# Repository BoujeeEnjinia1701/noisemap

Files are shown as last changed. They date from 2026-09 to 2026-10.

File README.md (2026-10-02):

# NoiseMap

     

**Area:** Smart Cities · **TRL:** 3 of 9 (proof of concept on paper) · **Value-engineering target:** $100 USD for the NoiseMap parts, estimated $72 (FieldNode core costed separately) · **Difficulty:** 2 of 5

A sound level meter node that records decibel levels only, never audio, to map traffic and nightlife noise.

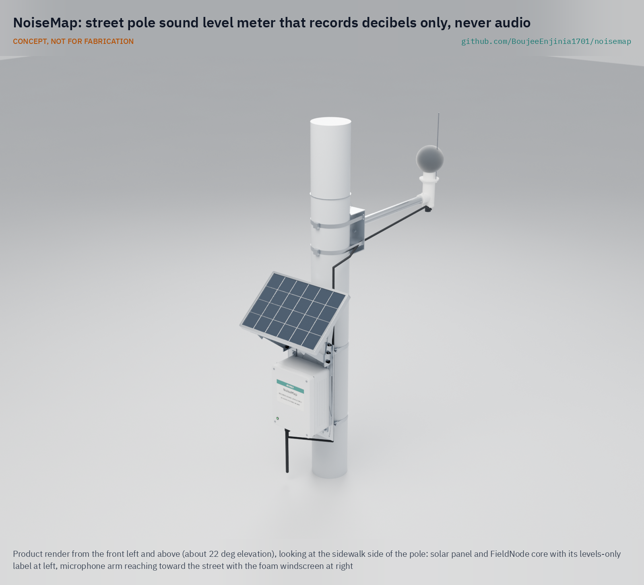
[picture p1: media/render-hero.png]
NoiseMap: street pole sound level meter that records decibels only, never audio, product render


[Exploded render](media/render-exploded.png) · [Detail render](media/render-detail.png) · [Interactive 3D model](media/viewer.html) · [Concept blueprint (PDF)](media/concept-blueprint.pdf) · [General arrangement NSM-DWG-001 (PDF)](cad/drawings/NSM-DWG-001.pdf) · [Calculations NSM-CAL-001](docs/04-calcs/01-sizing.md) · [Prototype build plan](docs/05-build-plan.md) · [Design decisions](docs/06-design-decisions.md) · [Review note](docs/REVIEW.md)

## Concept rationale

Most noise disputes turn on one question: how loud was it, and when? A sound level meter answers that with a few numbers per second; it does not need to keep any sound. NoiseMap puts a digital MEMS microphone and a small processor in a head about 4 m above the street, turns the sound into A- and C-weighted levels on the spot, and passes only those levels to the lab's standard FieldNode solar and LoRaWAN core. The head firmware sends levels only, and it is open and published with a build hash, so residents, venues and the city can check for themselves that the street is not being listened to.

It is open and garage-buildable because the people who most need the evidence, residents' groups and small city noise teams, cannot buy certified monitoring terminals by the dozen. A MEMS microphone, a microcontroller board, a printed housing, a foam windscreen, an arm and a street pole adapter cost about $72 on top of the FieldNode core, and the open firmware lets anyone check that the node measures levels and nothing else.

## Burning platform

Noise is one of the largest environmental health burdens in cities. In the EU about 92 million people are exposed to harmful road traffic noise, and long-term transport noise is linked to about 66,000 premature deaths and about 50,000 new cases of cardiovascular disease a year ([EEA](https://www.eea.europa.eu/en/topics/in-depth/noise)). The WHO recommends keeping road traffic noise below 53 dB Lden and 45 dB Lnight ([EEA, citing WHO 2018](https://www.eea.europa.eu/publications/health-risks-caused-by-environmental)), stricter than the 55 dB Lden threshold used for EU reporting.

Yet official noise maps are mostly modeled and, in the EU, reviewed only every five years ([Directive 2002/49/EC](https://eur-lex.europa.eu/legal-content/EN/TXT/HTML/?uri=CELEX:32002L0049)), while complaints pile up without measurements behind them. By 2018 New York City's 311 line had logged more than 2.3 million noise complaints since 2010, more than for any other issue ([Bello et al., *Communications of the ACM*, 2018](https://arxiv.org/pdf/1805.00889)).

## Where it could be used

### By industry

| Industry | Use |
| --- | --- |
| Municipal environmental health | Continuous levels to check complaints and target enforcement in nightlife districts |
| Transport and road authorities | Before and after evidence for speed limits, low-noise surfaces and truck routes |
| Hospitality licensing and night-time economy | Shared, trusted data for late-licence conditions between venues and residents |
| Construction | Monitoring agreed noise limits at site boundaries near homes |
| Public health research | Open level data linked to sleep and cardiovascular studies |
| Community groups and citizen science | Independent, inspectable evidence for council meetings and planning hearings |

### By country or region

| Country or region | Why it matters there |
| --- | --- |
| European Union | About 92 million people are exposed to harmful road traffic noise ([EEA](https://www.eea.europa.eu/en/topics/in-depth/noise)); strategic maps are modeled and updated every five years, so street-level measurements add what the maps miss. |
| United States | The EPA set 55 dB outdoors as the level that prevents interference and annoyance in 1974 ([US EPA](https://www.epa.gov/archive/epa/aboutepa/epa-identifies-noise-levels-affecting-health-and-welfare.html)); noise was New York City's most common 311 complaint when SONYC was described in 2018 ([Bello et al.](https://arxiv.org/abs/1805.00889)). |
| France (Paris region) | Bruitparif already deploys sensors in lively Paris neighborhoods and on construction sites ([Bruitparif](https://www.bruitparif.fr/la-meduse/)); an open, low-cost node could extend coverage to smaller towns. |
| India | The national real-time noise network launched in 2011 with 35 stations in seven metros, five terminals per city, with expansion to 25 cities planned ([Press Information Bureau, Government of India](https://www.pib.gov.in/newsite/erelcontent.aspx?relid=71212&reg=3&lang=2)); a few fixed terminals per city leave most streets unmeasured. |
| Sub-Saharan Africa (Nigeria) | The UN Environment Programme lists Ibadan among the cities worldwide where acceptable noise levels are surpassed ([UNEP, Frontiers 2022](https://www.unep.org/news-and-stories/press-release/deadly-wildfires-noise-pollution-and-disruptive-timing-life-cycles)); a low-cost open node can give such cities measured data. |
| Southeast Asia (Thailand, Vietnam) | Bangkok and Ho Chi Minh City are also on UNEP's list of cities where acceptable noise levels are surpassed ([UNEP, Frontiers 2022](https://www.unep.org/news-and-stories/press-release/deadly-wildfires-noise-pollution-and-disruptive-timing-life-cycles)). |

## What sparked the idea

The idea traces back to Stratumseind, a nightlife street in Eindhoven, the Netherlands, which the municipality and the Dutch Institute for Technology, Safety & Security (DITSS), with the police and local businesses, turned into a living lab. The lab tested acoustic sensors that locate breaking glass and fireworks and recognize voices under high stress, to spot rising aggression ([The Hague Security Delta](https://securitydelta.nl/services/innovation/living-labs/stratumseind)). Leon Verver, director of DITSS, said, "We are not listening in on people or record what they're saying" ([The Next Web, 2018](https://thenextweb.com/the-next-police/2018/06/08/1128392/)). People on the street had to take that on trust, and legal research on the lab argued that such collective monitoring can still limit what individuals do, even without identifying anyone ([Galič, *Ars Aequi*, 2019](https://www.researchgate.net/publication/333673572_Surveillance_privacy_and_public_space_in_the_Stratumseind_Living_Lab_the_smart_city_debate_beyond_data)). NoiseMap starts from the opposite end: measure loudness only, and publish the firmware so that residents can check the claim instead of trusting it.

## Problem

Noise harms sleep and health, but cities measure it rarely and residents' complaints lack data. Official maps are modeled averages, certified monitors are few and costly, and any microphone on a pole raises the fear of eavesdropping.

## Concept

A sound level meter node that records decibel levels only, never audio, to map traffic and nightlife noise.

Full design precis: [docs/02-concept.md](docs/02-concept.md)

TRL 3 calculations ([NSM-CAL-001](docs/04-calcs/01-sizing.md), paper estimates): 12.2 mW average draw, 53 days without sun on the standard FieldNode cell, a measuring range of 34.9 to 113 dBA (27.9 dBA at the low end with the IM72D128 microphone), a 22-byte record every 15 minutes, an estimated $72 of NoiseMap parts against a $100 value-engineering target and about $211 for a full node with the FieldNode core. Made constructable (sawn V-blocks, a bent sheet arm saddle with two bands, fixings throughout), the node weighs 3.45 kg, within the 3.5 kg of R10 (relaxed from 3 kg), and an automatic interval rule keeps airtime within fair use at slow data rates; accuracy, measuring range and frequency response remain at risk. See the [requirements](docs/03-requirements.md) and the decision records [NSM-DDR-001](docs/decisions/0001-trl2-review-decisions.md), [NSM-DDR-002](docs/decisions/0002-recommendations-accepted.md) and [NSM-DDR-003](docs/decisions/0003-design-for-construction.md).

## Key components

- Digital MEMS microphone on an adapter board that takes an ICS-43434 or an IM72D128, in a printed head, pointing up
- Level processor in the head computing A- and C-weighted levels once a second; audio stays in its RAM
- Standard FieldNode core: IP65 enclosure, 6 W panel, one LiFePO4 cell, MPPT charger and LoRaWAN radio
- 90 mm foam windscreen with bird spike
- Aluminum arm on a bent sheet saddle with its own two band clamps, and street pole V-blocks for 60 to 140 mm poles that fit the FieldNode back plate; no drilling of the pole

The priced bill of materials is in [bom/bom.csv](bom/bom.csv); the parametric model is [cad/src/model.py](cad/src/model.py), with STEP files in `cad/step/`.

## Building the prototype

The [prototype build plan](docs/05-build-plan.md) (NSM-BLD-001) shows how to make each component and fit it to the next, with a making sketch for every made part and a picture for every assembly step. The FieldNode core is built to its own plan and gets two larger V-blocks sawn from aluminium bar in place of its own; the arm saddle is bent from sheet by a local shop; the head and its cap are printed in ASA; the rest is bought. The work needs basic metalwork, 3D printing and fine soldering, and no certified trade. Every decision is indexed in the [design decisions register](docs/06-design-decisions.md).

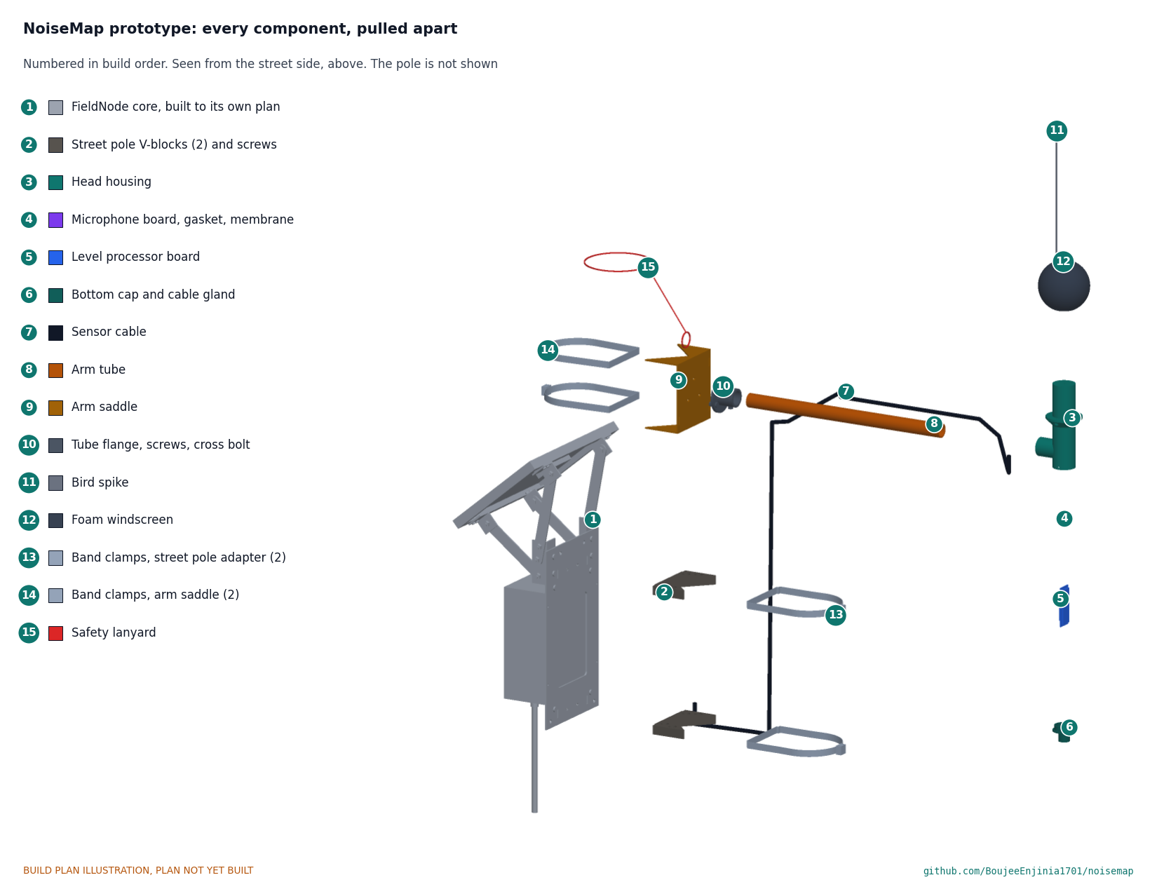
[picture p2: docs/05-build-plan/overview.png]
NoiseMap prototype: every component pulled apart and numbered in build order


## Safety

> Installing on a street pole is work at height beside traffic. The node contains a LiFePO4 cell of about 19 Wh: fuse it and charge only within the maker's temperature limits. Fit a safety lanyard to the microphone arm. Readings are indicative, not certified measurements.
>
> Privacy by design: no images, audio recordings or personal identifiers leave the device; only sound levels are stored or sent. The guarantee rests on the open head firmware and its published build hash. Check local data protection law before any deployment. Street furniture and pole mounts must be installed only with the asset owner's permission, by trained crews, with fall protection and traffic management as local rules require.

## Repository layout

| Folder | Contents |
| --- | --- |
| `docs/` | Problem, concept, requirements, calculations and design decisions |
| `cad/src/` | build123d Python source, the source of truth for all geometry |
| `cad/step/`, `cad/stl/` | Exported models for FreeCAD, other CAD tools and printing |
| `cad/drawings/` | 2D sketches and dimensioned drawings |
| `bom/` | Bill of materials |
| `electronics/` | KiCad schematics and PCB layouts |
| `firmware/` | Microcontroller code |
| `media/` | Renders, perspectives and photos |
| `build-log/` | Dated prototyping notes |

## Documentation

Controlled documents follow the portfolio [documentation standard](.kit/STANDARDS.md). Each carries a document ID (NSM-PRC-001 for the precis), a version and a revision history. Branded PDFs are built with `python .kit/render.py` and attached to GitHub Releases when a document is tagged, for example `NSM-PRC-001/v1.0`.

## Credits

Designed by Amish Chadha. See [CONTRIBUTORS.md](CONTRIBUTORS.md) for roles. To cite this design, use [CITATION.cff](CITATION.cff) (GitHub shows it as "Cite this repository").

AI assistance (Claude) was used to accelerate concept renders, prototype documentation and first-pass sizing calculations. Design direction and all decisions are Amish Chadha's, recorded in this repository's decision records (`docs/decisions/`).

## Licenses

- **Hardware** (CAD, drawings, BOM, electronics): [CERN-OHL-S v2](LICENSE)
- **Software** (firmware, scripts, notebooks): [MIT](LICENSE-SOFTWARE)

A project of the [Design Molecule](https://designmolecule.com) lab.

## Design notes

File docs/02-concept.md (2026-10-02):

---
doc_id: NSM-PRC-001
title: NoiseMap design precis
project: NoiseMap
doc_type: Design precis
version: "0.6"
status: Draft
date: '2026-10-02'
author: Amish Chadha
license: CERN-OHL-S-2.0
revisions:
- version: "0.1"
  date: '2026-09-25'
  author: Amish Chadha
  change: Initial scaffold
- version: "0.2"
  date: '2026-09-25'
  author: Amish Chadha
  change: Populate to TRL 2 (architecture, first-order numbers, safety, media)
- version: "0.3"
  date: '2026-09-25'
  author: Amish Chadha
  change: TRL 3; design choices adopted per NSM-DDR-001; numbers replaced by NSM-CAL-001 results; street pole adapter (BOM line 14) and parametric model added; FieldNode core at its TRL 3 figures
- version: "0.4"
  date: '2026-09-25'
  author: Amish Chadha
  change: Recommendations accepted by Amish (DDR-002)
- version: "0.5"
  date: '2026-10-01'
  author: Amish Chadha
  change: Design made constructable (NSM-DDR-003); mass, cost and arm figures from NSM-CAL-001 v0.3; budget as a value-engineering target
- version: "0.6"
  date: '2026-10-02'
  author: Amish Chadha
  change: M12 pinout and first co-design partner to approach, decided on 2026-10-02 (NSM-DEC-001)
---

# NoiseMap design precis

NoiseMap is a clamp-on street pole noise node. A digital MEMS microphone 4.0 m above the sidewalk feeds a small processor in the microphone head, which turns the sound into A- and C-weighted levels once a second and overwrites the audio within milliseconds. Only levels cross the cable to a standard FieldNode core, which sends a 22-byte record every 15 minutes over LoRaWAN. The TRL 3 calculations (NSM-CAL-001) give a design load of 12.2 mW, 53 days without sun and a range of 34.9 to 113 dBA (27.9 dBA with the IM72D128 microphone). The NoiseMap parts are estimated at $72.00 against a $100 value-engineering target, which covers them alone; a full node with the $139.00 FieldNode core is $211.00. Made constructable under NSM-DDR-003, the node weighs 3.45 kg, within R10's 3.5 kg (relaxed from 3 kg under NSM-DDR-002). How to build it is in the prototype build plan, NSM-BLD-001.

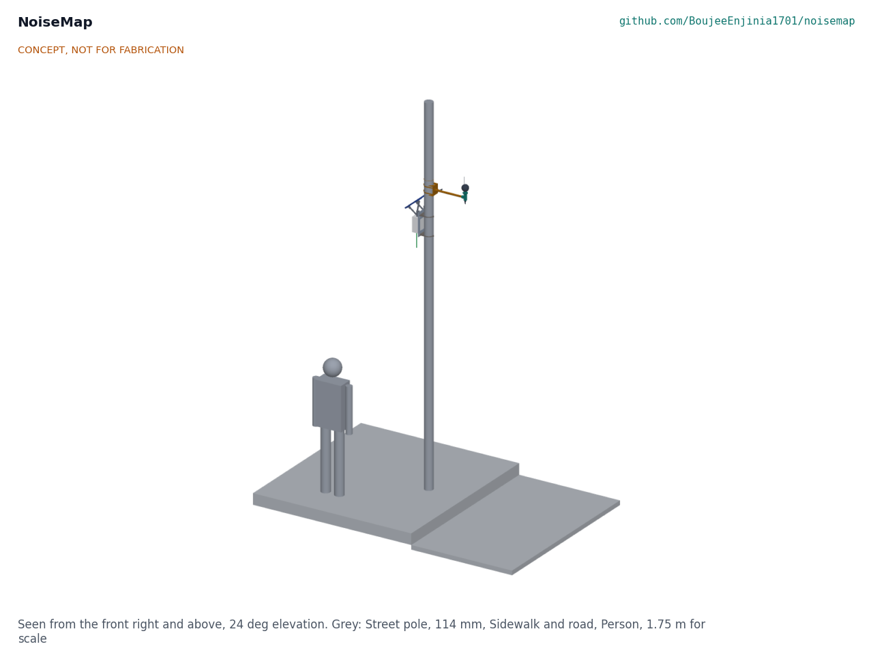
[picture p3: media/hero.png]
Figure 1. NoiseMap on a street pole with a 1.75 m person for scale


## How it works

1. **Sense.** The MEMS microphone, port facing up under the head's acoustic port and inside a foam windscreen, streams 24-bit samples at 48 kHz to the level processor, over I²S from an ICS-43434 or PDM from an IM72D128.
2. **Weight and integrate.** The processor applies A and C weighting, a low-frequency equalizer for the microphone roll-off and a Z-weighted wind band below 40 Hz as digital filters, then computes each second LAeq,1s, the Fast time-weighted maximum and minimum (LAFmax, LAFmin), LCeq,1s and the wind band level. Samples live in a small RAM buffer that is overwritten about every 20 ms. The load is about 13 % of a 48 MHz core.
3. **Hand over levels only.** Once a second the head sends a 12-byte frame to the FieldNode core over a 9,600 baud UART in the M12 cable. The head has no data storage and no radio.
4. **Summarize.** The FieldNode core builds a 15-minute record: fifteen 1-minute LAeq values, the 15-minute LAeq, LAFmax and LAFmin, L10 and L90 (from the 900 one-second values), LCeq and a status byte with the wind flag, 22 bytes in all.
5. **Send.** The core sends each record over LoRaWAN to the lab's TwinKit gateway, a city server or The Things Network, and stores it in flash with a time stamp if the link is down. At SF10 and slower the core lengthens the interval automatically to stay within The Things Network's 30 s a day: 24 min at SF10, 48 min at SF11, 87 min at SF12; the record stays 22 bytes, and its fifteen sub-interval LAeq values each span a fifteenth of the interval (NSM-DDR-002). Night indicators (Lnight, Lden) and the rain flag are computed on the server.

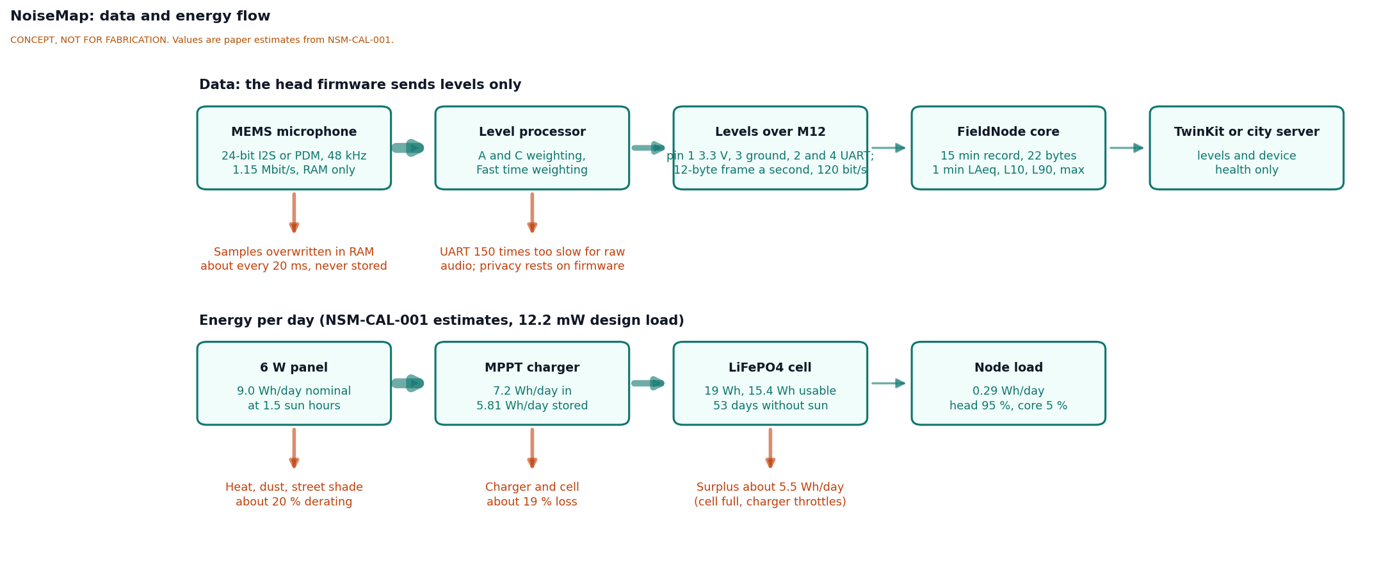
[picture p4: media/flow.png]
Figure 2. Data and energy flow (estimates from NSM-CAL-001)


## Main components

Table 1. Main components. Numbers match the exploded view (Figure 3), `cad/src/model.py` and `bom/bom.csv`. Lines 1 to 6 are the FieldNode core, costed in the FieldNode repo.

| # | Component | Choice | Notes |
| --- | --- | --- | --- |
| 1 | FieldNode enclosure | IP65 polycarbonate box 150 x 90 x 200 mm with vent and glands | From FieldNode, unchanged |
| 2 | FieldNode power and radio board | MPPT charger with cold-charge lockout, STM32WL-class LoRaWAN module, SPI flash, whip antenna, two M12 ports | From FieldNode, unchanged |
| 3 | LiFePO4 cell | One 3.2 V, 6 Ah cell | FieldNode standard; 53 days at the NoiseMap load |
| 4 | Solar panel | 6 W, 290 x 200 mm, 40° tilt, doubling as a hood | FieldNode standard |
| 5 | Panel tilt bracket | Flat-bar posts and struts | From FieldNode |
| 6 | FieldNode pole mounting kit | Back plate 180 x 320 x 3 mm | Only the plate is used on street poles |
| 7 | Microphone arm | 25 x 2 mm aluminum tube, 383 mm, in a bought tube flange on a saddle bent from 2.5 mm aluminum sheet, held by its own two band clamps | Puts the microphone 0.45 m from the pole face; turns independently of the core |
| 8 | Microphone head housing | Printed ASA tube 40 mm OD x 150 mm, 3 mm acoustic port, drip skirt, hydrophobic membrane | NSM-DDR-001 D13 |
| 9 | MEMS microphone | Adapter board for an ICS-43434 (I²S, 65 dB SNR, [TDK InvenSense](https://invensense.tdk.com/products/ics-43434/)) or an IM72D128 (PDM, 72 dB(A) SNR, [DNMS](https://github.com/hbitter/DNMS)) | D3; the ICS-43434 is listed end of life |
| 10 | Level processor | Cortex-M4F class low-power board (STM32L4 class) with I²S and PDM inputs and read-out protection | D4 |
| 11 | Windscreen and bird spike | 90 mm open-cell foam ball bored 41 mm, stainless spike | Replace about yearly (estimate) |
| 12 | Sensor cable | M12 5-pin, about 1.5 m, 3.3 V, ground and UART | FieldNode port: pin 1 at 3.3 V, pin 3 ground, pins 2 and 4 the UART pair, on FieldNode's candidate pinout, which NoiseMap asks FieldNode to adopt (decided 2026-10-02) |
| 14 | Street pole adapter | Two 90° aluminum V-blocks 112 x 63 x 16 mm sawn from bar, on the FieldNode back plate's own screw holes, and two long stainless bands through its slots | Seats 60 to 140 mm poles; replaces FieldNode's 40 to 60 mm V-blocks |

Line 13 of the BOM (fasteners, safety lanyard, ties, tape) has no callout.

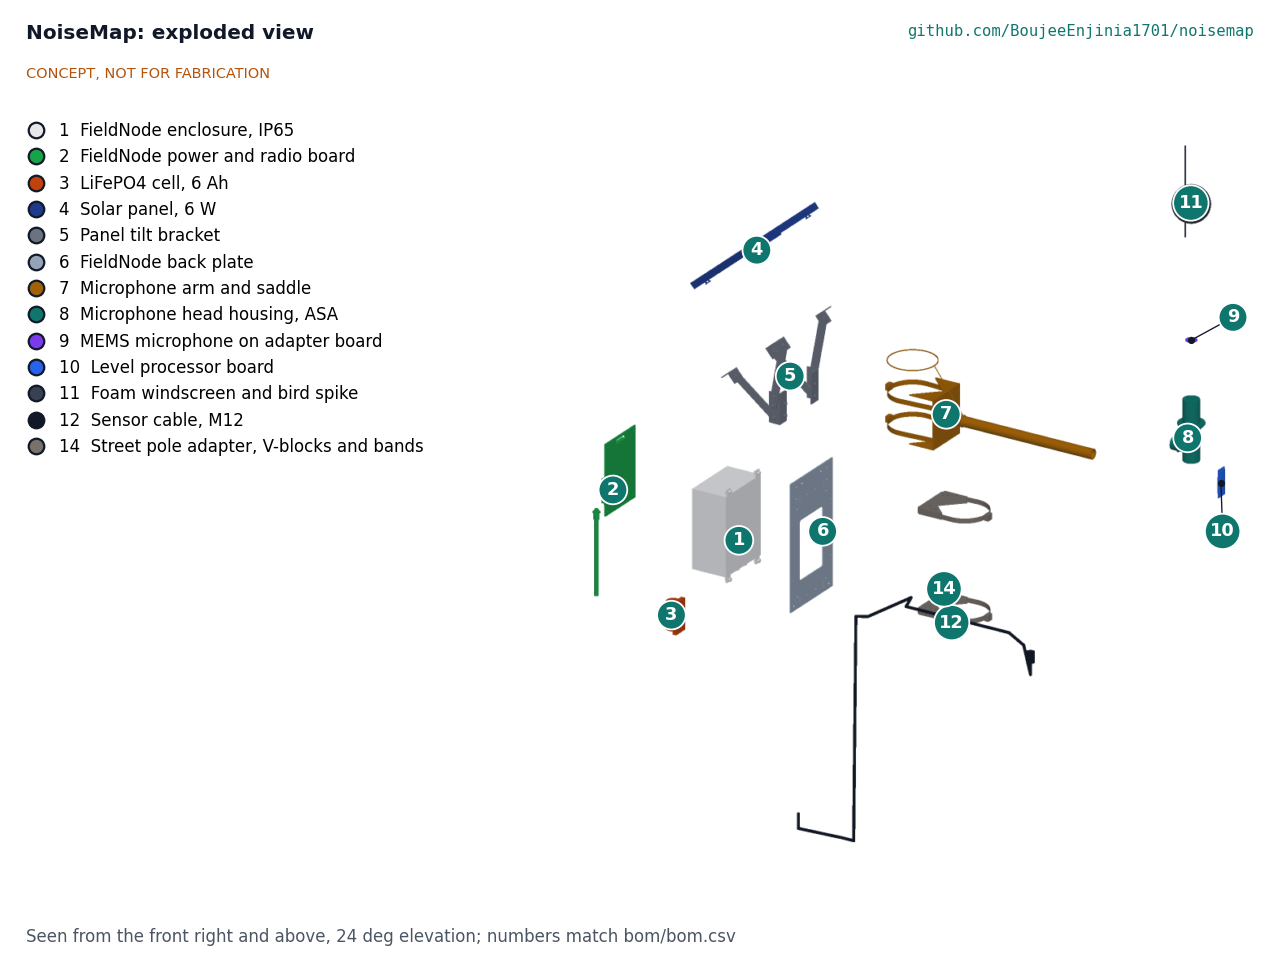
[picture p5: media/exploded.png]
Figure 3. Exploded view with BOM numbers


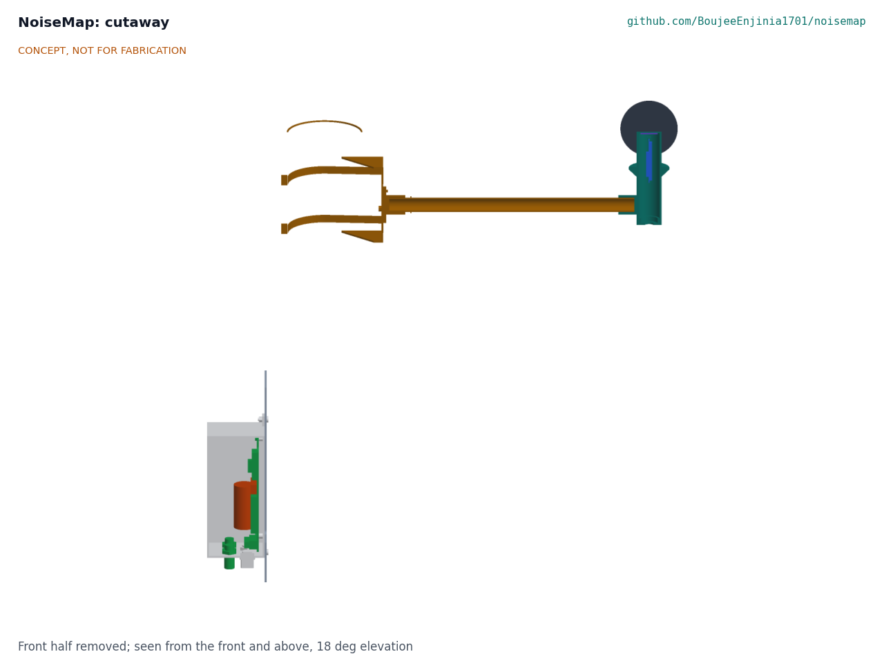
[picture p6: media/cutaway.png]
Figure 4. Cutaway: FieldNode enclosure with cell and board (lower left), microphone head with processor inside the windscreen (upper right)


The general arrangement is drawing NSM-DWG-001 Rev P3 (`cad/drawings/NSM-DWG-001.pdf`), generated from `cad/src/model.py`, which also exports STEP and STL files in `cad/step/` and `cad/stl/`.

## Key numbers

All values come from NSM-CAL-001 and are paper estimates.

Table 2. Key numbers.

| Quantity | Value | Requirement |
| --- | --- | --- |
| Microphone self-noise | 29.0 dBA (ICS-43434); 22.0 dBA (IM72D128) | |
| Measuring range | 34.9 to 113 dBA (ICS-43434); 27.9 to 113 dBA (IM72D128) | R4 at risk |
| Response at 63 Hz | -2.8 dB before equalizing; ±0.8 dB after, with ±20 % corner spread | R5 at risk |
| Acoustic port resonance | 36.2 kHz; +0.44 dB at 8 kHz | R5 |
| Expanded uncertainty | 2.9 dB on assumed terms; facade bias up to 2.4 dB | R3 at risk |
| Processor | 132 cycles per sample, 13.2 % of 48 MHz, 2.15 mA | |
| Node load from the cell | 12.2 mW, 0.29 Wh/day (22.6 mW upper bound) | 12 % of FieldNode's 100 mW allowance |
| Harvest at 1.5 peak sun hours | 5.81 Wh/day stored | R7 met on paper |
| Autonomy | 53 days; 37 days at -20 °C | R7 met on paper |
| Record and airtime | 22 bytes; 23.7 s/day at SF9 at 15 min; at most 30.0 s/day at SF10 to SF12 with the interval rule | R2 met; R12 met on paper |
| Link capacity | UART 7,680 bit/s (150 times too slow for raw audio, enough for a speech codec) | R1 rests on firmware |
| Mass on the pole | 3.45 kg for the constructable design | R10 met on paper at 3.5 kg; margin 0.05 kg |
| Wind at 35 m/s | Arm, head and windscreen 16 N; arm stress factor 24; clamp twist factor 4.2 | R10 met on paper |
| Parts cost | NoiseMap $72.00 against a $100 value-engineering target; FieldNode core $139.00; full node $211.00 | R13 met on paper |

The accuracy of the measurement depends on the membrane, the windscreen, diffraction round the head and reflections from nearby facades, none of which can be settled on paper.

## Key design choices

All of these are decided by Amish, 2026-09-25: go with recommendation (NSM-DDR-001, NSM-DDR-002).

- **Levels, never audio (D9).** The only data that leave the microphone head are levels once a second. The head has no data storage and no radio, and the firmware has no code path that writes or sends samples.
- **Where privacy comes from (D2).** The 9,600 baud cable is 150 times too slow for raw audio, but fast enough for a speech codec such as Codec 2 (700 to 3,200 bit/s), and the radio could carry about 31 s of such speech a day under fair use. The guarantee therefore rests on open, auditable head firmware with read-out protection and a published build hash. Public copy never claims privacy "by physics".
- **Processing in the head (D4).** Keeping the audio next to the microphone means the M12 cable only ever carries levels.
- **Standard FieldNode core (D10).** At 12.2 mW the node uses 12 % of FieldNode's allowance with its standard 6 W panel and one cell, and stays in credit on the hot clear days that stop FieldNode charging.
- **Microphone 4.0 m above the sidewalk, 0.45 m from the pole, pointing up (D11).** This matches noise-mapping practice; the pole adds only 0.25 dB by reflection. The arm has its own clamp, so the core can face the equator while the arm faces the street.
- **A and C weighting (D12)** with 15-minute records and 1-minute LAeq (D5).
- **Microphone part (D3).** A small adapter board takes either the ICS-43434 or the IM72D128; the IM72D128 gives 7 dB more margin at the quiet end.
- **Field calibration (D7).** Each node is checked with a shared 94 dB, 1 kHz calibrator at install and at each windscreen change, and compared with a class 1 reference meter at one site per deployment, which also sets the site's reflection correction.
- **Public notice (D8)** on each pole saying what is measured, with a link to this repository.
- **R10 at 3.5 kg (O2).** Under NSM-DDR-003 the V-blocks are sawn from 16 mm bar with drilled holes and the arm saddle is bent from sheet; the node is 3.45 kg, so the 0.05 kg margin is thin and any added part (an anemometer, a heavier windscreen) needs a mass check.
- **Level-based wind flag (O3).** Wind is flagged from the Z-weighted band below 40 Hz and its one-second spread, with no added sensor; rain is flagged on the server from weather data. The threshold needs a field comparison with an anemometer, which is TRL 4 work and on hold.
- **Interval rule at slow data rates (O4).** The core lengthens the reporting interval automatically at SF10 to SF12, following FieldNode's interval item, so R12 is met at every spreading factor.

## Safety

> **Safety:** Installing on a street pole is work at height next to traffic. Install only with the pole owner's permission, by trained crews, with fall protection and traffic management as local rules require. Keep clear of overhead power lines and street-light wiring, and never open a pole's electrical hatch. The node adds about 97 N of wind load at 3.5 to 4 m in a 35 m/s gust; the pole owner should confirm the pole can take it.

> **Safety:** The node contains a LiFePO4 cell of about 19 Wh. Fuse the cell, charge only within the cell maker's temperature limits (FieldNode's cold-charge lockout applies), and do not install a node with a swollen or damaged cell.

> **Safety:** A falling part from 4 m can injure people below. Fit a secondary safety lanyard to the microphone arm, tighten the bands to a stated torque (the clamp margins in NSM-CAL-001 assume 1,000 N preload), and check the clamps after the first storm.

> **Safety:** Do not test the node near its upper range with loudspeakers or calibrators at close range without hearing protection.

**Privacy.** No images, audio recordings or personal identifiers leave the device; only sound levels are stored or sent. The guarantee rests on the published head firmware and its build hash. Check local data protection law before any deployment, and put a notice on the pole saying what is measured and where the design is documented.

**Use of the data.** NoiseMap readings are indicative. They are not certified measurements and must not be presented as legal evidence without a co-located certified instrument.

## Open questions

- First co-design partner and street (NSM-DDR-001 O1): decided 2026-10-02; the first candidate to approach is a city environmental noise team or a university acoustics group that can put a Class 1 reference sound level meter beside the node on the test street; a Sensor.Community group is a useful second contact for volunteer hosts. Not yet agreed.
- Beyond TRL 3, on hold: measure the response of the chosen microphone in the printed head with membrane and windscreen, the windscreen insertion loss, the wind-band threshold against an anemometer, and the site reflection correction.

Concept media: [blueprint sheet](../media/concept-blueprint.pdf), [interactive 3D model](../media/viewer.html).

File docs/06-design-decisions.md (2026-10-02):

---
doc_id: NSM-DEC-001
title: NoiseMap design decisions register
project: NoiseMap
doc_type: Design decisions register
version: "0.2"
status: Draft
date: '2026-10-02'
author: Amish Chadha
license: CERN-OHL-S-2.0
revisions:
  - version: "0.1"
    date: '2026-10-01'
    author: Amish Chadha
    change: Register opened with the build plan; budget treated as a value-engineering target
  - version: "0.2"
    date: '2026-10-02'
    author: Amish Chadha
    change: Amish approved the recommendations for open decisions 1 to 5 (NSM-DDR-003 accepted); moved to decisions made
---

# NoiseMap design decisions register

Every design decision still to be made, and every decision made, in one place. Each decision is argued in full in its decision record under `docs/decisions/`; this register is the index Amish works from. The build plan (`docs/05-build-plan.md`) describes the design as it stands and does not list open decisions.

## Open decisions

None. All open decisions were decided on 2026-10-02.

## To confirm when parts are bought

| # | What to confirm | Why it matters | Source |
| --- | --- | --- | --- |
| 1 | The tube flange's three holes fall on a 45 mm circle, its base is 60 mm across or less, and its socket takes a 25 mm tube 25 mm deep | The saddle web holes and the band clearance (4 mm) assume it | NSM-DDR-003, P4 |
| 2 | The processor board is no wider than 26 mm and no longer than 70 mm | It must fit the card guides printed in the head | NSM-DDR-003, P6 |
| 3 | The windscreen is a 90 mm ball and takes a 40 mm bore, or comes bored to 40 mm | The push fit on the head and the head's position in the ball | NSM-DDR-003, P8 |
| 4 | The band clamps close on poles from 60 to 140 mm, and the torque that gives 1,000 N of preload | The calculation note assumes that preload for every clamp margin | NSM-CAL-001, H6 |
| 5 | The membrane's acoustic transparency and size from its maker's datasheet | It sits in the sound path; its effect is part of R5 | NSM-DDR-001, D13 |
| 6 | 70 x 16 mm aluminium bar is stocked; if only 20 mm is, the blocks gain about 0.11 kg | The R10 margin is 0.05 kg | NSM-CAL-001, H2b |
| 7 | The FieldNode back plate as built matches FND-DWG-101 (V-block screw holes 18 mm each side, band slots 51 mm each side, at 20 and 270 mm up) | The street pole V-blocks use those holes and slots | NSM-DDR-003, P2 |

## Value engineering

Value-engineering target: USD 100 for the NoiseMap parts (a hypothetical control target, not a limit). Estimated cost of the constructable design: USD 72.00 (USD 28.00 under the target). The full node with the FieldNode core, which is costed in the FieldNode repository, is USD 211.00. Main cost drivers and savings worth trying:

- The largest NoiseMap lines are the arm and saddle with its flange and two bands (USD 16), the street pole adapter (USD 10), the sensor cable and gland (USD 9), the windscreen and spike, the level processor and the fixings (USD 8 each).
- Making the design constructable added USD 10 (two-band saddle and tube flange USD 6, fixings and lanyard USD 2, cable gland USD 1, head cap USD 1). The FieldNode core rose from USD 126 to USD 139 under its own design for construction.
- Savings worth trying: a printed or folded tube socket in place of the bought flange (about USD 3); one band size bought in a box for all four bands; an M12 cable with a moulded strain relief in place of the separate gland; the processor and microphone on one board once the head design settles (TRL 4 work).

## Decisions made

| Date | Decision | Decided by | Record |
| --- | --- | --- | --- |
| 2026-09-25 | TRL 2 review items D1 to D13: budget scope (NoiseMap parts only), privacy resting on open firmware, dual-footprint microphone, processing in the head, 15-minute records, shared calibrator, public notice, standard FieldNode core, microphone 4.0 m up and 0.45 m off the pole, A and C weighting, printed ASA head | Amish: "i accept all your recommendations, go with them across all repos." | NSM-DDR-001, NSM-DDR-002 |
| 2026-09-25 | R10 relaxed to 3.5 kg with lighter V-blocks and saddle (O2); level-based wind flag (O3); interval rule at slow data rates (O4) | Amish, same instruction | NSM-DDR-002 |
| 2026-09-30 | FieldNode core made constructable (the core NoiseMap now uses) | Amish: "i accept your recommended changes on design that are currently being sent across for my approval" | FieldNode FND-DDR-003 |
| 2026-09-30 | Make every design physically buildable while drawing the build plan; keep open decisions out of the build plan | Amish: "If you are realising that the design cannot be built as per concept - fix the design assumptions to match and be physically feasible as you draw the illustrations." | NSM-DDR-003 (changes accepted on 2026-10-02, below) |
| 2026-10-01 | `budget_usd` is a value-engineering target, not a limit | Amish: "the budgets are a hypothethical control target to ensure we are thinking along a value engineering lens" | This register, NSM-CAL-001 v0.3 |
| 2026-10-02 | Design for construction accepted: the changes P1 to P11, as made | Amish: "i approve your recommendations for all 555 open decisions." | NSM-DDR-003 |
| 2026-10-02 | Bird spike: the side spike in the skirt boss, 26 mm off the microphone axis, as modelled; the response is measured with and without it at TRL 4 | Amish: "i approve your recommendations for all 555 open decisions." | NSM-DDR-003, A1 |
| 2026-10-02 | R10 mass margin of 0.05 kg accepted; the prototype is weighed at TRL 4 | Amish: "i approve your recommendations for all 555 open decisions." | NSM-DDR-003, A2 |
| 2026-10-02 | First co-design partner to approach: a city environmental noise team or a university acoustics group that can put a Class 1 reference sound level meter beside the node on the test street; a Sensor.Community group is a useful second contact for volunteer hosts | Amish: "i approve your recommendations for all 555 open decisions." | NSM-DDR-001, O1 |
| 2026-10-02 | M12 sensor port pinout: ask FieldNode to adopt its own candidate pinout for both ports (pin 1 switched rail, pin 2 data A, pin 3 ground, pin 4 data B, pin 5 analog); NoiseMap uses pin 1 at 3.3 V, pin 3 ground and pins 2 and 4 for the UART pair | Amish: "i approve your recommendations for all 555 open decisions." | FieldNode FND-DDR-001, O2 |

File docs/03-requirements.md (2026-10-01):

---
doc_id: NSM-REQ-001
title: NoiseMap requirements
project: NoiseMap
doc_type: Requirements
version: "0.5"
status: Draft
date: '2026-10-01'
author: Amish Chadha
license: CERN-OHL-S-2.0
revisions:
- version: "0.1"
  date: '2026-09-25'
  author: Amish Chadha
  change: Initial scaffold
- version: "0.2"
  date: '2026-09-25'
  author: Amish Chadha
  change: Populate to TRL 2 (numbered, measurable requirements with targets and concept status)
- version: "0.3"
  date: '2026-09-25'
  author: Amish Chadha
  change: TRL 3; R13 redefined to the NoiseMap parts under NSM-DDR-001 D1; R2 metric set adopted (D5); status column from NSM-CAL-001
- version: "0.4"
  date: '2026-09-25'
  author: Amish Chadha
  change: Recommendations accepted by Amish (DDR-002)
- version: "0.5"
  date: '2026-10-01'
  author: Amish Chadha
  change: Status figures from NSM-CAL-001 v0.3 (constructable design, NSM-DDR-003); R13 stated against the value-engineering target
---

# NoiseMap requirements

These requirements are targets for concept review and must be revised with a co-design partner before the design is frozen. The metric set (R2) and the budget scope (R13) follow NSM-DDR-001 D5 and D1; the relaxed mass limit (R10), the wind flag method (R11) and the interval rule (R12) follow NSM-DDR-002. All were decided by Amish, 2026-09-25: go with recommendation. Status is taken from the TRL 3 calculation note NSM-CAL-001 v0.2; "met on paper" means met by calculation only. None is not met; three are at risk (R3, R4, R5), four can be settled only by test (R8, R9, R11, R14), and eight are met on paper or by design.

Design case: one node on a 114.3 mm street pole 0.45 m behind the curb, microphone 4.0 m above the sidewalk and 0.45 m from the pole face, in a mixed street with traffic by day and bars at night.

Table 1. Requirements.

| ID | Requirement | Target | Verification | Status (NSM-CAL-001) |
| --- | --- | --- | --- | --- |
| R1 | Privacy: no audio samples are stored or leave the microphone head; only levels cross the cable or the radio | No data storage in the head; cable carries levels only; head firmware published with a build hash and read-out protection | Design review, firmware audit, cable capture | Met by design; the guarantee rests on the firmware, since the cable could carry a speech codec (NSM-DDR-001 D2) |
| R2 | Reported metrics | Per 15 min: fifteen 1-minute LAeq, LAeq, LAFmax, LAFmin, L10, L90, LCeq, device status | Design review | Met by design (22 bytes per record) |
| R3 | Accuracy of LAeq,15min against a co-located class 1 meter | Within ±2 dB from 40 to 100 dBA, after field calibration | Side-by-side field test | **At risk**: expanded uncertainty 2.9 dB on assumed terms; facade bias up to 2.4 dB before a site correction |
| R4 | Measuring range | 35 to 110 dBA | Bench test with calibrator and reference source | **At risk**: ICS-43434 34.9 to 113 dBA (no margin); IM72D128 27.9 to 113 dBA |
| R5 | Frequency weighting | A and C weighting as defined in IEC 61672-1, within class 2 tolerances from 63 Hz to 8 kHz (goal) | Bench test against a reference meter | **At risk**: roll-off equalized to ±0.8 dB at 63 Hz; membrane, windscreen and head diffraction unknown |
| R6 | Time stamps | Each record time-stamped within 2 s of UTC | Design review (LoRaWAN network time) | Met by design |
| R7 | Energy | Energy neutral at 1.5 peak sun hours; 14 days without sun | Energy budget, bench test | Met on paper (5.81 Wh/day for 0.29 Wh/day; 53 days) |
| R8 | Ingress and weather | IP65 enclosure; microphone head survives driving rain; -20 °C to +50 °C | Spray test, thermal chamber | Not verifiable at TRL 3 |
| R9 | Calibration check | Field check with a 94 dB, 1 kHz calibrator in 10 min or less; offset stored on the node | Timed trial | Not verifiable at TRL 3 |
| R10 | Installation and mass | Two trained people, 45 min, no drilling or pole wiring; 60 to 140 mm poles; 3.5 kg or less (relaxed from 3 kg, NSM-DDR-002); withstands 35 m/s gusts | Timed trial, weighing, bracket calculation | Met on paper on mass (3.45 kg for the constructable design; margin 0.05 kg); wind met on paper; fit met by design; time not verifiable at TRL 3 |
| R11 | Contaminated data | Intervals with wind above about 5 m/s or heavy rain are flagged, wind by a level-based flag (no added sensor) and rain on the server from weather data (NSM-DDR-002) | Field comparison with a weather station | Not verifiable at TRL 3: method chosen; the threshold needs field data (TRL 4, on hold) |
| R12 | Radio use | Within EU868 1 % duty cycle and The Things Network fair use (30 s uplink per day); 15-minute interval at SF7 to SF9, lengthened automatically at SF10 to SF12 (NSM-DDR-002) | Airtime calculation | Met on paper: 23.7 s/day at SF9; 29.6, 29.6 and 30.0 s/day at 24, 48 and 87 min for SF10 to SF12 |
| R13 | Parts cost | NoiseMap parts (lines 7 to 14 of the BOM) at or under the $100 value-engineering target per node; the FieldNode core is costed in the FieldNode repo and the full node cost is stated | Priced BOM | Met on paper: NoiseMap parts $72.00, $28.00 under the target; full node $211.00 with the $139.00 FieldNode core |
| R14 | Service life | 5 years outdoors, with a yearly windscreen change and one battery change | Design review, UV-stable materials | Not verifiable at TRL 3 |
| R15 | Openness | Hardware, firmware, calibration method and data format published under the repo licenses | Design review | Met by design |

Table 2. Assumptions behind the targets.

| Assumption | Value | Source or basis |
| --- | --- | --- |
| Microphone height | about 4 m above the ground | 4.0 ± 0.2 m assessment height for EU strategic noise maps ([Directive 2002/49/EC, Annex I](https://eur-lex.europa.eu/legal-content/EN/TXT/HTML/?uri=CELEX:32002L0049)) |
| Quietest night level to resolve | about 35 dBA | Quiet residential street at night (estimate) |
| Loudest level to resolve | about 110 dBA | Close pass of a loud motorcycle or siren (estimate) |
| Peak sun hours, winter design case | 1.5 h | Mid-latitude winter (estimate) |
| Wind speed that spoils readings with a foam windscreen | about 5 m/s | Common practice (estimate, to be checked) |
| Microphone data | ICS-43434: 65 dB SNR, 120 dB SPL overload, 60 Hz to 20 kHz; IM72D128: 72 dB(A) SNR | ICS-43434 product page ([TDK InvenSense](https://invensense.tdk.com/products/ics-43434/)); IM72D128 from the DNMS README ([DNMS](https://github.com/hbitter/DNMS)) |
| Street pole diameter | 60 to 140 mm, design case 114.3 mm | Common lighting and signal poles (estimate) |

> **Safety:** Requirements R8 and R10 involve work at height beside traffic and a lithium cell. See the safety section of NSM-PRC-001.

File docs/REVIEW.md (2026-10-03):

# Review note: NoiseMap

## Session 2026-10-01: design for construction and build plan (kit 1.7.0)

Kit 1.7.0 installed (`.kit/`, `.claude/commands/`, root `CLAUDE.md`). Following Amish's approval of the build plan format on 2026-09-30 and his instruction "If you are realising that the design cannot be built as per concept - fix the design assumptions to match and be physically feasible as you draw the illustrations", the design was checked for constructability with build123d and made buildable. Every change is in `docs/decisions/0003-design-for-construction.md` (NSM-DDR-003, draft, made under Amish's 2026-09-30 instruction to make the design physically buildable; open for his review).

### Design changes made for construction

- FieldNode core: the old FieldNode massing model is replaced by the constructable FieldNode (FND-DWG-001 Rev P3, copied unchanged into `cad/src/fieldnode_core.py`), built to FND-BLD-001 without its small-pole V-blocks and bands.
- Street pole V-blocks: the milled, pocketed 110 x 60 x 40 mm blocks are replaced by 112 x 63 x 16 mm blocks sawn from bar with four drilled 14 mm holes, on the FieldNode plate's own V-block screw holes; the bands run under a rebate at each back corner and through the plate's own slots. No new holes in the FieldNode plate.
- Arm saddle: the milled 10 mm plate with one band (which had no path) is replaced by a channel bent from 2.5 mm sheet with a V in each flange and two bands through slots in its web.
- Arm fixings: a bought tube flange with an M5 cross bolt on the saddle; a socket printed on the head with an M4 cross bolt. The arm tube is now 383 mm; the microphone position is unchanged.
- Head: card guides for the processor; two bosses, two M2 screws and a 0.5 mm gasket for the microphone board (keeping the 3 mm, 0.5 mm front cavity); a printed bottom cap with an M16 cable gland; the drip skirt given a 45 degree cone so it prints without support.
- Windscreen bored 40 mm (was 41 mm, which nothing held); bird spike screwed into a boss on the skirt, 26 mm off the axis.
- Safety lanyard and the sensor cable route modelled.
- `cad/src/model.py` rewritten around components with 62 constructability checks (`python cad/src/model.py --check`), all passing. STEP and STL re-exported; NSM-DWG-001 Rev P2 to P3; concept media regenerated.

### Results

- Mass 3.45 kg against R10's 3.5 kg, margin 0.05 kg (unchanged). Arm stress factor 24 to 27; clamp twist factor 4.2 to 9.4; 96 N added to the pole.
- Cost: value-engineering target USD 100 for the NoiseMap parts; estimated cost of the constructable design USD 72.00 (USD 28.00 under the target); full node USD 211.00 with the USD 139.00 FieldNode core. `budget_usd` unchanged.
- Requirement status unchanged: 0 not met, 3 at risk (R3, R4, R5), 4 not verifiable at TRL 3, 4 met on paper, 4 met by design.

### Documents

- New: `docs/05-build-plan.md` (NSM-BLD-001 v0.1) with `docs/05-build-plan/` (overview, saddle blank, 8 joint close-ups, 12 step pictures, head wiring) and making sketches `cad/drawings/NSM-DWG-101` to `106` from `cad/src/build_plan_media.py`; `docs/06-design-decisions.md` (NSM-DEC-001 v0.1); NSM-DDR-003.
- Revised: NSM-CAL-001 v0.3 (mass, arm, clamp and cost re-run; FieldNode mass from FND-CAL-001 v0.3); NSM-PRC-001, NSM-REQ-001 and NSM-PRB-001 v0.5; `bom/bom.csv` and `bom/bom-notes.md`; `README.md` (links line, "Building the prototype", figures); `project.yaml` (`design_state: constructable`, evidence).

### Proposed, awaiting Amish

See the design decisions register: accept NSM-DDR-003; bird spike position (recommendation: the side spike as modelled, measured at TRL 4); the 0.05 kg mass margin (recommendation: accept, weigh at TRL 4); O1 co-design partner and street; the M12 pinout (FieldNode's open decision).

### Stale, to update on Amish's Mac

`media/render-hero.png`, `media/render-exploded.png`, `media/render-detail.png`, `media/card.png`, `media/social-preview.png` and `cad/src/product_model.py` still show the concept saddle, V-blocks, head and FieldNode bracket. The design changed visibly, so they need re-rendering with Blender.

### Recommended next step

Amish's review of NSM-DDR-003 and the open items in NSM-DEC-001. TRL 4 stays on hold; nothing here was built or bought.

## Session 2026-09-25: recommendations accepted

On 2026-09-25 Amish wrote: "i accept all your recommendations, go with them across all repos." Every NoiseMap item with a recommendation is now **decided by Amish, 2026-09-25: go with recommendation**. The decisions are recorded in `docs/decisions/0002-recommendations-accepted.md` (NSM-DDR-002 v0.1), and NSM-DDR-001 is revised to v0.2.

### Decisions applied and what changed

- **D1 to D13** (NSM-DDR-001): status changed from "adopted for TRL 3, open for review" to decided. No further repo change; D1 had already kept `budget_usd` at $100 and redefined R13 to the NoiseMap parts.
- **O2, R10 mass, option (c)**: V-blocks pocketed from top and bottom (4 mm walls, 8 mm web) and the arm saddle pocketed 6 mm deep in `cad/src/model.py`; R10 relaxed from 3 kg to 3.5 kg. While doing this, a modeling error was found and fixed: the P1 model centered the V notch on the apex, which cut each V-block down to a flat 10 mm plate. With true 90° V-blocks, the solid node would be 3.96 kg; pocketed it is **3.45 kg** (v0.1 figure 3.32 kg). R10 goes from **not met** to **met on paper**, with a margin of only 0.05 kg. STEP and STL re-exported; NSM-DWG-001 Rev P1 to **P2**; BOM lines 7 and 14 describe the pockets (prices unchanged).
- **O3, wind flag, option (a)**: level-based flag from the Z-weighted band below 40 Hz; rain flagged on the server. No anemometer. R11 stays not verifiable at TRL 3; the field comparison that sets the threshold is TRL 4 work, on hold.
- **O4, airtime at slow data rates**: the core lengthens the interval automatically, 24 min at SF10, 48 min at SF11, 87 min at SF12, keeping 15 min at SF7 to SF9. Airtime goes from 47.4 s/day at SF10 (over the 30 s limit) to at most 30.0 s/day at every spreading factor. R12 goes from **at risk** to **met on paper**.
- Budget: `budget_usd` unchanged at $100 (NoiseMap parts $62.00; full node $188.00 with the $126.00 FieldNode core).
- Pitch and problem: no rewording was recommended, so `project.yaml` pitch and problem are unchanged; `trl_evidence` now lists NSM-DDR-002.
- Documents: NSM-PRB-001, NSM-PRC-001 and NSM-REQ-001 v0.3 to v0.4; NSM-CAL-001 v0.1 to v0.2 (script and `results.csv` re-run); NSM-DDR-001 v0.1 to v0.2; NSM-DDR-002 v0.1 new. PDFs, drawing and concept media regenerated (footers now designmolecule.com).
- README: "What sparked the idea" rewritten around the Stratumseind living lab in Eindhoven, whose sound sensors also analyzed voices for aggression ([The Next Web, 2018](https://thenextweb.com/the-next-police/2018/06/08/1128392/); [Galič, 2019](https://www.researchgate.net/publication/333673572_Surveillance_privacy_and_public_space_in_the_Stratumseind_Living_Lab_the_smart_city_debate_beyond_data)); the earlier text about how the idea was chosen is removed. TRL 3 summary and key components updated.

### Requirement status (NSM-CAL-001 v0.2, not met first)

0 not met, 3 at risk, 4 not verifiable at TRL 3, 4 met on paper, 4 met by design (before: 1 not met, 4 at risk, 4 not verifiable, 2 met on paper, 4 met by design).

| ID | Status | Key number |
| --- | --- | --- |
| R3 Accuracy | At risk | Expanded uncertainty 2.9 dB on assumed terms; facade bias up to 2.4 dB |
| R4 Measuring range | At risk | ICS-43434 34.9 to 113 dBA; IM72D128 27.9 to 113 dBA |
| R5 Frequency weighting | At risk | Membrane, windscreen and head diffraction unknown |
| R8, R9, R11, R14 | Not verifiable at TRL 3 | Ingress, calibration time, wind threshold, service life |
| R7, R10, R12, R13 | Met on paper | 53 days without sun; 3.45 kg against 3.5 kg; at most 30.0 s/day airtime; NoiseMap parts $62.00 |
| R1, R2, R6, R15 | Met by design | R1 rests on firmware (D2) |

### Still awaiting Amish

1. **O1, first co-design partner and street.** No recommendation; stays "Proposed, awaiting Amish".

### Cross-repo actions (not made here)

- FieldNode: a street pole mounting variant for 60 to 140 mm poles (NoiseMap carries its own adapter, BOM line 14); would also serve other pole-mounted siblings.
- FieldNode: align the automatic interval rule (24, 48, 87 min at SF10 to SF12) with FieldNode's interval item 8, which lives in the FieldNode core firmware.
- FieldNode: agree the M12 port pinout (FieldNode O2); NoiseMap needs 3.3 V, ground and one UART pair.

### Notes

- The R10 margin is 0.05 kg. Shorter (30 mm) V-blocks, or leaving FieldNode's unused small-pole V-blocks off street-pole nodes, would add margin; suggestions only.
- In the exploded view the BOM legend runs close to the callouts on the left, as before.

### TRL 4

TRL 4 remains on hold by Amish's instruction. `trl: 3` and `trl_target: 3` are unchanged. No build, test, purchasing, PCB or firmware work was done; the wind threshold field comparison and the class 1 side-by-side are on hold.

## Session 2026-09-25: TRL 3

On 2026-09-25 Amish asked for this batch of repos to go through the usual process with the instruction "you know the drill, nothing gets past TRL 3". He has not reviewed this repo's TRL 2 items one by one, so every item that carried a recommendation is adopted as recommended for TRL 3 under Amish's 2026-09-25 instruction, open for his review. This session ran `/advance-trl3` on that basis and stopped at TRL 3.

### What was done

- `docs/decisions/0001-trl2-review-decisions.md` (NSM-DDR-001 v0.1, status proposed): D1 to D13 adopted as recommended for TRL 3, open for Amish's review; O1 to O4 left open.
- `docs/04-calcs/01-sizing.md` (NSM-CAL-001 v0.1), `docs/04-calcs/sizing.py` and `docs/04-calcs/results.csv`: measuring range, frequency response and port resonance, reflections and an uncertainty budget, processor load and power, energy, record format, airtime, link capacity for privacy, wind and rain flagging, arm stress, vibration and clamp margins, mass and cost, with a status for all 15 requirements. The script imports the model, reads the BOM and `project.yaml`, and prints every number the note quotes.
- `cad/src/model.py`: parametric build123d model (FieldNode core envelope per FND-DWG-001, street pole adapter for 60 to 140 mm poles, arm with saddle and band, head with acoustic port and front cavity, microphone board, processor, windscreen, cable). Exports `cad/step/` and `cad/stl/` for `noisemap-assembly`, `noisemap-head` and `noisemap-mount`, and runs a clash check (none beyond attachment contacts).
- `cad/src/sheets.py` and `cad/drawings/NSM-DWG-001.svg`, `.pdf`, `.png`: general arrangement at Rev P1, 1:10, marked "CONCEPT, NOT FOR FABRICATION" and "PRELIMINARY, NOT FOR FABRICATION". NSM-DWG-001 was free because the concept blueprint is NSM-DWG-010.
- `bom/bom.csv` (14 lines, all priced with a supplier or supplier type) and `bom/bom-notes.md`: the FieldNode core now uses the FieldNode BOM figures ($126.00); new line 14, street pole adapter. NoiseMap parts $62.00 against the $100 budget; full node $188.00.
- `cad/src/concept_media.py` now builds from `model.py`; all media re-rendered (hero, blueprint, cutaway, exploded, flow, `model.glb`, `viewer.html`) and checked by eye; temporary `media/_views*` folders deleted.
- NSM-PRB-001, NSM-PRC-001 and NSM-REQ-001 revised to v0.3; `README.md` (TRL badge, budget scope, TRL 3 numbers, privacy wording, links) and `project.yaml` (`trl: 3`, `trl_target: 3`, evidence list) updated. PDFs rebuilt in `docs/pdf/`.

### Requirement status (NSM-CAL-001, Table 4)

1 not met, 4 at risk, 4 not verifiable at TRL 3, 2 met on paper, 4 met by design.

| ID | Status | Key number |
| --- | --- | --- |
| R10 Installation and mass | **Not met** | 3.32 kg against 3 kg (3.10 kg with pocketed V-blocks and saddle); wind margins met on paper |
| R3 Accuracy | At risk | Expanded uncertainty 2.9 dB on assumed terms; facade bias up to 2.4 dB before a site correction |
| R4 Measuring range | At risk | ICS-43434 34.9 to 113 dBA (no margin at 35); IM72D128 27.9 to 113 dBA |
| R5 Frequency weighting | At risk | -2.8 dB at 63 Hz equalized to ±0.8 dB; port resonance 36.2 kHz; membrane and windscreen unknown |
| R12 Radio use | At risk | 23.7 s/day at SF9; 47.4 s/day at SF10 (over 30 s) |
| R8, R9, R11, R14 | Not verifiable at TRL 3 | Ingress, calibration time, wind threshold, service life |
| R7, R13 | Met on paper | 5.81 Wh/day for 0.29 Wh/day, 53 days without sun; NoiseMap parts $62.00 |
| R1, R2, R6, R15 | Met by design | R1 rests on firmware (D2) |

Key numbers: design load 12.2 mW (12 % of FieldNode's 100 mW allowance; 22.6 mW upper bound); processor 2.15 mA at 13.2 % load; 22-byte record; arm stress factor 24; clamp twist factor 4.2; 97 N added to the pole at 35 m/s.

Corrections to TRL 2 numbers: load 21 to 12.2 mW; autonomy 30 to 53 days; upper range 115 to 113 dBA (crest factor); mass 2.3 to 3.32 kg (FieldNode is now 2.41 kg, and the adapter was missing); cost $171 to $188 for a full node (FieldNode core $119 to $126, adapter added); the cable is too slow for raw audio but not for a speech codec.

### Decisions recorded (NSM-DDR-001)

Adopted as recommended for TRL 3 under Amish's 2026-09-25 instruction; now decided by Amish, 2026-09-25: go with recommendation (NSM-DDR-002): D1 budget covers the NoiseMap parts only, FieldNode core costed in FieldNode (`budget_usd` unchanged at 100; R13 redefined); D2 privacy stated as resting on open firmware, never "by physics"; D3 dual-footprint microphone adapter; D4 processing in the head; D5 15-minute records with 1-minute LAeq and the listed statistics; D6 wind flagging studied (NSM-CAL-001 section G); D7 shared calibrator and one side-by-side per deployment; D8 public notice on each pole; D9 to D12 precis choices (levels only, standard FieldNode core, microphone position, A and C weighting); D13 printed ASA head. No pitch or problem rewording was recommended, so neither changed.

### Still awaiting Amish (as of this session; O2 to O4 since decided, see the session above)

1. **O1, first co-design partner and street.** No preference stated.
2. **O2, R10 mass (new).** Options: (a) pocket the V-blocks and saddle (3.10 kg, still over); (b) relax R10 to 3.5 kg; (c) both. Recommendation: (c). Decided by Amish, 2026-09-25: go with recommendation; applied under NSM-DDR-002.
3. **O3, wind flag method (new).** Options: (a) level-based flag, no cost; (b) cup anemometer on FieldNode's second port (about $25, 0.15 kg). Rain flagged on the server in both. Recommendation: (a), with a field comparison to set the threshold. Decided by Amish, 2026-09-25: go with recommendation; applied under NSM-DDR-002 (field comparison on hold with TRL 4).
4. **O4, airtime at SF10 and slower (new).** Lengthen the interval automatically on The Things Network (24 min at SF10, 87 min at SF12), following FieldNode's item 8. Decided by Amish, 2026-09-25: go with recommendation; applied under NSM-DDR-002.

### Cross-repo consistency

- FieldNode (FND-CAL-001, FND-DDR-001): NoiseMap now uses FieldNode's TRL 3 figures: core $126.00, mass 2.41 kg, 100 mW design allowance, 4.0 mWh/day core, 7.75 Wh/day worst-month harvest, two M12 5-pin ports with one switched rail each, 15 min default. No conflict on power or radio. FieldNode's review listed NoiseMap at $119; that figure is now $126.00 here, which removes the discrepancy it noted.
- Conflict to raise with FieldNode, not edited there: FieldNode's mount seats 40 to 71 mm poles, and street poles need 60 to 140 mm, so NoiseMap adds its own adapter (line 14). A street pole kit variant in FieldNode would serve AirStreet, CurbCount and other pole-mounted siblings too.
- FieldNode's sun shield (its review item 4) matters little to NoiseMap: at 0.29 Wh/day the node stays in credit on FieldNode's hot clear day (0.8 Wh clean, 0.3 Wh dusty) without it.
- The pinout of the M12 port is still FieldNode O2; NoiseMap needs 3.3 V, ground and one UART pair.
- CityTwin assumes 96 NoiseMap uplinks a day; unchanged at 15 min. TwinKit's airtime figures (sized for 20-byte payloads) agree with Table 3 of NSM-CAL-001 at SF9 (246.8 ms); the 35-byte NoiseMap frame is slightly longer at SF7 and SF10.
- LampNode proposes hosted 12 V power on lighting poles as an option for NoiseMap; NoiseMap stays on FieldNode solar, which LampNode's recommendation (a) allows.

### Safety concerns

- Work at height beside traffic when installing; pole owner's permission, trained crews, traffic management.
- Clamp preload (assumed 1,000 N) carries every wind and slip margin; installers need a torque figure. The node adds about 97 N of wind load at 3.5 to 4 m that the pole owner should check.
- Falling parts from 4 m: safety lanyard on the arm; the arm and head may vibrate near 70 Hz in 9 to 14 m/s winds.
- LiFePO4 cell (about 19 Wh): fusing and the FieldNode 0 to 45 °C charge lockout.
- Hearing: bench checks near the upper range need hearing protection.
- Privacy: the links could carry a speech codec, so the head firmware, its read-out protection and build hash are safety-critical for public trust; any firmware change needs a fresh privacy review.
- Misuse of data: readings are indicative and must not be presented as certified measurements.

### Gaps and notes

- Citations: the ICS-43434 figures were checked on the TDK page (SNR 65, sensitivity -26 dBFS, AOP 120 dB SPL, 60 Hz to 20 kHz, end of life); the IM72D128's 72 dB(A) SNR, PDM interface and IP57 rating were checked in the DNMS README and are now cited; Codec 2 bit rates were checked on rowetel.com. Still unchecked, flag kept: the Infineon IM72D128 product page (returned 404), the IEC 61672-1 class 2 tolerance table (values used are approximate), UNEP Frontiers 2022 city figures (the page carries no figures; the chapter PDF was not read), India's CPCB standards (fetch disallowed) and the WHO 2018 guideline text. WebSearch was not used. The README region rows for India, Sub-Saharan Africa and Latin America still carry no cited figure.
- Assumed values only tests can settle: microphone and processor currents, the IM72D128 overload point and roll-off, windscreen insertion loss, the uncertainty terms, band preload, the wind threshold.
- Media: in the exploded view the microphone (callout 9) is a few millimeters across and hidden under its callout; in the hero the node is small against the 5 m pole, which is true to scale. The model is shifted down by the mean of the enclosure and microphone heights so the kit's cutaway (a Y section at the parts' mean Y) passes through both the enclosure and the head; the adapter, panel, bracket and cable are left out of the cutaway.
- The drawing is at 1:10 on ANSI B and leaves space unused; the head detail is small at that scale.
- Existing material beyond TRL 3: `build-log/README.md` (scaffold only) is present, untouched and not extended. `electronics/` and `firmware/` are empty. No test, build or firmware material was created.

### Recommended next step

TRL 4 is on hold by Amish's instruction; this repo stops at TRL 3. The next step is Amish's review of NSM-DDR-001 (D1 to D13) and a choice on O1 to O4, plus a note to FieldNode about a street pole mounting variant. For the record only, TRL 4 would need: a bench build of the head with both microphones; a lab test report (TST, `environment: lab`) covering noise floor, frequency response with membrane and windscreen, linearity against a calibrator and reference meter, processor and microphone current, and cable capture showing levels only; weighing of the arm and adapter; and build log entries. None of this has been started.

## Session 2026-09-25: /populate to a strong TRL 2

### What was done

- `docs/01-problem.md` (NSM-PRB-001 v0.2): problem, users, operating context, constraints, prior work with cited sources (EEA, WHO via EEA, EU Directive 2002/49/EC, US EPA, SONYC, DNMS, Bruitparif, IEC 61672-1), out of scope, open questions; co-design checklist kept.
- `docs/02-concept.md` (NSM-PRC-001 v0.2): how it works, 12 numbered components, first-order numbers with assumptions, key design choices, safety, privacy and data-use notes, open questions.
- `docs/03-requirements.md` (NSM-REQ-001 v0.2): 15 measurable requirements (R1 to R15) with targets, verification and concept status, plus a design case and assumptions.
- `cad/src/concept_media.py`: massing model of the node (FieldNode enclosure, board, cell, 6 W panel and bracket, pole clamps, microphone arm, printed head, MEMS microphone, level processor, windscreen with bird spike, M12 cable), each part with a BOM number; street pole, sidewalk, road and a 1.75 m person as grey context. Also draws a two-row data and energy flow diagram in the kit's style, because the kit's flow function takes only numeric losses.
- `media/`: `hero.png`, `concept-blueprint.png`, `.pdf` and `.svg`, `model.glb` and `viewer.html`, `exploded.png` (callouts 1 to 12 match the BOM), `cutaway.png` (enclosure and microphone head sectioned), `flow.png` (estimates labeled). Temporary `media/_views*` folders removed.
- `bom/bom.csv`: 13 lines with indicative USD prices; `bom/bom-notes.md` updated.
- `README.md`: hero image and links line, then the required sections (Concept rationale, Burning platform, Where it could be used with industry and country tables, What sparked the idea) expanded with cited figures; Problem, Concept, Key components and Safety updated to match.
- `project.yaml`: unchanged (pitch and problem remain correct).
- `docs/pdf/`: branded PDFs of the three controlled documents.

### Key results (estimates, to be checked at TRL 3)

| Quantity | Estimate | Requirement |
| --- | --- | --- |
| Measuring range | about 35 to 115 dBA (self-noise about 29 dBA) | R4 at risk at the low end |
| Average load | about 21 mW, 0.51 Wh/day | Within FieldNode's about 115 mW sensor allowance |
| Autonomy without sun | about 30 days | R7 met |
| Winter harvest, standard 6 W panel | about 5.8 Wh/day | R7 met |
| Uplink | 22 bytes per 15 min, about 24 s/day airtime at SF9 | R12 met at SF9; not met at SF10 |
| Mass on pole | about 2.3 kg | R10 met |
| Parts cost | about $171 (FieldNode core about $119, NoiseMap parts about $52) | R13 not met ($100 budget) |

Requirements not met or at risk:

- **R13 (cost) not met:** about $171 against $100.
- **R11 (flag wind and rain) not met:** the concept has no wind or rain sensing.
- **R12 (radio) not met at SF10:** 96 records a day would take about 47 s of airtime against the 30 s fair-use limit; 30-minute records would be needed on distant links.
- **R3 (accuracy) at risk:** housing, membrane, windscreen and pole reflections are unverified.
- **R4 at risk below about 35 dBA** and **R5 at risk below about 60 Hz** (microphone limits).

### Proposed, awaiting Amish (items 1 to 8 since decided by Amish, 2026-09-25: go with recommendation; item 9 still open)

1. **Budget.** Options: (a) raise `budget_usd` to $175; (b) keep $100 and cost the FieldNode core under FieldNode, leaving about $52 of NoiseMap parts, within budget; (c) a cheaper mains or USB powered Wi-Fi variant like DNMS where power exists, which drops the solar and LoRaWAN core. Recommendation: (b), with the full per-node cost of about $171 stated wherever deployment is discussed. `project.yaml` is unchanged.
2. **Privacy claim.** The cable and radio links are far too slow for raw audio but could in principle carry a heavily compressed speech codec, so the guarantee rests on open head firmware with read-out protection and a published build hash. Recommendation: state it this way in all public copy, and do not claim privacy "by physics".
3. **Microphone.** ICS-43434 (widely used, but listed by TDK as end of life) or Infineon IM72D128 (supported by DNMS; specification not checked in this session). Recommendation: a small adapter board that takes either.
4. **Processing in the head** (Cortex-M4F class board) rather than on FieldNode's STM32WL. Recommendation: head, so the cable carries levels only.
5. **Metrics and interval:** 15-minute records with 1-minute LAeq, L10, L90, LAFmax, LAFmin and LCeq. Recommendation: adopt.
6. **Wind flagging** (R11): infer from the level data, or add a small wind sensor at extra cost. Recommendation: study both at TRL 3.
7. **Calibration:** a shared 94 dB, 1 kHz sound calibrator (not in the per-node cost) and one side-by-side comparison with a class 1 meter per deployment. Recommendation: adopt.
8. **Public notice** on each pole linking to this repository. Recommendation: yes.
9. **First partner and street** for co-design.

### Safety concerns

- Work at height beside traffic when installing; pole owner's permission, trained crews, traffic management.
- Falling parts from 4 m: safety lanyard on the arm; about 50 N wind load on the panel to check.
- LiFePO4 cell (about 19 Wh): fusing and cold-charge lockout.
- Hearing: bench tests near the upper range need hearing protection.
- Misuse of data: readings are indicative and must not be presented as certified measurements.
- Privacy: any change to the head firmware or to a higher data-rate link needs a fresh privacy review.

### Notes and gaps

- The FieldNode pole kit fits 40 to 60 mm poles; street poles need larger clamps (BOM line 6). This should be raised with FieldNode, not changed there.
- In the exploded view the microphone (callout 9) and processor (callout 10) are small at this scale and partly hidden by their callout circles. In the hero image the node is small against the 5 m pole, which is true to scale.
- Sources that could not be fetched were left out: the UNEP Frontiers 2022 city noise figures, the WHO 2018 guideline text itself (its road traffic values are cited through the EEA), India's CPCB noise standards and monitoring network, and the Infineon IM72D128 product page. The India, Sub-Saharan Africa and Latin America rows in the README therefore carry no cited figure.
- Microphone and processor currents are typical class values, not datasheet figures.
- The legacy `cad/src/model.py` placeholder is untouched (TRL 3 work).

### Recommended next step

Review this note and the media, then decide items 1 to 3. If approved, run `/advance-trl3` to check the noise floor, frequency response, power and wind load by calculation, define the wind-flagging method, and produce the parametric model and drawing sheet.

## Session 2026-09-26: sources strengthened

| README item | Old source | New source |
| --- | --- | --- |
| "What sparked the idea" (Stratumseind living lab) | The Next Web, 2018, standing alone for the lab's description | [The Hague Security Delta living lab page](https://securitydelta.nl/services/innovation/living-labs/stratumseind) for the lab's partners and acoustic aggression detection; The Next Web kept alongside only for the DITSS director's quote; Galič now identified as *Ars Aequi*, 2019 |
| India row | None | [Press Information Bureau, Government of India, 2011](https://www.pib.gov.in/newsite/erelcontent.aspx?relid=71212&reg=3&lang=2): national real-time noise network launched with 35 stations in seven metros |
| Sub-Saharan Africa row | None (Lagos and Nairobi, uncited) | Rewritten as Sub-Saharan Africa (Nigeria), citing the [UNEP Frontiers 2022 press release](https://www.unep.org/news-and-stories/press-release/deadly-wildfires-noise-pollution-and-disruptive-timing-life-cycles), which lists Ibadan among cities where acceptable noise levels are surpassed |
| Latin America row | None | Replaced with Southeast Asia (Thailand, Vietnam): Bangkok and Ho Chi Minh City, same UNEP source; no verifiable Latin American source was found this session |
| New York 311 figure (Burning platform) | arXiv abstract page (figure not on it) | [Full paper PDF](https://arxiv.org/pdf/1805.00889), *Communications of the ACM*, 2018, which contains the figure |

All other links in the four sourced README sections (EEA noise page, EEA briefing citing WHO 2018, Directive 2002/49/EC, US EPA 1974, Bruitparif) were fetched and confirmed on 2026-09-26. `docs/01-problem.md` did not cite The Next Web, so no controlled document changed. The INSPIRATIONS.md line for NoiseMap was updated to list the stronger source; the event is unchanged.

## Session 2026-09-26: product appearance model and photoreal renders

Amish chose this repo for the first batch of product renders on 2026-09-26.

### What was done

`cad/src/product_model.py` adds a product appearance model for photoreal renders. It exposes `product_parts()` (45 parts: 36 shell, 8 internal, 1 context), `TITLE` and `RENDER_VIEWS` (hero with a short pole section, exploded, and a detail view without the pole). It imports `PARAMS`, `derived()` and `build_parts()` from `cad/src/model.py`; the pole adapter, tilt bracket, arm and head reuse the model.py solids, and every main dimension, height and interface is unchanged. It adds:

- The FieldNode enclosure split into body and lid at a parting line, with filleted edges, a gasket line, four lid screws, side ribs, an ePTFE vent, M12 port nuts, the knurled sensor cable plug and a dust cap on the spare port.
- A lid label that reads "NoiseMap, records sound levels only, no audio is stored or sent", with a teal "dB ONLY" band (kit accent #0F766E).
- A 6 W panel with an aluminium frame, dark cells, a cell grid and a junction box.
- Rounded back plate corners, V-block bolts, band clamp bolts, the arm band clamp housing and the collar screw.
- On the microphone head: grip grooves, a teal accent ring, a cable gland, the foam windscreen (fabric material) and a separate bird spike.
- Internals: the power and radio board with the LoRaWAN module and shield can, the cell with terminals and its cradle, the microphone adapter board and the level processor.
- The sensor cable along the model.py route with rounded bends, and a 1.13 m section of 114.3 mm street pole as context.

The README hero line now points to `media/render-hero.png`, with an "Exploded render" link; the orchestrator produces the render files.

### Differences from model.py (Proposed, awaiting Amish)

- **Lit status light on the lid.** Neither model.py nor the BOM shows a status light on the FieldNode enclosure. The render shows a small green light on the lid. Recommendation: keep it as an appearance cue and raise it with FieldNode as an optional light pipe from the board, costed there. Alternatively, remove it from the appearance model.
- **Lid label text.** The public notice (D8) is specified for the pole, not the enclosure. The render puts a "records sound levels only" label on the lid. Recommendation: keep the lid label and the pole notice both, with the wording checked by Amish before any public use.
- **Head grip grooves and accent ring.** Model.py shows a plain ASA tube. The grooves (0.6 mm deep) and the ring are cosmetic and leave the 3 mm wall, acoustic port and skirt unchanged. Recommendation: keep them for the render; revisit at TRL 4 if the print process makes them costly.
- **Cable plug and dust cap.** Model.py shows the M12 ports as plain cylinders; the render adds a plug on the sensor port and a cap on the spare port, and the cable starts at the plug. Recommendation: accept; this is appearance only.

### Status

This is an appearance model only: no tolerances, no fabrication detail, no PCB layout. `trl` stays 3, and TRL 4 remains on hold.

## Session 2026-09-27: kit 1.5.0 and image quality

- Kit 1.5.0 synced: STANDARDS v1.5 (sections 12 to 15: product renders, storefront images and image quality, public release, authorship and signing), `.kit/cards.py`, `.kit/image_qc.py`, `.kit/release_gate.py`, issue templates, and the `/render-product` and `/release` commands. `CLAUDE.md` now matches `.kit/CLAUDE.md`.
- Every `media/render-*.png` recaptioned from its original render with the new layout: the title, concept label and repository sit in a band above the render and the view note in a band below it, each line wrapped to the image width, so no text overlaps other text or the render or runs off the image. `media/card.png` and `media/social-preview.png` regenerated with the same rules.
- `python .kit/image_qc.py` and `python .kit/release_gate.py` pass. trl stays 3.

## Session 2026-10-02: open decisions decided

On 2026-10-02 Amish approved every recommendation written for the open decisions: "i approve your recommendations for all 555 open decisions." Nothing was built or tested; TRL 4 remains on hold.

### Decisions recorded

5 decisions moved from "Open decisions" to "Decisions made" in the design decisions register, dated 2026-10-02. Design for construction (NSM-DDR-003) accepted with its items A1 and A2; a city noise team or university acoustics group with a Class 1 reference meter named as the first partner to approach; FieldNode's candidate M12 pinout adopted for NoiseMap's port.

### Documents changed

- `docs/01-problem.md` (NSM-PRB-001 v0.6)
- `docs/02-concept.md` (NSM-PRC-001 v0.6)
- `docs/05-build-plan.md` (NSM-BLD-001 v0.2)
- `docs/06-design-decisions.md` (NSM-DEC-001 v0.2)
- `docs/decisions/0001-trl2-review-decisions.md` (NSM-DDR-001 v0.3)
- `docs/decisions/0002-recommendations-accepted.md` (NSM-DDR-002 v0.2)
- `docs/decisions/0003-design-for-construction.md` (NSM-DDR-003 v0.2)
- `README.md` (not a controlled document)
- `docs/pdf/`: every controlled document re-rendered.

### Follow-up actions to carry approved decisions into the design

The model, drawings, build plan pictures, BOM quantities and prices, and calculations were not changed in this session. These actions carry the approved decisions into them:

1. Decision 5 (docs): Cross-repo: ask FieldNode to adopt its candidate M12 pinout for both ports (pin 1 switched rail, pin 2 data A, pin 3 ground, pin 4 data B, pin 5 analog) and to label each port with its rail voltage; NoiseMap's port is set to 3.3 V.
2. Decision 5 (drawings): Show the M12 pin assignment (pin 1 at 3.3 V, pin 3 ground, pins 2 and 4 UART) on the wiring diagram and in the build plan's cable step, and add a 3.3 V port label.
3. Decision 5 (bom): BOM line 12: name the pin assignment in the sensor cable description at the next revision.
4. Decision 2 (docs): TRL 4 test plan (when TRL 4 starts): measure the response with and without the side spike.
5. Decision 3 (docs): TRL 4 test plan: weigh the prototype against R10 (3.5 kg).
6. Decision 1 (pictures): At the next render session on Amish's Mac, redraw the photoreal renders, card and social preview to the constructable design (arm saddle, V-blocks, head and FieldNode bracket).

### Points found in the review

Raised when the recommendations were written (2026-10-01) and not yet acted on:

- Cross-repo: each FieldNode port's rail voltage is chosen at build, and NoiseMap needs 3.3 V where SlopeWatch needs 12 V on the same pin; ports should be labelled with their rail voltage so a 3.3 V sensor is never plugged into a 12 V port.
- Renders still show the concept arm saddle, V-blocks, head and FieldNode bracket.

## Session 2026-10-02: approved follow-ups carried out

Amish, 2026-10-02, approved that every follow-up action from the open-decision sign-off be carried out. trl stays 3; no build or test work was done. Documents changed, with new versions: NSM-BLD-001 v0.3. Also changed: `bom/bom.csv` (lines 12 and 13) and `bom/bom-notes.md`; `cad/src/build_plan_media.py` (wiring picture), `cad/src/sheets.py` (NSM-DWG-001 Rev P4), `cad/src/concept_media.py`, `cad/src/product_model.py`.

### Approved follow-ups carried out

1. **Decision 5, ask FieldNode to adopt its pinout and label each port with its rail voltage: not done here, listed under Cross-repo actions.** NoiseMap's side is done: it uses pin 1 at 3.3 V, pin 3 ground and pins 2 and 4 for the UART pair, and its port is labelled 3.3 V.
2. **Decision 5, pin assignment on the wiring diagram and in the cable step, and a 3.3 V port label: done.** Figure 13 (`docs/05-build-plan/wiring.png`) shows the pin numbers and a "PORT A: 3.3 V" label; build plan 3.8 step 3, step 12 and safety stop S1 name the pins and the label; the GA sheet notes the pins; the appearance model carries the label beside port A.
3. **Decision 5, BOM line 12 names the pin assignment: done.** The label is in line 13 (about USD 0.50, inside the line's price). No price changed.
4. **Decision 2, TRL 4 test plan: measure the response with and without the side spike: not done, TRL 4 work (no test plans at the TRL 3 cap).**
5. **Decision 3, TRL 4 test plan: weigh the prototype against R10: not done, TRL 4 work.**
6. **Decision 1, appearance model for the constructable design: done.** `cad/src/product_model.py` now uses the built back plate (window, band slots), the side bird spike in its skirt boss with the matching windscreen, the built head gland, and adds the enclosure lugs and screws, cable glands, bracket and panel bolts; the concept hex bolts and the concept saddle fixings are gone. Render scenes exported (hero, exploded, detail views as listed in the file) to `/home/claude/renders/noisemap`. The photoreal renders, card and social preview are made on Amish's Mac next.

### Key results

- Requirement status changes: none (3 at risk, 4 not verifiable, 4 met on paper, 4 met by design, as before). Calculations re-run: output unchanged.
- Value-engineering target: USD 100. Estimated cost of the constructable design: USD 72 (USD 28 under the target). Mass unchanged at about 3.45 kg (R10 3.5 kg).
- Model: 62 constructability checks pass; the model did not change.
- Pictures regenerated: wiring diagram (Figure 13), NSM-DWG-001 (Rev P4), the concept media (blueprint, hero, cutaway, exploded, flow, viewer).

### Cross-repo actions

- **FieldNode (`fieldnode`):** adopt its candidate M12 pinout for both sensor ports (pin 1 switched rail, pin 2 data A, pin 3 ground, pin 4 data B, pin 5 analog), and label each port with its rail voltage, so that a 3.3 V sensor such as NoiseMap is never plugged into a 12 V port such as SlopeWatch's. Publish the pinout in the FieldNode documents.

### Proposed, awaiting Amish

- The approved decision fixes the pins (1, 3, and 2 and 4 as the UART pair) but not which of pins 2 and 4 carries the head's transmit. The wiring diagram and build plan put the head's transmit (levels out) on pin 2 (data A) and its receive on pin 4 (data B). Recommendation: accept, and confirm with FieldNode's firmware at TRL 4.

## 2026-10-02: photoreal renders redone on the constructable design

Rendered with Blender Cycles on Amish's Mac from the updated appearance model; captioned with `.kit/photo_caption.py`; `media/card.png` and `media/social-preview.png` regenerated with `.kit/cards.py`. Views: hero, exploded, detail. image_qc passes. Appearance deviations are those logged above as proposed, awaiting Amish.

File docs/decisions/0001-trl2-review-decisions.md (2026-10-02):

---
doc_id: NSM-DDR-001
title: NoiseMap TRL 2 review decisions
project: NoiseMap
doc_type: Design decision record
version: "0.3"
status: Draft
date: '2026-10-02'
author: Amish Chadha
license: CERN-OHL-S-2.0
revisions:
- version: "0.1"
  date: '2026-09-25'
  author: Amish Chadha
  change: Record the TRL 2 review items adopted as recommended for TRL 3 under Amish's 2026-09-25 instruction, and the items that remain open
- version: "0.2"
  date: '2026-09-25'
  author: Amish Chadha
  change: Recommendations accepted by Amish (DDR-002)
- version: "0.3"
  date: '2026-10-02'
  author: Amish Chadha
  change: O1 decided by Amish on 2026-10-02 (recommendation approved, NSM-DEC-001)
---

# 0001: TRL 2 review decisions

- **Date:** 2026-09-25
- **Status:** accepted. On 2026-09-25 Amish accepted all recommendations ("i accept all your recommendations, go with them across all repos"). D1 to D13 and O2 to O4 are decided by Amish, 2026-09-25: go with recommendation (see NSM-DDR-002). O1 had no recommendation then; it was decided on 2026-10-02, when Amish approved the recommendation later written for it ("i approve your recommendations for all 555 open decisions."; NSM-DEC-001).

## Context

The TRL 2 review note (`docs/REVIEW.md`, session 2026-09-25, /populate) listed nine items as "Proposed, awaiting Amish", eight of them with a recommendation, and the design precis NSM-PRC-001 v0.2 listed its key design choices as proposed. On 2026-09-25 Amish asked for this batch of repos to be taken through the usual process with the instruction "you know the drill, nothing gets past TRL 3". He has not reviewed the NoiseMap items one by one. Every item that carries a recommendation is therefore adopted as recommended for TRL 3 under Amish's 2026-09-25 instruction, open for his review. Items without a recommendation stay open. Later on 2026-09-25 Amish accepted all recommendations across the portfolio; the status column below records that, and NSM-DDR-002 lists what changed.

## Options considered

The options for each item are those in `docs/REVIEW.md` (session 2026-09-25, /populate, items 1 to 9) and in NSM-PRC-001 v0.2, Key design choices.

## Decision

*Table 1. Items decided.*

| # | Item | Recommendation adopted | Status |
| --- | --- | --- | --- |
| D1 | Budget (review item 1) | Option (b): keep `budget_usd` at $100 and redefine it to cover the NoiseMap parts only; the FieldNode core is costed in the FieldNode repo ($126.00, FND-CAL-001). The full per-node cost is stated wherever deployment is discussed. R13 is restated accordingly. No new budget figure was recommended, so `budget_usd` is unchanged. | Decided by Amish, 2026-09-25: go with recommendation |
| D2 | Privacy claim (item 2) | State in all public copy that the guarantee rests on open head firmware with read-out protection and a published build hash; never claim privacy "by physics". NSM-CAL-001 confirms this: the cable could carry a speech codec, and the radio a few minutes of it a day. | Decided by Amish, 2026-09-25: go with recommendation |
| D3 | Microphone (item 3) | A small adapter board that takes either the ICS-43434 (I²S, end of life) or the IM72D128 (PDM); the level processor accepts both interfaces. | Decided by Amish, 2026-09-25: go with recommendation |
| D4 | Processing location (item 4) | Levels computed in the head on a Cortex-M4F class board, so the cable carries levels only. | Decided by Amish, 2026-09-25: go with recommendation |
| D5 | Metrics and interval (item 5) | 15-minute records with 1-minute LAeq, LAeq, LAFmax, LAFmin, L10, L90 and LCeq (22 bytes). This also settles the problem statement's questions on 1-minute detail and C weighting. | Decided by Amish, 2026-09-25: go with recommendation |
| D6 | Wind flagging (item 6) | Study both options at TRL 3: done in NSM-CAL-001 section G (level-based wind flag with no added cost; cup anemometer about $25 and 0.15 kg). The choice between them is new item O3. | Decided by Amish, 2026-09-25: go with recommendation |
| D7 | Calibration (item 7) | A shared 94 dB, 1 kHz calibrator outside the per-node cost, and one side-by-side comparison with a class 1 meter per deployment. | Decided by Amish, 2026-09-25: go with recommendation |
| D8 | Public notice (item 8) | A notice on each pole saying what is measured, linking to this repository. | Decided by Amish, 2026-09-25: go with recommendation |
| D9 | Levels, never audio (precis choice) | No data storage and no radio in the head; firmware has no path that writes or sends samples. | Decided by Amish, 2026-09-25: go with recommendation |
| D10 | Standard FieldNode core (precis choice) | Standard FieldNode enclosure, 6 W panel and one cell; NoiseMap draws 12.2 mW, 12 % of FieldNode's 100 mW design allowance. | Decided by Amish, 2026-09-25: go with recommendation |
| D11 | Microphone position (precis choice) | Port 4.0 m above the sidewalk, 0.45 m from the pole face, facing up, on an arm with its own band clamp. | Decided by Amish, 2026-09-25: go with recommendation |
| D12 | A and C weighting (precis choice) | LAeq and statistics, plus LCeq for amplified bass. | Decided by Amish, 2026-09-25: go with recommendation |
| D13 | Head housing (precis component 8) | 3D-printed ASA tube with drip skirt and hydrophobic acoustic membrane. | Decided by Amish, 2026-09-25: go with recommendation |

*Table 2. Items raised at TRL 3 (O2 to O4 decided under NSM-DDR-002; O1 open).*

| # | Item | Status |
| --- | --- | --- |
| O1 | First co-design partner and street (review item 9, problem statement). No recommendation was made. | Decided by Amish, 2026-10-02 (recommendation approved, NSM-DEC-001): first partner to approach is a city environmental noise team or a university acoustics group that can put a Class 1 reference sound level meter beside the node on the test street; a Sensor.Community group is a useful second contact for volunteer hosts |
| O2 | R10 mass: the node is 3.32 kg against 3 kg (NSM-CAL-001 section H). Options: (a) pocket the V-blocks and saddle (about 3.10 kg, still over); (b) relax R10 to 3.5 kg; (c) both. Recommendation: (c). New at TRL 3. | Decided by Amish, 2026-09-25: go with recommendation (c); applied under NSM-DDR-002 |
| O3 | R11 wind flag method: (a) level-based flag from a Z-weighted band below 40 Hz, no cost; (b) add a cup anemometer on FieldNode's second port (about $25, 0.15 kg, which worsens O2). Rain is flagged on the server from weather data in both. Recommendation: (a), with a field comparison to set the threshold. New at TRL 3. | Decided by Amish, 2026-09-25: go with recommendation (a); the field comparison is TRL 4 work, on hold |
| O4 | R12 at SF10 and slower: lengthen the interval automatically (24 min at SF10, 87 min at SF12) on The Things Network, as FieldNode proposes. New at TRL 3; follows the FieldNode decision. | Decided by Amish, 2026-09-25: go with recommendation; interval rule written into NSM-PRC-001 and NSM-REQ-001 |

## Consequences

- `project.yaml`: only the TRL fields change. `budget_usd` stays at $100 (D1 redefines what it covers; no new figure was recommended). No reworded pitch or problem was recommended, so they are unchanged.
- NSM-PRB-001, NSM-PRC-001 and NSM-REQ-001 are revised to v0.3. The key design choices are no longer "proposed". R13 is redefined to cost the NoiseMap parts only, with the full node cost stated. R12's target is unchanged.
- The BOM now prices the FieldNode core at the FieldNode figure of $126.00 (TRL 2 used $119) and adds a street pole adapter (line 14), so the NoiseMap parts are $62.00 and the full node $188.00.
- NSM-CAL-001 corrects several TRL 2 figures (load 21 to 12.2 mW, autonomy 30 to 53 days, upper range 115 to 113 dBA, mass 2.3 to 3.32 kg); see its section on checks.
- The changes made when O2 to O4 were decided are listed in NSM-DDR-002.
- TRL 4 is on hold by Amish's instruction. Nothing in this record authorizes building or testing.

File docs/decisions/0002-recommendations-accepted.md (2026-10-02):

---
doc_id: NSM-DDR-002
title: NoiseMap recommendations accepted
project: NoiseMap
doc_type: Design decision record
version: "0.2"
status: Draft
date: '2026-10-02'
author: Amish Chadha
license: CERN-OHL-S-2.0
revisions:
- version: "0.1"
  date: '2026-09-25'
  author: Amish Chadha
  change: Record Amish's acceptance of all recommendations and the changes made in this repo
- version: "0.2"
  date: '2026-10-02'
  author: Amish Chadha
  change: O1 decided by Amish on 2026-10-02 (recommendation approved, NSM-DEC-001)
---

# 0002: Recommendations accepted

- **Date:** 2026-09-25
- **Status:** accepted. Every item below with a recommendation is decided by Amish, 2026-09-25: go with recommendation. O1, which had no recommendation, was decided on 2026-10-02 (NSM-DEC-001).

## Context

On 2026-09-25 Amish wrote: "i accept all your recommendations, go with them across all repos." NSM-DDR-001 had adopted D1 to D13 for TRL 3 work, open for his review, and left O1 to O4 as "Proposed, awaiting Amish". O2, O3 and O4 each carried a recommendation; O1 did not. TRL 4 remains on hold by Amish's instruction, and the repo stays at TRL 3.

## Decision

*Table 1. Items newly decided and what changed in the repo.*

| # | Item | Decision (the recommended option) | What changed |
| --- | --- | --- | --- |
| D1 | Budget scope | `budget_usd` stays $100 and covers the NoiseMap parts only; FieldNode core costed in FieldNode | No change to `budget_usd` ($100); R13 already restated in NSM-REQ-001 v0.3; wording updated to "decided" |
| D2 | Privacy claim | Guarantee rests on open head firmware, read-out protection and a published build hash; never "by physics" | Status wording only |
| D3 | Microphone | Adapter board for ICS-43434 or IM72D128 | Status wording only |
| D4 | Processing location | Levels computed in the head | Status wording only |
| D5 | Metrics and interval | 15-minute, 22-byte records with 1-minute LAeq and statistics | Status wording only |
| D6 | Wind flagging study | Both options studied at TRL 3 | Superseded by O3 |
| D7 | Calibration | Shared 94 dB calibrator; one class 1 side-by-side per deployment | Status wording only; the side-by-side is TRL 4 work, on hold |
| D8 | Public notice | Notice on each pole linking to the repository | Status wording only |
| D9 to D13 | Precis choices | Levels only; standard FieldNode core; microphone at 4.0 m, 0.45 m off the pole; A and C weighting; printed ASA head | Status wording only |
| O2 | R10 mass | Option (c): pocket the V-blocks and saddle, and relax R10 from 3 kg to 3.5 kg | `cad/src/model.py`: V-blocks pocketed from top and bottom (4 mm walls, 8 mm web), saddle pocketed 6 mm deep; the V notch geometry was also corrected (v0.1 had cut each block to a flat 10 mm plate). STEP and STL re-exported. NSM-DWG-001 Rev P1 to P2. NSM-REQ-001 R10 target 3 kg to 3.5 kg. NSM-CAL-001 v0.1 to v0.2: mass 3.32 kg (flawed geometry) to 3.45 kg pocketed, 3.96 kg solid; R10 not met to met on paper, margin 0.05 kg. BOM lines 7 and 14 describe the pockets; prices unchanged |
| O3 | R11 wind flag method | Option (a): level-based flag from the Z-weighted band below 40 Hz; rain flagged on the server | No anemometer added. NSM-PRC-001 and NSM-REQ-001 state the method; NSM-CAL-001 records the anemometer as a rejected option. The field comparison that sets the threshold is TRL 4 work, on hold |
| O4 | R12 airtime at SF10 and slower | Lengthen the interval automatically: 24 min at SF10, 48 min at SF11, 87 min at SF12 | Firmware rule written into NSM-PRC-001 (how it works, step 5) and NSM-REQ-001 R12. NSM-CAL-001 [F2c]: at most 30.0 s/day at every spreading factor; R12 at risk to met on paper. Aligns with FieldNode's interval item (cross-repo action) |

*Table 2. Item left open here, decided on 2026-10-02.*

| # | Item | Status |
| --- | --- | --- |
| O1 | First co-design partner and street. No recommendation was made. | Decided by Amish, 2026-10-02 (recommendation approved, NSM-DEC-001): first partner to approach is a city environmental noise team or a university acoustics group that can put a Class 1 reference sound level meter beside the node on the test street; a Sensor.Community group is a useful second contact for volunteer hosts |

## Consequences

- Requirement status (NSM-CAL-001 v0.2): 0 not met, 3 at risk (R3, R4, R5), 4 not verifiable at TRL 3 (R8, R9, R11, R14), 4 met on paper (R7, R10, R12, R13), 4 met by design (R1, R2, R6, R15). Before: 1 not met (R10), 4 at risk (R3, R4, R5, R12).
- The R10 margin is only 0.05 kg; any added part needs a mass check. Shorter V-blocks or dropping FieldNode's unused small-pole V-blocks would add margin.
- NSM-PRB-001, NSM-PRC-001 and NSM-REQ-001 go from v0.3 to v0.4; NSM-DDR-001 from v0.1 to v0.2; NSM-CAL-001 from v0.1 to v0.2. Concept media are re-rendered from the updated model.
- Cross-repo actions, not made here: ask FieldNode for a street pole mounting variant for 60 to 140 mm poles; align the interval rule with FieldNode's interval item; agree the M12 pinout (FieldNode O2).
- TRL 4 is on hold by Amish's instruction. `trl` and `trl_target` stay at 3. Nothing here authorizes building, testing, purchasing, PCB work or firmware beyond a sketch.

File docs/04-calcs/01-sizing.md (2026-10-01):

---
doc_id: NSM-CAL-001
title: NoiseMap sizing calculations
project: NoiseMap
doc_type: Calculation note
version: "0.3"
status: Draft
date: '2026-10-01'
author: Amish Chadha
license: CERN-OHL-S-2.0
revisions:
- version: "0.1"
  date: '2026-09-25'
  author: Amish Chadha
  change: First issue for TRL 3 (measuring range, frequency response, reflections and accuracy, processing and power, energy, record format, airtime, privacy capacity, wind and rain flagging, mechanics, mass, cost)
- version: "0.2"
  date: '2026-09-25'
  author: Amish Chadha
  change: Recommendations accepted by Amish (DDR-002); pocketed V-blocks and saddle, corrected V-block geometry, R10 at 3.5 kg, interval rule for R12, level-based wind flag
- version: "0.3"
  date: '2026-10-01'
  author: Amish Chadha
  change: Mechanics, mass and cost re-run for the constructable design (NSM-DDR-003); FieldNode core at FND-CAL-001 v0.3; budget treated as a value-engineering target
---

# NoiseMap sizing calculations

On paper, NoiseMap meets eight of its fifteen requirements (four by calculation, four by design), has three at risk, misses none and leaves four that only tests can settle. Under NSM-DDR-002 R10 is relaxed to 3.5 kg. With the design made constructable (NSM-DDR-003: sawn and drilled V-blocks, a bent sheet arm saddle with two bands, fixings throughout, and the FieldNode core without its small-pole V-blocks and bands), the node weighs **3.45 kg against 3.5 kg (R10)**, a margin of only 0.05 kg. An automatic interval rule at slow data rates brings R12 within fair use at every spreading factor. Energy is not a concern: the design load is 12.2 mW, 12 % of FieldNode's 100 mW allowance, which gives 53 days without sun and keeps the node in credit even on the hot clear days that stop FieldNode charging. The measuring range reaches 35 dBA with no margin on the ICS-43434 (34.9 dBA) and with 7 dB of margin on the IM72D128 (27.9 dBA), and tops out at 113 dBA. Accuracy (R3) is at risk: an assumed uncertainty budget gives ±2.9 dB, and a facade behind the pole can add up to 2.4 dB before a site correction. Under NSM-DDR-001 D1 the $100 `budget_usd` applies to the NoiseMap parts; it is a value-engineering target, not a limit. The constructable NoiseMap parts are estimated at $72.00, $28.00 under the target; the full node with the FieldNode core is $211.00.

Every number in this note is printed by `docs/04-calcs/sizing.py` (run from the repo root: `python docs/04-calcs/sizing.py`), which also writes `docs/04-calcs/results.csv`. The tag in brackets, for example [A1], is the line of the script's output that carries the number. The script imports `PARAMS`, `derived()` and the part volumes from `cad/src/model.py`, reads `bom/bom.csv` and `budget_usd` in `project.yaml`, and takes FieldNode energy figures from FND-CAL-001 v0.1 and its mass from FND-CAL-001 v0.3.

> **Safety:** These are first-principles estimates for a paper proof of concept. They do not show that the pole mounting, the lithium iron phosphate cell or the installation is safe. Clamp preload, arm fixing and the cell's charge lockout must be checked on hardware before any node is installed. See NSM-PRC-001, Safety.

## Assumptions

*Table 1. Main assumptions.*

| Area | Assumption | Basis |
| --- | --- | --- |
| ICS-43434 | 65 dB SNR, sensitivity -26 dBFS at 94 dB SPL, 120 dB SPL overload, response 60 Hz to 20 kHz, listed end of life; supply 0.49 mA | TDK product page ([TDK InvenSense](https://invensense.tdk.com/products/ics-43434/)); current is a typical class value, not checked |
| IM72D128 | 72 dB(A) SNR, PDM output, IP57 at part level; overload and roll-off taken equal to the ICS-43434; supply 1.0 mA | DNMS README ([DNMS](https://github.com/hbitter/DNMS)); overload, roll-off and current not checked |
| Range criteria | Lower limit where self-noise adds 1 dB; 10 dB crest factor above the rms level for traffic, horns and sirens | Screening values |
| Response limits | ±2.5 dB at 63 Hz and ±5 dB at 8 kHz, taken as the class 2 limits; low-frequency corner spread ±20 % | Approximate; the IEC 61672-1 table was not re-checked in this session |
| Processing | 48 kHz; seven biquads (A 3, C 2, low-frequency equalizer 1, wind band 1) at 14 cycles each; four channels at 6 cycles; 10 cycles overhead; 48 MHz clock; 120 µA/MHz running, 1.6 mA asleep with DMA running | STM32L4 class typical figures; to confirm on the chosen board |
| FieldNode core | 4.0 mWh/day core; 15.36 Wh usable; 70 % at -20 °C, 80 % at end of life; rail 90 %; controller 8 mA awake, woken for each 12-byte frame at 9,600 baud plus 5 ms | FND-CAL-001 v0.1; the wake overhead is assumed |
| Energy chain | 6 W panel, 1.5 peak sun hours (NoiseMap design case), 0.80 derating, charger 0.85, cell 0.95 | NSM-REQ-001 Table 2; FND-CAL-001 |
| Radio | 22-byte record plus 13 bytes of LoRaWAN overhead; 125 kHz, CR 4/5, 8-symbol preamble, explicit header, CRC; 96 uplinks a day | LoRaWAN defaults |
| Speech codec | Codec 2 runs at 700 to 3,200 bit/s | [Rowetel, Codec 2](https://www.rowetel.com/?page_id=452) |
| Reflections | Incoherent addition; facade energy reflection 0.9; lanes 5 and 10 m from the microphone | Screening values |
| Wind | 35 m/s gust, 1.225 kg/m³; Cd 1.2 on tubes, 0.5 on the foam sphere; 6063-T5 class E = 69 GPa, yield 145 MPa; band preload 1,000 N and friction 0.2; turbulence intensity 0.2 at 4 m | Handbook ranges; preload as FND-CAL-001 |
| Mass | Aluminium 2.70, stainless steel 7.90, ASA 1.07, nylon 1.15, foam 0.030 g/cm³ from model volumes (printed parts counted solid); boards 15 g, cable 90 g, ties, tape and small parts 30 g; FieldNode base node 2.45 kg (FND-CAL-001 v0.3) less its small-pole V-blocks and 80 g of bands, which a street pole node leaves off (NSM-DDR-003) | Estimates |

## A. Measuring range (R4)

- **Self-noise and lower limit.** The ICS-43434 has 29.0 dBA of self-noise, so a 35 dBA street reads 0.97 dB high; the 1 dB lower limit is **34.9 dBA**, with no margin on the 35 dBA target. The IM72D128 has 22.0 dBA of self-noise and a lower limit of **27.9 dBA** [A1].
- **Noise-floor subtraction** helps only as far as the self-noise is known: with the ICS-43434 at 35 dBA, an error of ±1 dB in the stored self-noise leaves the result between 34.71 and 35.22 dBA [A2]. The adapter board of D3 lets a quiet-street node use the IM72D128.
- **Upper limit.** The ICS-43434 reaches full scale at 120 dB SPL rms for a sine, 123 dB peak [A3]. With a 10 dB crest factor the highest rms level measured cleanly is **113 dB**, against the 110 dBA target. The TRL 2 figure of 115 dBA ignored crest factor. The IM72D128 overload point was not checked and is taken as the same.
- **R4 is at risk** with the ICS-43434 and met on paper with the IM72D128.

## B. Frequency response (R5)

- **Low frequencies.** Treating the 60 Hz lower limit as a first-order corner, the microphone is down 0.9 dB at 125 Hz, 2.8 dB at 63 Hz and 6.7 dB at 31.5 Hz [B1]. A fixed digital equalizer in the head restores this; if the corner varies by ±20 % between parts, the residual is ±0.8 dB at 63 Hz and about ±1.4 dB at 31.5 Hz [B2], inside the ±2.5 dB taken as the class 2 limit at 63 Hz. The equalizer adds 6.7 dB of gain at 31.5 Hz, where A weighting is -39.4 dB, so LAeq self-noise barely changes; LCeq self-noise rises at low frequencies [B2b].
- **Acoustic port.** The 3 mm port through the 2 mm top plate and a 3 x 0.5 mm front cavity (the gasket gap between plate and microphone board) resonate at **36.2 kHz**, adding 0.44 dB at 8 kHz undamped [B3]. A tenfold larger cavity would resonate at 10.4 kHz and add 7.9 dB at 8 kHz [B3b], so the cavity must stay small. These dimensions are parameters in `cad/src/model.py`.
- **R5 is at risk.** The hydrophobic membrane, the windscreen and diffraction round the 40 mm head all shape the response above about 2 kHz, and none can be calculated with confidence on paper.

## C. Reflections and accuracy (R3)

- **Pole.** A 114.3 mm pole 0.45 m behind the microphone reflects 6.0 % of the direct energy back to it, adding 0.25 dB [C1]. The FieldNode core sits in the pole's shadow on the far side.
- **Facades.** A facade behind the pole adds more (Table 2) [C2]. At 1 to 2 m the bias is 1.1 to 2.4 dB, which approaches the whole ±2 dB of R3.

*Table 2. Level added by a facade behind the microphone (energy reflection 0.9).*

| Facade distance | Lane 5 m, point source | Lane 5 m, traffic line | Lane 10 m, point source | Lane 10 m, traffic line |
| --- | --- | --- | --- | --- |
| 1 m | +1.6 dB | +2.2 dB | +2.1 dB | +2.4 dB |
| 2 m | +1.1 dB | +1.8 dB | +1.6 dB | +2.2 dB |
| 5 m | +0.4 dB | +1.1 dB | +0.9 dB | +1.6 dB |
| 10 m | +0.2 dB | +0.7 dB | +0.4 dB | +1.1 dB |

- **Uncertainty budget.** With assumed standard uncertainties of 0.4 dB for the calibrator, 0.5 dB for drift between checks, 0.5 dB for the windscreen, 0.7 dB for the response residual and 1.0 dB for reflections after a site correction, the combined value is 1.47 dB and the expanded value (k = 2) **2.9 dB** against ±2 dB [C3], [C3b]. **R3 is at risk.** The side-by-side comparison of D7 is what sets the site correction; only it can show whether R3 is met.

## D. Processing and power (R7)

- **Processor load.** Seven biquads and four channels take 132 cycles per sample: 6.34 million cycles a second, 13.2 % of a 48 MHz core. At 32 kHz this falls to 4.22 million [D1]. The TRL 2 question on sample rate therefore does not affect power much; 48 kHz stays.
- **Current.** Running 13.2 % of the time at 5.76 mA and sleeping with DMA at 1.6 mA, the processor averages **2.15 mA** [D2]. The TRL 2 assumption was 5 mA.
- **Node load.** With the ICS-43434 the head takes 9.7 mW from the cell and the node 10.3 mW; with the IM72D128 the head takes 11.5 mW and the node **12.2 mW** (0.292 Wh a day), the design value. Waking the FieldNode controller for each one-second frame costs 0.46 mW, more than the 0.17 mW of the rest of the core [D3]. With the TRL 2 processor current and a 1 mA microphone the upper bound is 22.6 mW (0.543 Wh a day) [D4]. The design load is 12 % of FieldNode's 100 mW design allowance [D5].

## E. Energy (R7)

- **Harvest.** At 1.5 peak sun hours the cell stores 5.81 Wh a day, 20 times the design load and 11 times the upper bound; FieldNode's worst month (2 h) gives 7.75 Wh [E1].
- **Autonomy.** At the design load one cell lasts **53 days** without sun, 37 days at -20 °C and 42 days at end of life; the upper bound, cold and aged, still gives 16 days [E2], against 14.
- **Hot weather.** FieldNode's hot clear day without a shield stores 0.8 Wh (clean) or 0.3 Wh (dusty) because the cell is above its 45 °C charge limit most of the day. NoiseMap draws 0.29 Wh at the design load, so it stays in credit, marginally when dusty; at the upper bound (0.54 Wh) a dusty node would lose charge [E3]. The FieldNode sun shield decision (FieldNode review item 4) matters little to NoiseMap.
- **R7 is met on paper.**

## F. Record, radio and privacy (R1, R2, R6, R12)

- **Record.** Fifteen 1-minute LAeq bytes, LAeq,15min, LAFmax, LAFmin, L10, L90, LCeq and a status byte make **22 bytes**; one byte at 0.5 dB steps spans 20.0 to 147.5 dB [F1]. The status byte carries the wind flag and the count of flagged minutes. R2 is met by design.
- **Airtime (Table 3).** At SF9 each uplink takes 246.8 ms, 23.7 s a day. At SF10 the 35-byte frame takes 493.6 ms and 47.4 s a day, over The Things Network's 30 s [F2]. A stored record sent later carries a 4-byte time stamp (267.3 ms at SF9) [F2b]. The EU868 1 % duty cycle is met at every spreading factor.
- **Interval rule (NSM-DDR-002, item O4).** The core keeps 15 minutes at SF7 to SF9 and lengthens the interval automatically at slower data rates to the shortest that fits 30 s a day: 24 min at SF10 (29.6 s a day, 60 records), 48 min at SF11 (29.6 s, 30 records) and 87 min at SF12 (30.0 s, 16 records). The record stays 22 bytes; its fifteen sub-interval LAeq values then each span 1.6, 3.2 or 5.8 minutes [F2c]. **R12 is met on paper** with this rule, which follows FieldNode's own interval item.

*Table 3. Time on air for a 22-byte record (35 bytes on air) at 125 kHz [F2].*

| Spreading factor | Per uplink | Per day at 15 min | Shortest interval within 30 s/day | EU868 1 % off-time |
| --- | --- | --- | --- | --- |
| SF7 | 77.1 ms | 7.4 s | 4 min | 8 s |
| SF8 | 143.9 ms | 13.8 s | 7 min | 14 s |
| SF9 | 246.8 ms | 23.7 s | 12 min | 24 s |
| SF10 | 493.6 ms | 47.4 s | 24 min | 49 s |
| SF11 | 987.1 ms | 94.8 s | 48 min | 98 s |
| SF12 | 1,810.4 ms | 173.8 s | 87 min | 179 s |

- **Time stamps.** The core stamps each record from LoRaWAN network time (DeviceTimeReq), which is well within 2 s; R6 is met by design.
- **What the links could carry (R1).** Raw audio is 1.152 Mbit/s. The UART carries 7,680 bit/s of payload, 150 times too slow for raw audio, and the level frames use 1.25 % of it. A speech codec such as Codec 2 needs 700 to 3,200 bit/s, which the cable could carry [F3]. The radio could carry 21.4 kbit a day at SF9 under fair use, about 31 s of 700 bit/s speech, or 1.97 Mbit a day at SF7 under the 1 % duty cycle alone, about 47 min [F4]. The physical links do not rule out leaking speech, so, as D2 states, privacy rests on the open head firmware, read-out protection and a published build hash. R1 is met by design on that basis.

## G. Wind and rain flagging (R11)

- **Wind.** Turbulence at 4 m makes pressure fluctuations of about 1 Pa rms at 2 m/s, 6 Pa at 5 m/s and 25 Pa at 10 m/s at an unscreened microphone (94, 110 and 122 dB), mostly below 20 Hz [G1]. The foam windscreen removes much of this, but what reaches the microphone scales roughly with the fourth power of wind speed: from 2 to 5 m/s it rises by 15.9 dB, and 1 m/s near 5 m/s is 3.2 dB [G2]. A Z-weighted band below 40 Hz, computed in the head, and its one-second spread therefore separate windy minutes sharply from traffic once a threshold is set. The threshold cannot be computed; it needs a field comparison with an anemometer.
- **Rain.** Rain on the foam gives broadband impulses that level statistics do not reliably separate from street noise. The method is a server-side flag from the nearest public weather station or radar rainfall, which needs no hardware.
- **Wind sensor option, not adopted.** A cup anemometer with a pulse output on FieldNode's second port would cost about $25 and weigh about 0.15 kg (indicative, unchecked), bringing the NoiseMap parts to $97.00 and the node to 3.60 kg, over R10 [I3]. Under NSM-DDR-002 (item O3) the level-based flag is the method, so no anemometer is fitted.
- **R11 is not verifiable at TRL 3.** The method is chosen; the threshold needs a field comparison with an anemometer, which is TRL 4 work and on hold.

## H. Mechanics (R10)

- **Mass.** The FieldNode base node is 2.45 kg; a street pole node leaves off its V-blocks (0.144 kg) and bands (0.08 kg), which gives 2.23 kg. To that the arm saddle, tube, flange and fixings add 0.391 kg, the arm bands and lanyard 0.129 kg, the head housing, cap and bolts 0.108 kg, the boards 0.015 kg, the windscreen and spike 0.023 kg, the cable and gland 0.099 kg, the street pole V-blocks and screws 0.314 kg, their bands 0.114 kg, and ties and small parts 0.030 kg [H1]: **3.45 kg against the relaxed 3.5 kg, so R10 is met on paper**, with 0.05 kg of margin [H2]. Sawing the V-blocks from 16 mm bar rather than 20 mm and drilling four 14 mm holes in each saves 0.144 kg [H2b].
- **History.** Version 0.2 also gave 3.45 kg, with machined, pocketed 110 x 60 x 40 mm V-blocks, a pocketed saddle, one arm band and the 2.41 kg FieldNode core with its small-pole parts left in. The constructable design (NSM-DDR-003) adds a second arm band, a tube flange, a head cap, a gland and fixings, and leaves the FieldNode small-pole parts off; the two roughly balance.
- **Wind on the arm.** At 35 m/s (750 Pa) the 383 mm arm takes 8.6 N, the head tube 3.8 N and the windscreen 2.4 N [H3]. The arm root sees 4.01 N·m from wind and 0.83 N·m from weight, 4.10 N·m combined; the 25 x 2 mm tube (770 mm³ section modulus) is stressed to 5.3 MPa, a factor of 27 on yield [H4]. The tip moves 0.26 mm in the gust.
- **Vibration.** The arm and head have a first mode near 70 Hz. Vortex shedding matches it at about 8.8 m/s across the arm and 14.1 m/s across the head [H5]. Stresses are low, but vibration at those speeds would add structure-borne noise at the microphone, and those intervals are windy enough to be flagged anyway.
- **Clamp.** The arm saddle now has two bands. Wind twists it about the pole with 4.86 N·m against 45.7 N·m of friction (factor 9.4), and the arm and head pull it down with 6.5 N against 800 N [H6]. Both depend on the assumed 1,000 N preload per band.
- **Pole load.** The node adds about 96 N at 3.5 to 4 m in a 35 m/s gust (81 N from FieldNode) [H7], which the pole owner should check.
- **Fit.** On a 60 mm pole the V contacts sit 21.2 mm either side of the centre line and on a 140 mm pole 49.5 mm, inside both the V-blocks' 106 mm mouth and the saddle's 109 mm mouth; poles up to 141 mm keep their contacts 3 mm inside both [H8], [H8b]. The street pole bands need about 369 to 558 mm. The fit to 60 to 140 mm poles is met by design; the 45 min installation time can only be timed.

## I. Cost (R13)

The BOM has 14 lines, all priced. Lines 1 to 6, the FieldNode core, total $139.00, the base node figure in the FieldNode BOM after its own design for construction (FND-DDR-003); lines 7 to 14, the NoiseMap parts, total **$72.00** [I1]. Value-engineering target: USD 100 (`budget_usd`, a hypothetical control target, not a limit). Estimated cost of the constructable design: USD 72.00 for the NoiseMap parts (USD 28.00 under the target); the full node is USD 211.00 [I2]. **R13 is met on paper.** The constructable design added $10.00 to the NoiseMap parts (two-band saddle and tube flange $6.00, cable gland $1.00, fixings and lanyard $2.00, head cap $1.00) and the FieldNode core rose from $126.00 to $139.00 under FND-DDR-003.

## L. Results against every requirement

*Table 4. Requirement status (weakest first) [L].*

| ID | Requirement | Value | Target | Status |
| --- | --- | --- | --- | --- |
| R3 | Accuracy | Expanded uncertainty 2.9 dB (assumed terms); facade bias up to +2.4 dB before site correction | ±2 dB, 40 to 100 dBA | **At risk** |
| R4 | Measuring range | ICS-43434 34.9 to 113 dBA; IM72D128 27.9 to 113 dBA | 35 to 110 dBA | **At risk** (no margin with ICS-43434) |
| R5 | Frequency weighting | -2.8 dB at 63 Hz before equalizing, ±0.8 dB after; port resonance 36 kHz | Class 2 limits, 63 Hz to 8 kHz | **At risk** (membrane, windscreen, head) |
| R8 | Ingress and weather | FieldNode IP65; head skirt, membrane, bored windscreen | IP65; driving rain; -20 to +50 °C | Not verifiable at TRL 3 |
| R9 | Calibration check | Calibrator fits the head with the windscreen off; offset stored in the head | 10 min or less | Not verifiable at TRL 3 |
| R11 | Contaminated data | Level-based wind flag; server rain flag | Flag wind above 5 m/s and heavy rain | Not verifiable at TRL 3 (method chosen; threshold on hold with TRL 4) |
| R14 | Service life | ASA, yearly windscreen, FieldNode cell swap | 5 years | Not verifiable at TRL 3 |
| R10 | Installation and mass | 3.45 kg constructable design; arm factor 27 on yield; clamp twist factor 9.4; fits 60 to 140 mm poles | 3.5 kg or less; 35 m/s gusts; two people, 45 min | Met on paper on mass (margin 0.05 kg); wind met on paper; time not verifiable at TRL 3 |
| R12 | Radio use | 15 min at SF7 to SF9 (23.7 s/day at SF9); 24, 48 and 87 min at SF10 to SF12 (at most 30.0 s/day) | 1 % duty cycle; 30 s/day | Met on paper (interval rule) |
| R7 | Energy | 5.81 Wh/day stored against 0.29 Wh/day; 53 days without sun (16 cold, aged, upper bound) | Neutral at 1.5 h; 14 days | Met on paper |
| R13 | Parts cost | NoiseMap parts $72.00; full node $211.00 | NoiseMap parts at or under the $100 value-engineering target | Met on paper (USD 28.00 under the target) |
| R1 | Privacy | No storage or radio in the head; firmware sends levels only | Levels only; published build hash | Met by design (rests on firmware) |
| R2 | Reported metrics | 22 bytes per 15 min | Metric set per D5 | Met by design |
| R6 | Time stamps | LoRaWAN network time | Within 2 s of UTC | Met by design |
| R15 | Openness | Repo licenses; method and format here | All published | Met by design |

Counts [L2]: 0 not met, 3 at risk, 4 not verifiable at TRL 3, 4 met on paper, 4 met by design.

## Checks against the TRL 2 figures

| TRL 2 claim (NSM-PRC-001 v0.2) | This note | Action |
| --- | --- | --- |
| Range about 35 to 115 dBA | 34.9 (27.9 with IM72D128) to 113 dBA | Precis and README updated |
| Processor about 5 mA; head 18 mW; node 21 mW, 0.51 Wh/day | 2.15 mA; head 9.7 to 11.5 mW; node 12.2 mW, 0.29 Wh/day (22.6 mW upper bound) | Precis, README and flow updated |
| Autonomy about 30 days | 53 days (37 at -20 °C) | Updated |
| Winter harvest about 5.8 Wh/day | 5.81 Wh/day | Stands |
| Airtime about 24 s/day at SF9; 47 s at SF10 | 23.7 s and 47.4 s | Stands |
| Mass about 2.3 kg; R10 met | 3.45 kg for the constructable design against the relaxed 3.5 kg (v0.2: 3.45 kg pocketed; v0.1: 3.32 kg, with the V-blocks wrongly modeled as flat plates) | Updated per NSM-DDR-002 and NSM-DDR-003 |
| Wind load on the panel about 50 N | 52.2 N (FND-CAL-001); 16 N more on the arm and head | Updated |
| Cost about $171 (core $119, NoiseMap $52) | $211.00 (core $139.00, NoiseMap $72.00 with the adapter and construction parts) | BOM, precis and README updated |
| Microphone 0.45 m from the pole; arm about 400 mm | 0.45 m; arm tube 383 mm between the flange socket and the head socket | Stands |
| Cable "far too slow" for audio | Too slow for raw audio, fast enough for a speech codec | Precis wording follows D2 |

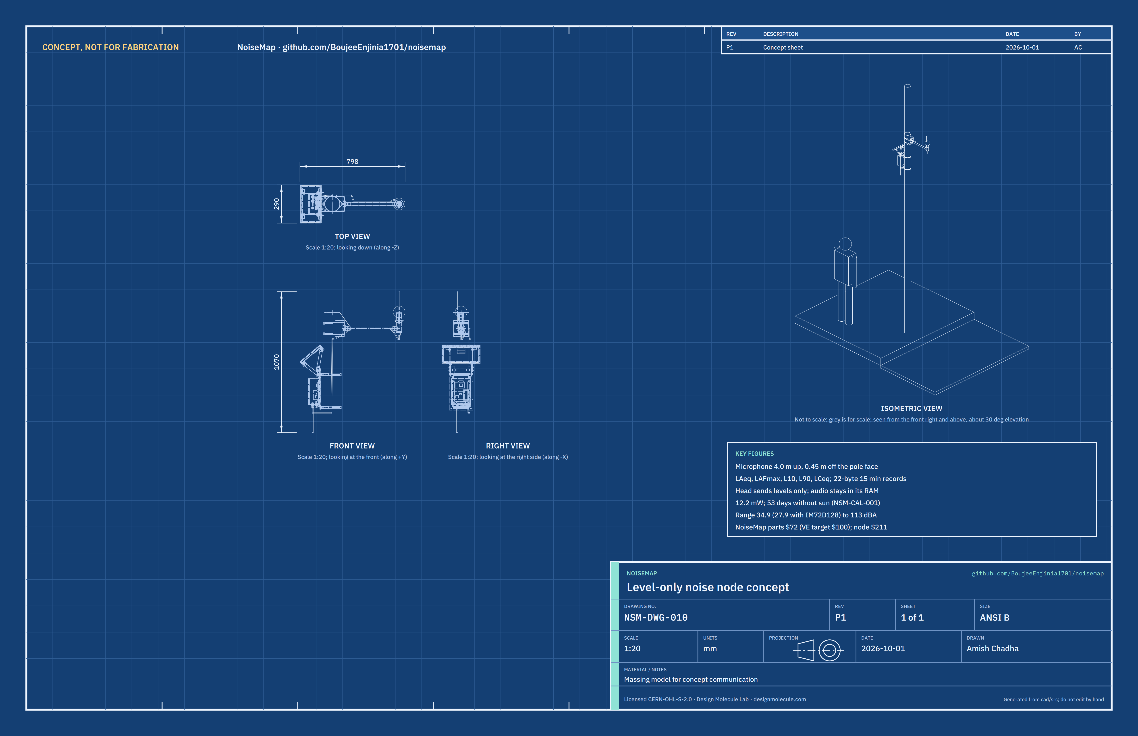
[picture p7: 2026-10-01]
media/concept-blueprint.png

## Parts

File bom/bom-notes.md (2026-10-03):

# BOM notes

Costs are indicative (September 2026 estimates) until suppliers are selected. Line numbers match the callouts in `media/exploded.png` and the part keys in `cad/src/model.py`. Every line is priced; `docs/04-calcs/sizing.py` reads this file and checks the totals (NSM-CAL-001, section I).

- Lines 1 to 6 are the standard FieldNode core, $139.00, priced as in the FieldNode BOM after its design for construction (FND-DDR-003). Under NSM-DDR-001 D1 (decided by Amish, 2026-09-25: go with recommendation) the core is costed in the FieldNode repo; its small-pole V-blocks and bands stay in its price but are not fitted on a street pole.
- Lines 7 to 14 are NoiseMap parts, estimated at $72.00. Value-engineering target: USD 100 (`budget_usd`, a hypothetical control target, not a limit); the estimate is USD 28.00 under it. The full node is $211.00.
- Line 14, the street pole adapter, is new at TRL 3: FieldNode's V-blocks seat poles up to 71 mm, and street poles are 60 to 140 mm. The NoiseMap V-blocks use the FieldNode back plate's own V-block screw holes and band slots, so the plate needs no new holes.
- A cup anemometer for wind flagging (about $25) is not included: the level-based wind flag was decided instead (NSM-DDR-002, O3).
- The V-blocks (line 14) are sawn from 16 mm bar with four drilled lightening holes, and the arm saddle (line 7) is bent from 2.5 mm sheet with two bands and a bought tube flange (NSM-DDR-003).
- A sound calibrator (94 dB at 1 kHz) is a shared lab tool and is not in the per-node cost (D7).
- The street pole is not part of the BOM.
- Line 12 names the M12 pin assignment (pin 1 3.3 V, pin 3 ground, pins 2 and 4 UART) and line 13 adds the 3.3 V port label, both from the decision of 2026-10-02 (NSM-DEC-001); neither changes a price.

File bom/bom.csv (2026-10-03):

item | qty | spec | supplier | unit_cost_usd | make_buy | notes
1 FieldNode enclosure | 1 | IP65 light grey polycarbonate box 150 x 90 x 200 mm (W x D x H) with gasketed lid, membrane vent, the maker's four external lugs and two M16 glands (FieldNode BOM lines 1 to 3) | FieldNode project; enclosure maker (Fibox, Hammond or Bud class) via an electrical distributor | 23.00 | buy | FieldNode core line; $20.00 box, vent and lugs plus 2 x $1.50 glands from the FieldNode BOM (FND-DDR-003); built to FND-BLD-001
2 FieldNode power and radio board | 1 | Charger and protection modules, STM32WL-class LoRaWAN module with 16 MB flash, sub-GHz whip antenna, two M12 5-pin sensor ports, printed internal plate, plug-in connector strip and rail fuses, FieldNode fixings (FieldNode BOM lines 7 to 11, 13 and 15) | FieldNode project; modules from an electronics distributor (DigiKey or Mouser class), RAKwireless or Seeed Studio | 76.00 | make | FieldNode core line; $22 + $14 + $10 + 2 x $6 + $4 + $9 + $5 from the FieldNode BOM; power board design is TRL 4 work, bought modules stand in for the prototype
3 LiFePO4 cell with fused holder | 1 | 32700 LiFePO4, 3.2 V, 6 Ah (about 19 Wh), charge 0 to 45 C; holder with inline 5 A fuse, 10 k NTC and plug-in lead (FieldNode BOM line 6) | Battery distributor (cell from a maker that publishes a datasheet) | 9.00 | buy | FieldNode core line; one cell gives about 53 days without sun at the NoiseMap design load (NSM-CAL-001)
4 Solar panel | 1 | 6 W monocrystalline, 9 V class, about 290 x 200 x 17 mm, aluminium frame with a flat back lip at least 12 mm wide, 1 m lead (FieldNode BOM line 4) | Solar or electronics distributor | 14.00 | buy | FieldNode core line
5 Panel tilt bracket | 1 | Two plate clips and four panel clips in 30 x 30 x 3 mm aluminium angle, two posts and two struts in 20 x 3 mm flat bar, 40 degree tilt (FieldNode BOM line 5) | Local make from metal stockist bar | 9.00 | make | FieldNode core line; made to FND-BLD-001
6 FieldNode pole mounting kit | 1 | Aluminium back plate 180 x 320 x 3 mm with window, band slots and fixing holes, with the FieldNode V-blocks and bands for 40 to 60 mm poles (FieldNode BOM line 12); on a street pole only the back plate is used | FieldNode project; local make plus hardware shop | 8.00 | make | FieldNode core line; the small V-blocks and bands stay in the FieldNode core price but are not fitted (NSM-DDR-003)
7 Microphone arm and saddle | 1 | Arm saddle: 5052-H32 aluminium sheet 2.5 mm, 114 mm wide, bent to a channel 124 x 65 mm with a 90 degree V in each flange, four band slots and three 5.5 mm holes; aluminium tube flange (railing floor flange) for 25 mm tube with set screw; 25 x 2 mm 6063 aluminium tube 382 mm; two 12 mm stainless worm-drive band clamps for 60 to 140 mm poles | Local metal supplier and bending shop; flange and bands from a hardware or railing fittings supplier | 16.00 | make | Indicative price; puts the microphone 0.45 m from the pole face; channel and two bands replace the milled saddle and its single band (NSM-DDR-003)
8 Microphone head housing | 1 | 3D-printed ASA head: tube 40 mm OD x 3 mm wall x 150 mm, 2 mm top plate with a 3 mm acoustic port, 45 degree drip skirt 64 mm OD with a spike boss, arm socket, card guides and microphone board bosses; printed ASA bottom cap; hydrophobic acoustic membrane over the port; two M3 heat-set inserts | Local print; membrane from an acoustic vent maker | 6.00 | make | Indicative material cost; ASA housing adopted for TRL 3 (NSM-DDR-001 D13); details added for construction (NSM-DDR-003)
9 MEMS microphone on adapter board | 1 | 28 mm round adapter board taking either an ICS-43434 (I2S, 65 dB SNR, 120 dB SPL AOP) or an IM72D128 (PDM, 72 dB(A) SNR) bottom-port MEMS microphone; two 2.2 mm mounting holes 20 mm apart; 0.5 mm closed-cell acoustic gasket | Electronics distributor (microphones); adapter board from a PCB prototyping service | 7.00 | buy | Indicative price; ICS-43434 is listed end of life by TDK; dual footprint adopted for TRL 3 (NSM-DDR-001 D3)
10 Level processor | 1 | Cortex-M4F class low-power board (STM32L4 class), at most 26 mm wide and 70 mm long, with SAI for I2S and DFSDM for PDM input, UART output, read-out protection; no external storage and no radio | Electronics distributor | 8.00 | buy | Indicative price; computes A and C weighted levels; audio stays in RAM; slides into the head's card guides
11 Foam windscreen and bird spike | 1 | Open-cell polyurethane foam ball 90 mm, UV-stabilized, bored 40 mm to push over the head; stainless rod 3 mm x 218 mm with an M3 thread on one end as a bird spike | Acoustic accessory supplier; rod from a hardware shop | 8.00 | buy | Indicative price; replace the foam about yearly (estimate)
12 Sensor cable | 1 | M12 5-pin A-coded sealed cable about 1.5 m, plug to the FieldNode sensor port, open end into the head through an M16 nylon cable gland (4 to 8 mm cable) in the bottom cap; carries 3.3 V on pin 1, ground on pin 3 and the UART pair on pins 2 and 4 (pin 5 not used in the head) | Industrial connector distributor | 9.00 | buy | Indicative price; pin assignment is FieldNode's candidate pinout, decided 2026-10-02 (NSM-DEC-001); gland added for construction (NSM-DDR-003)
13 Hardware and consumables | 1 | Stainless fixings: 4 x M4 x 12 countersunk screws (V-blocks), 3 x M5 x 16 button-head screws with nyloc nuts (flange), M5 x 45 and M4 x 40 cross bolts with nyloc nuts, 2 x M3 x 6 (cap), 2 x M2 x 3 (microphone board); stainless wire rope lanyard 2 mm with thimbles and ferrules; UV-stable cable ties at least 400 mm long; self-amalgamating tape; neutral-cure silicone; one printed UV-stable label 'PORT A 3.3 V' for the FieldNode port | Local hardware shop | 8.00 | buy | Indicative price; no exploded-view callout; port label included in the price (about $0.50)
14 Street pole adapter | 1 | Two aluminium V-blocks 112 x 63 x 16 mm with a 90 degree V (106 mm mouth), two 4.5 mm band rebates and four 14 mm lightening holes each, cut from 70 x 16 mm 6082 or 6061 flat bar and tapped M4 for the FieldNode back plate's V-block screws; two 12 mm stainless worm-drive band clamps for 60 to 140 mm poles (about 370 to 560 mm band) | Local make from aluminium bar; bands from a hardware shop | 10.00 | make | Indicative price; replaces the FieldNode small-pole V-blocks and bands on street poles (NSM-DDR-003)

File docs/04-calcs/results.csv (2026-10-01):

id | value | target | status
R3 | Expanded uncertainty 2.9 dB (assumed terms); facade bias up to +2.4 dB before a site correction | +/-2 dB from 40 to 100 dBA after field calibration | At risk
R4 | ICS-43434 34.9 to 113 dBA; IM72D128 27.9 to 113 dBA (AOP assumed) | 35 to 110 dBA | At risk (no margin at 35 dBA with ICS-43434; met with IM72D128)
R5 | Roll-off -2.8 dB at 63 Hz before equalizing; residual 0.8 dB after; port resonance 36 kHz (+0.4 dB at 8 kHz); membrane and head diffraction unknown | A and C weighting within class 2 limits, 63 Hz to 8 kHz | At risk (membrane, windscreen and head diffraction not verifiable at TRL 3)
R8 | FieldNode IP65 core; head with drip skirt, hydrophobic membrane and bored windscreen; IM72D128 is IP57 at part level | IP65; head survives driving rain; -20 to +50 C | Not verifiable at TRL 3 (by design)
R9 | Calibrator slides over the head after the windscreen is removed; offset stored in the head | Field check in 10 min or less; offset stored | Not verifiable at TRL 3 (timed trial)
R11 | Wind: level-based flag (Z weighted band below 40 Hz and its 1 s spread) against a threshold set in the field; rain: server flag from weather data | Flag intervals with wind above 5 m/s or heavy rain | Not verifiable at TRL 3 (method chosen; threshold needs field data, on hold with TRL 4)
R14 | ASA housing, UV-stabilized foam changed yearly, FieldNode cell swap | 5 years with yearly windscreen and one battery change | Not verifiable at TRL 3
R7 | 5.81 Wh/day stored at 1.5 h against 0.29 Wh/day (0.54 upper bound); 53 days without sun (16 cold, aged, upper bound) | Energy neutral at 1.5 peak sun hours; 14 days without sun | Met on paper
R10 | 3.45 kg with the constructable adapter and saddle; arm factor 27 on yield; clamp twist factor 9.4; fits 60 to 140 mm poles | 3.5 kg or less; 35 m/s gusts; two people in 45 min | Met on paper on mass (3.45 kg, margin 0.05 kg); wind met on paper; install time not verifiable at TRL 3
R12 | 15 min at SF7 to SF9 (23.7 s/day at SF9); interval rule 24, 48 and 87 min at SF10 to SF12 (at most 30.0 s/day); 1 % duty cycle met at all SF | EU868 1 % duty cycle and 30 s/day fair use | Met on paper (with the interval rule of NSM-DDR-002)
R13 | NoiseMap parts $72.00; full node $211.00 with the FieldNode core ($139.00) | NoiseMap parts at or under the $100 value-engineering target; FieldNode core costed in FieldNode | Met on paper (USD 28.00 under the value-engineering target)
R1 | Head has no data storage or radio; firmware sends levels only; cable could carry a speech codec, radio a few minutes a day | No audio stored or sent; head firmware published with a build hash | Met by design (rests on firmware, not physics)
R2 | 22 bytes per 15 min; wind flag and flagged-minute count in the status byte | 1-minute LAeq, LAeq, LAFmax, LAFmin, L10, L90, LCeq, status per 15 min | Met by design
R6 | Network time via LoRaWAN DeviceTimeReq; records stamped at the core; stored records carry a 4-byte time | Within 2 s of UTC | Met by design
R15 | CERN-OHL-S-2.0 and MIT; calibration method and record format in NSM-CAL-001 | All published | Met by design

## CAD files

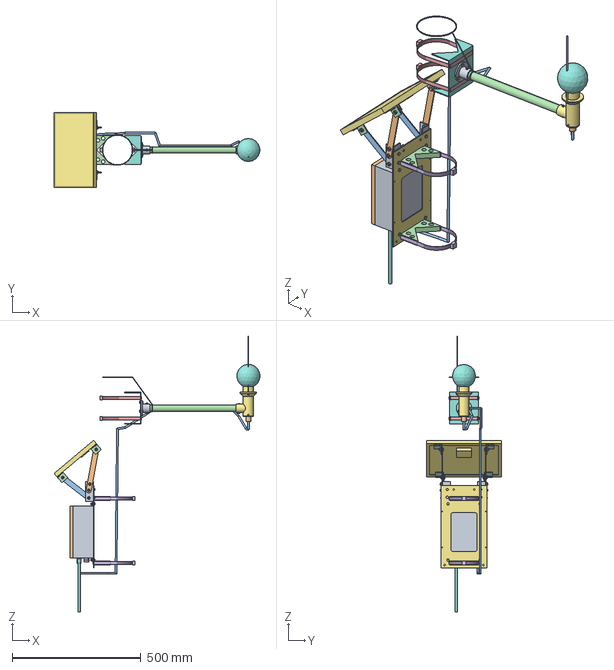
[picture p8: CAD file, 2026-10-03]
cad/step/noisemap-assembly.step
797.8 x 290.0 x 1070.0 mm

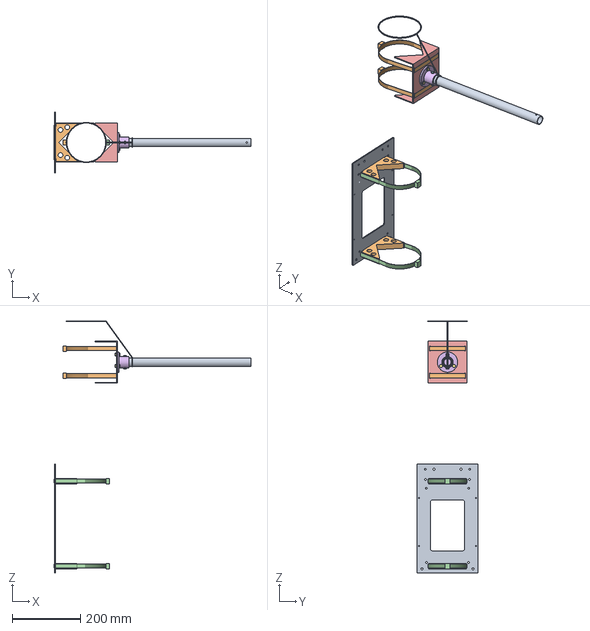
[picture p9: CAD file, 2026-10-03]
cad/step/noisemap-mount.step
578.8 x 180.0 x 741.0 mm

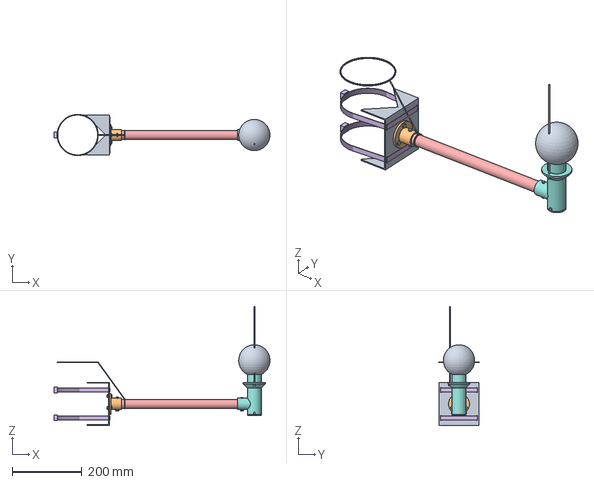
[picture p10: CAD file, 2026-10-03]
cad/step/noisemap-head.step
620.1 x 118.2 x 342.0 mm

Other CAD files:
cad/stl/noisemap-assembly.stl
cad/stl/noisemap-head.stl
cad/stl/noisemap-mount.stl

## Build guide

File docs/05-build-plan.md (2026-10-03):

---
doc_id: NSM-BLD-001
title: NoiseMap prototype build plan
project: NoiseMap
doc_type: Build plan
version: "0.3"
status: Draft
date: '2026-10-02'
author: Amish Chadha
license: CERN-OHL-S-2.0
revisions:
  - version: "0.1"
    date: '2026-10-01'
    author: Amish Chadha
    change: First build plan at TRL 3, with pictures by component and step; design made constructable (NSM-DDR-003)
  - version: "0.2"
    date: '2026-10-02'
    author: Amish Chadha
    change: NSM-DDR-003 accepted by Amish on 2026-10-02
  - version: "0.3"
    date: '2026-10-02'
    author: Amish Chadha
    change: M12 pin assignment (pin 1 3.3 V, pin 3 ground, pins 2 and 4 UART) shown on the wiring diagram and in the cable step; 3.3 V port label added to step 12 and the hardware line; Figure 13 redrawn
---

# NoiseMap prototype build plan

**Plan, not yet built.** How to build the first proof-of-concept prototype, component by component. Building and testing to it is TRL 4 work. Decisions still to be made are kept in the design decisions register ([docs/06-design-decisions.md](06-design-decisions.md)), not here.

## 1. What you are building

Figure 1. Every component, pulled apart and numbered in build order

*Figure 1. Every component pulled apart and numbered in build order. The pole is not shown.*

The prototype is one NoiseMap node on a 1.2 m length of 114 mm tube standing in for a street pole: a FieldNode core (a grey box with a battery cell, a radio and a solar panel) clamped to one side of the pole, and a microphone head on a short aluminium arm clamped higher up and pointing the other way, toward the street. The head is a printed tube with a microphone under a small port in its top, a level processor board inside, and a foam ball over the top. A cable carries sound levels, never audio, from the head to the core. Figure 1 shows the 15 components in the order you make or fit them. The FieldNode core is built to its own plan (FND-BLD-001) and fitted here with two larger V-blocks in place of its own. Six components are made in a small workshop: the two V-blocks, the arm saddle (a bent aluminium sheet that a local shop can bend), the arm tube, the printed head, its printed bottom cap and the bird spike. Everything else is bought and fitted. The work is sawing, filing, drilling and tapping aluminium, cutting a thread on a stainless rod, two 3D prints in ASA, and soldering and screwing bought boards into the head. The NoiseMap parts cost about $72 from the bill of materials; the FieldNode core is costed in its own repository.

> **Safety:** On a street the node is installed at 3.3 to 4.2 m beside traffic; that work needs the pole owner's written permission, a lift or a stable ladder with a second person, fall protection and traffic management, and must stay clear of overhead lines and of the electrical parts of a lighting pole. The FieldNode core holds a lithium iron phosphate cell of about 19 Wh: follow the cell stops in its own build plan. Cut aluminium and stainless edges are sharp: deburr everything. Printing ASA gives off fumes; print in a ventilated space. Keep loudspeakers and calibrators off your ears when you test the microphone.

## 2. What changed to make it buildable

The concept showed what the node does; some of its parts could not be made or fixed as drawn. Each change below keeps what the node does, and all of them are recorded in decision record NSM-DDR-003, accepted by Amish on 2026-10-02.

*Table 1. Changes from the concept.*

| Component | The concept had | The buildable design has | Why |
| --- | --- | --- | --- |
| FieldNode core | The old FieldNode massing model | The constructable FieldNode, built to its own plan, without its small-pole V-blocks and bands | One core design for the portfolio |
| Street pole V-blocks | Blocks 110 x 60 x 40 mm with milled pockets, no fixing, bands with nowhere to go | Blocks 112 x 63 x 16 mm sawn from bar, four drilled holes, on FieldNode's own screw holes; bands under a rebate and through FieldNode's own slots (Figures 2 to 4) | Workshop tools only; no new holes in the FieldNode plate; same mass |
| Arm saddle | A milled 10 mm plate with one band and no path for it | A bent 2.5 mm sheet channel with a V in each flange and two bands through its web (Figures 5 to 7) | A bending shop can make it; it seats 60 to 140 mm poles and resists twist twice as well |
| Arm to saddle and head | A tube with no fixing at either end | A bought tube flange on the saddle and a socket printed on the head, each with a cross bolt (Figures 8, 11) | No welding |
| Inside the head | Boards floating, open bottom, no gland | Card guides, two screws and a gasket for the microphone board, a printed bottom cap with a cable gland (Figures 12 to 14) | Every part held; the front cavity the calculations use is kept |
| Drip skirt | A flat overhang | The same skirt with a 45 degree cone under it | Prints without support |
| Windscreen and bird spike | A loose foam ball; a spike with nothing holding it | The foam a push fit on the head; the spike screwed into a boss on the skirt (Figure 19) | Both stay put in wind |
| Lanyard and cable | Listed but not placed | A lanyard round the pole and the arm; the cable routed and tied (Steps 11 and 12) | Real paths and fixings |

## 3. Making the components

Make and check each component before the assembly step that needs it. Sizes are in millimetres. "Back" on a V-block is the face that goes on the FieldNode back plate; "pole end" of the arm is the end at the saddle. Workshop tolerance is 0.5 mm unless a step says otherwise; drawings do not carry tolerances before TRL 4.

### 3.1 FieldNode core (built to its own plan)

**What it is.** The standard FieldNode: enclosure, cell, electronics, radio, two sensor ports, 6 W panel and bracket on a 180 x 320 x 3 mm aluminium back plate. Build it to the FieldNode build plan, FND-BLD-001, sections 3.1 to 3.8 and steps 2 to 10, with two differences: do not make or fit its small V-blocks (FND-BLD-001 section 3.2 and step 1) or its band clamps (step 12), and leave its sun shield off.

**How it fits the parts next to it.** The street pole V-blocks screw into the four countersunk holes the FieldNode back plate already has for its own V-blocks, and the street pole bands use the plate's four band slots (Figure 3). Nothing new is drilled in the plate.

**Check before moving on.** The FieldNode build plan's own checks and safety stops pass; the cell fuse stays out until its plan says otherwise.

### 3.2 Street pole V-blocks (make 2)

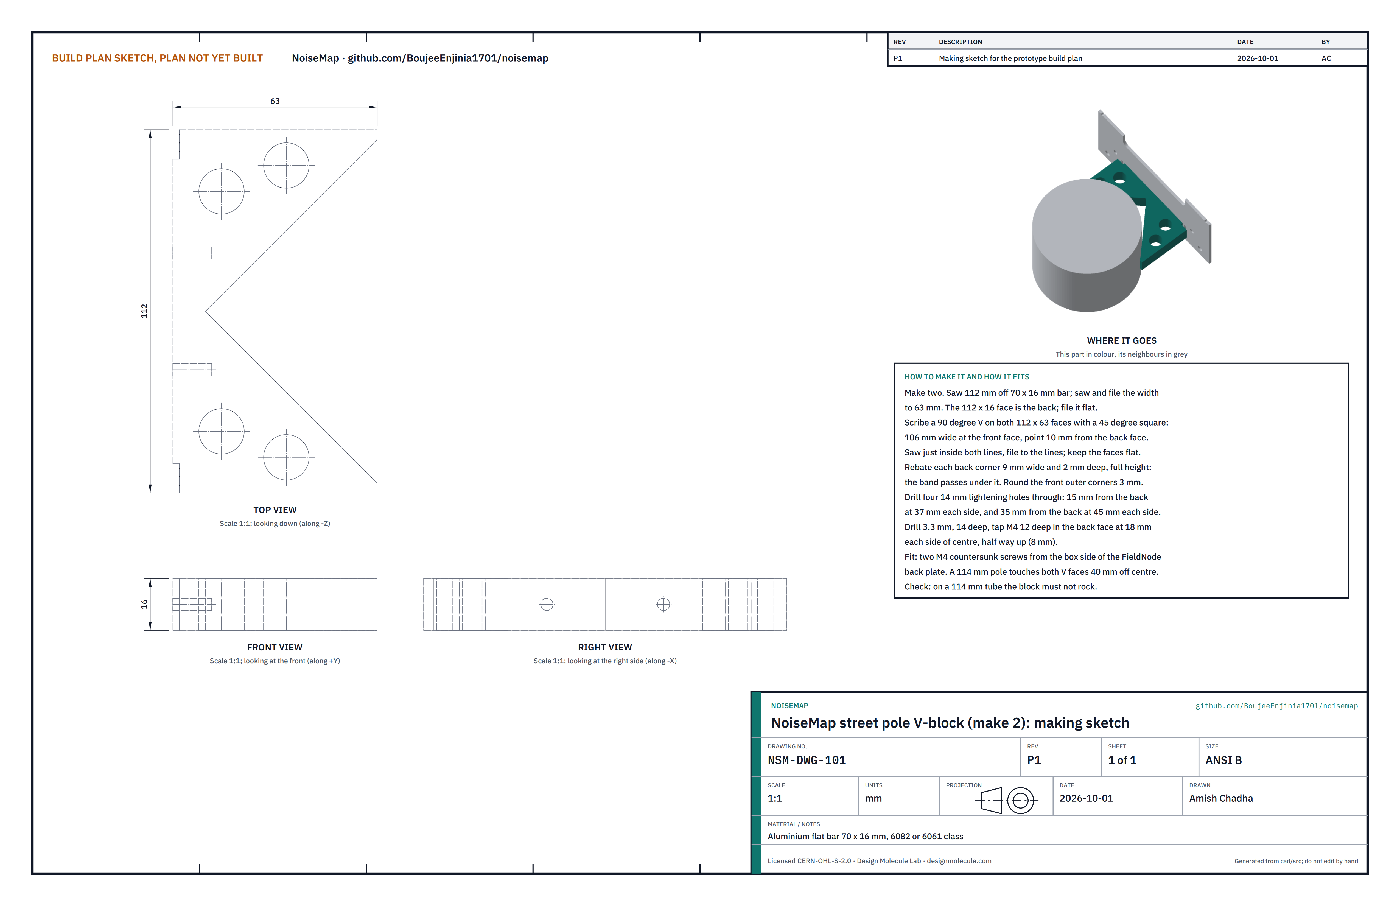
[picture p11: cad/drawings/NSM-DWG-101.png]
Figure 2. Making sketch of the street pole V-block


*Figure 2. Street pole V-block making sketch (NSM-DWG-101).*

**What it is and what it is made from.** A block with a V cut in it that the street pole sits in, one at each band. Aluminium flat bar 70 x 16 mm, 6082 or 6061 class.

**How to make it.**

1. Saw a 112 mm length off the bar for each block. Saw and file the width from 70 to 63. The 112 x 16 face on one long edge is the back; file it flat.
2. On both 112 x 63 faces, scribe the V with a 45° square: 106 wide at the front face, meeting at a point 10 from the back face, centred on the length.
3. Saw just inside both lines and file to them. Keep the two V faces flat and square to the block's faces.
4. At each back corner, file a rebate 9 wide and 2 deep, the full 16 height. The band runs under it.
5. Round the two front outer corners to about 3 mm and break the V's front edges by 0.5 mm so they cannot scratch the pole.
6. Drill four 14 mm lightening holes straight through: two 15 from the back face at 37 each side of centre, and two 35 from the back face at 45 each side of centre.
7. In the back face, half way up (8 from an edge), 18 each side of centre: drill 3.3 mm 14 deep and tap M4 12 deep.

**How it fits the parts next to it.**

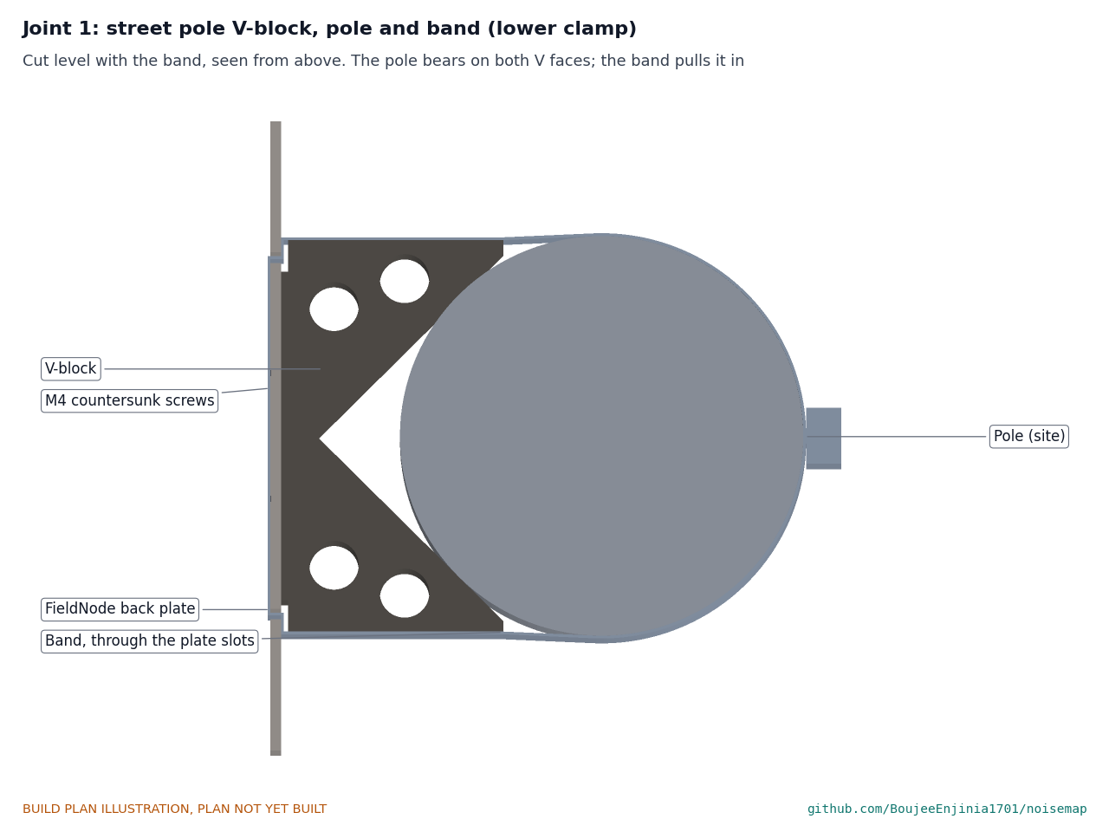
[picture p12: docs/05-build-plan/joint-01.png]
Figure 3. Joint 1: V-block, pole and band, seen from above


*Figure 3. The pole sits in the V and touches both faces; the band goes round the pole and pulls it into the V.*

The back face sits flat on the pole side of the FieldNode back plate, centred on the plate, one block on each band height (20 and 270 up from the plate's bottom edge). Two M4 x 12 countersunk screws go in from the box side of the plate into the tapped holes, with a drop of medium threadlocker. A 114 mm pole touches both V faces 40 mm each side of centre, about 13 mm in from the front face; poles from 60 to 140 mm also seat on both faces.

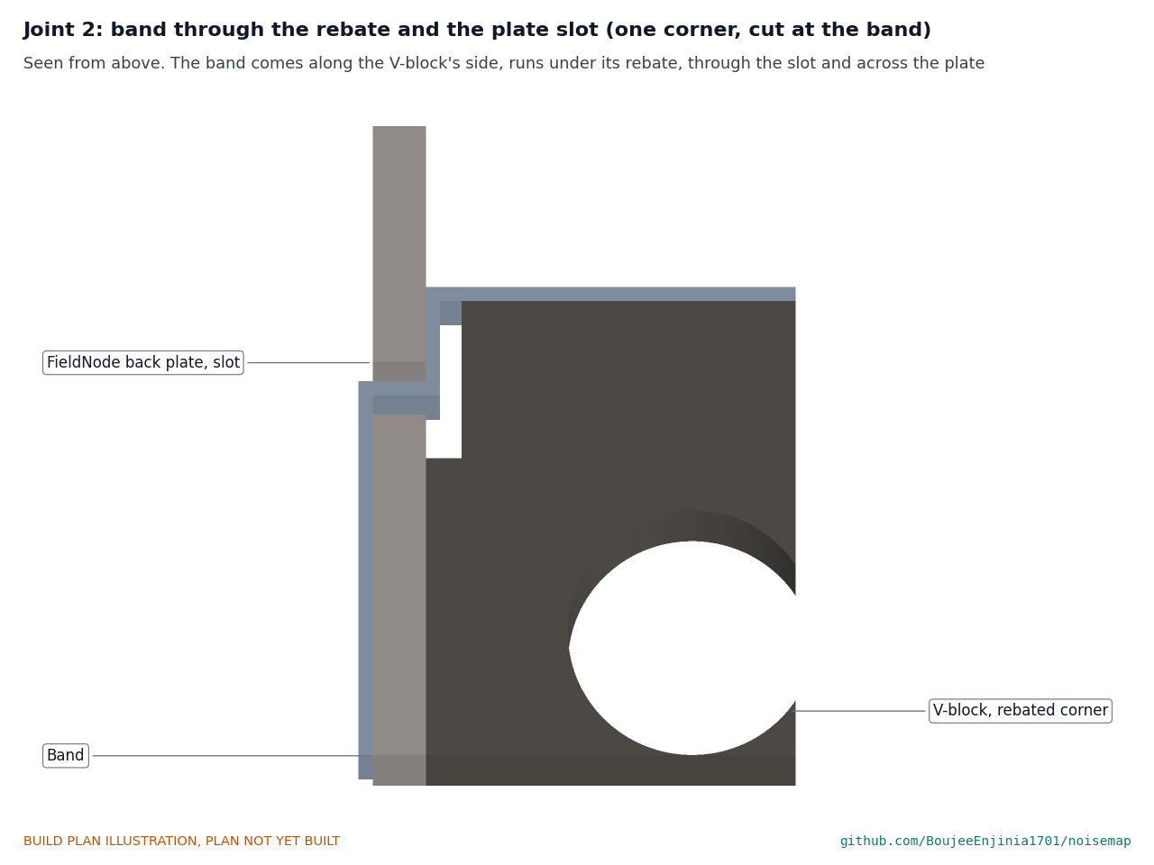
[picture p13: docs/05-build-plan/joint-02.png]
Figure 4. Joint 2: the band through the rebate and the plate slot


*Figure 4. Each band comes along the side of the block, runs under the rebate, passes through the plate's band slot and crosses the box side of the plate.*

**Check before moving on.** Hold a block against a 114 mm tube: it must not rock, and light shows at the bottom of the V but not along its faces. Screw it to the plate: it sits flat with the screw heads flush on the box side.

### 3.3 Arm saddle

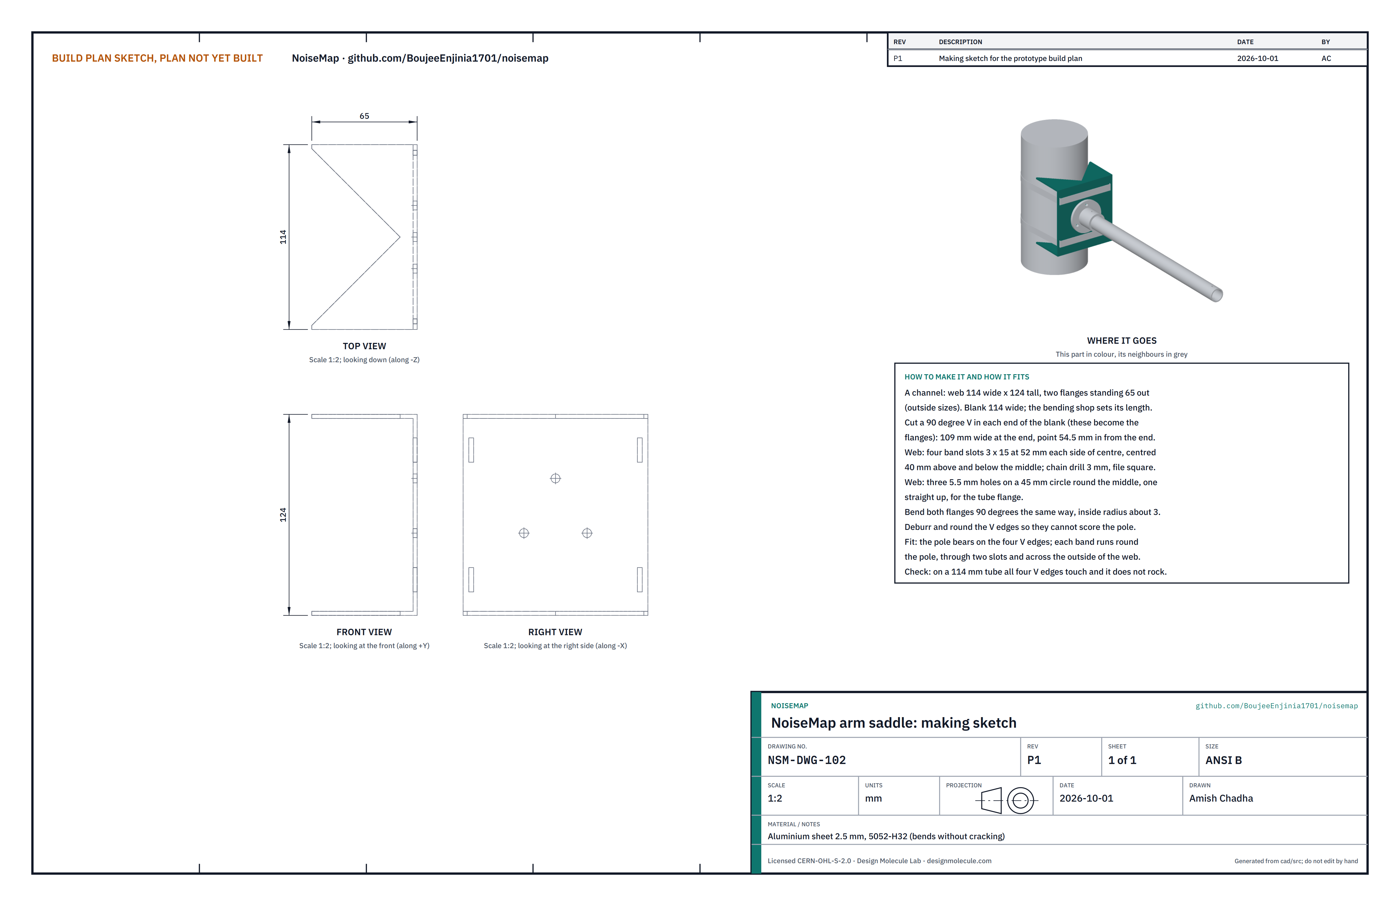
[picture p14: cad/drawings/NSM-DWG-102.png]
Figure 5. Making sketch of the arm saddle


*Figure 5. Arm saddle making sketch (NSM-DWG-102).*

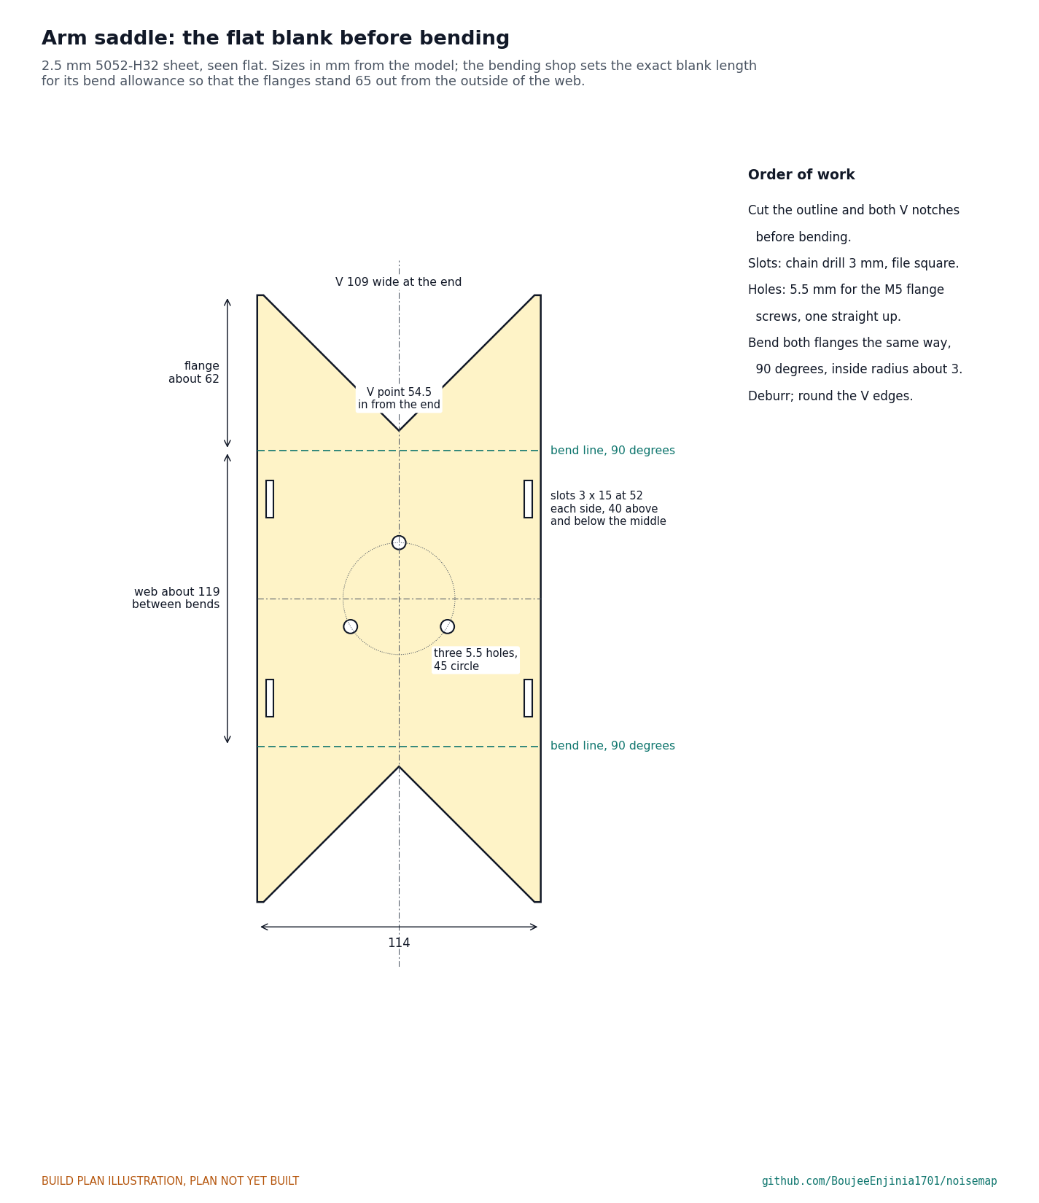
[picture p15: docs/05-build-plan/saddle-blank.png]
Figure 6. The flat blank before bending


*Figure 6. The flat blank with every cut and hole, measured from the centre lines.*

**What it is and what it is made from.** The bracket that the arm bolts to and that two bands pull against the pole. Aluminium sheet 2.5 mm, 5052-H32 (it bends without cracking), bent into a channel 114 wide, 124 tall and 65 deep.

**How to make it.**

1. Cut a blank 114 wide. Ask the bending shop for its length for their bend allowance: the web must be 124 outside, and each flange must stand 65 out from the web's outer face. About 243 is a starting figure.
2. At each end of the blank (these become the flanges) mark a 90° V centred on the width: 109 wide at the end, its point 54.5 in from the end. Cut with snips or a jigsaw and file to the lines.
3. On the web, mark the centre (Figure 6). Cut four band slots 3 wide and 15 tall, 52 each side of the centre line, centred 40 above and 40 below the centre: chain drill 3 mm and file square.
4. Drill three 5.5 mm holes on a 45 mm circle round the centre, one straight up toward a flange and the other two 120° from it. Check them against the tube flange you bought before drilling (section 3.9).
5. Bend both flanges 90° the same way, inside radius about 3.
6. Deburr every edge and hole. Round the V edges with a file so they cannot score a galvanised pole.

**How it fits the parts next to it.**

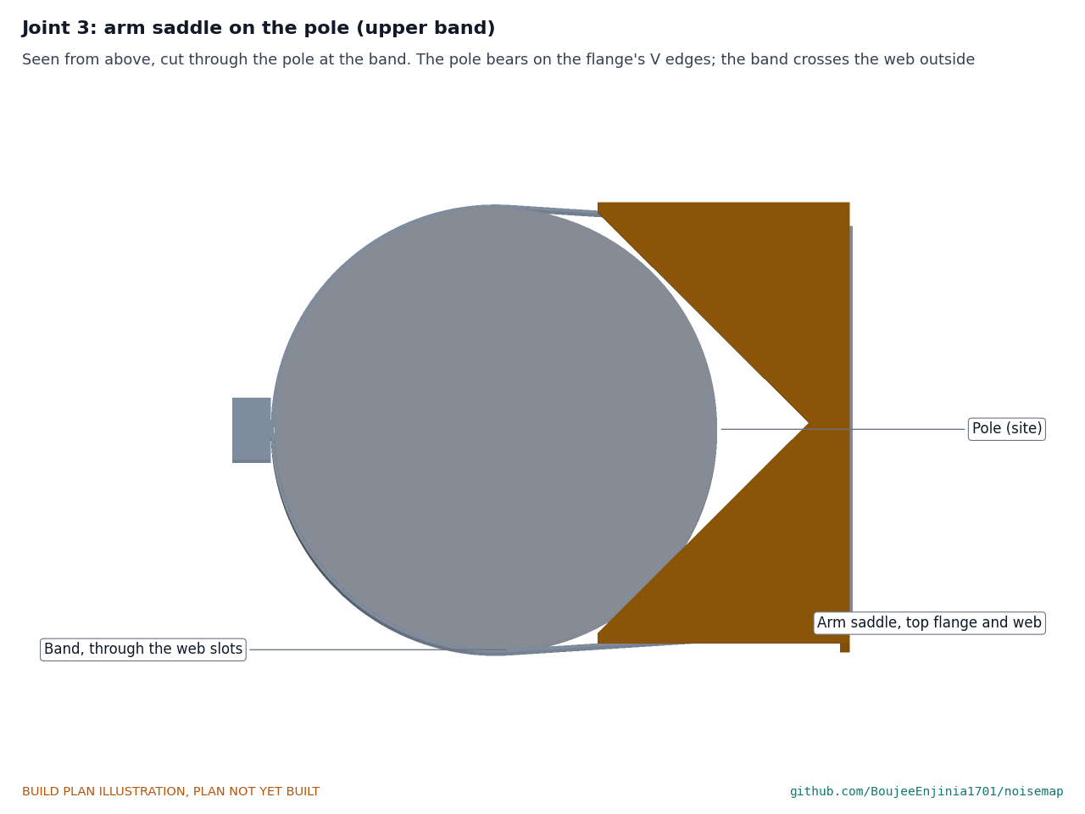
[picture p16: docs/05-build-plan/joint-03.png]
Figure 7. Joint 3: arm saddle on the pole, seen from above


*Figure 7. The pole bears on the V edges of both flanges; each band runs round the pole, through two slots and across the outside of the web.*

The flanges point at the pole and the web faces the street. A 114 mm pole touches each V 40 mm each side of centre; a 140 mm pole 49.5 mm, still 5 mm inside the mouth. The tube flange sits on the outside of the web between the two bands, 4 mm clear of each.

**Check before moving on.** On a 114 mm tube all four V edges touch and the saddle does not rock; the web is square to the tube.

### 3.4 Arm tube

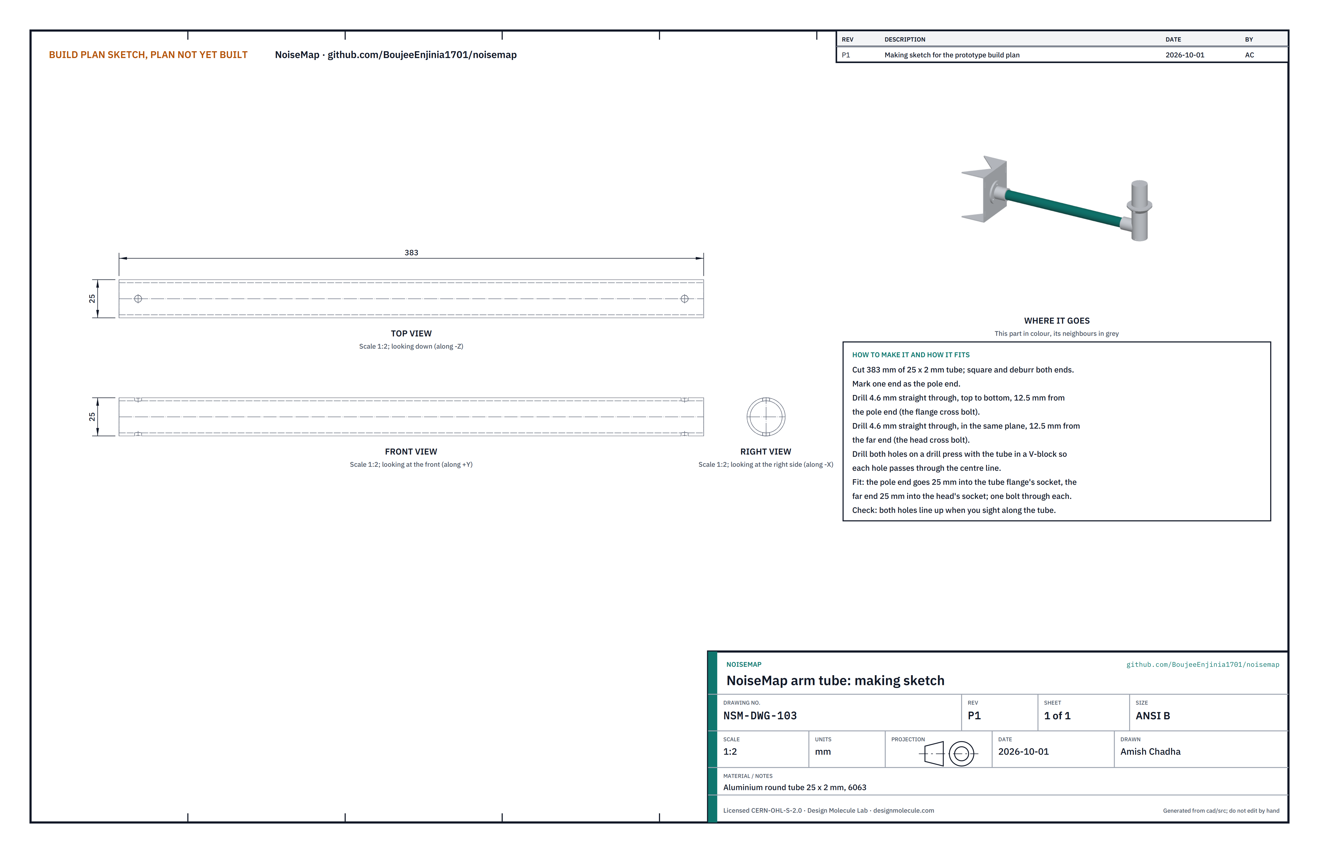
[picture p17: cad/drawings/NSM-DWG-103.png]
Figure 8. Making sketch of the arm tube


*Figure 8. Arm tube making sketch (NSM-DWG-103).*

**What it is and what it is made from.** The arm that holds the head 0.45 m out from the pole face. Aluminium round tube 25 x 2 mm, 6063.

**How to make it.**

1. Cut 383 of tube; square and deburr both ends. Mark one end "pole".
2. On a drill press, with the tube in a V-block, drill a 4.6 mm hole straight through on the centre line 12.5 from the pole end, and another 12.5 from the far end, both in the same plane.

**How it fits the parts next to it.**

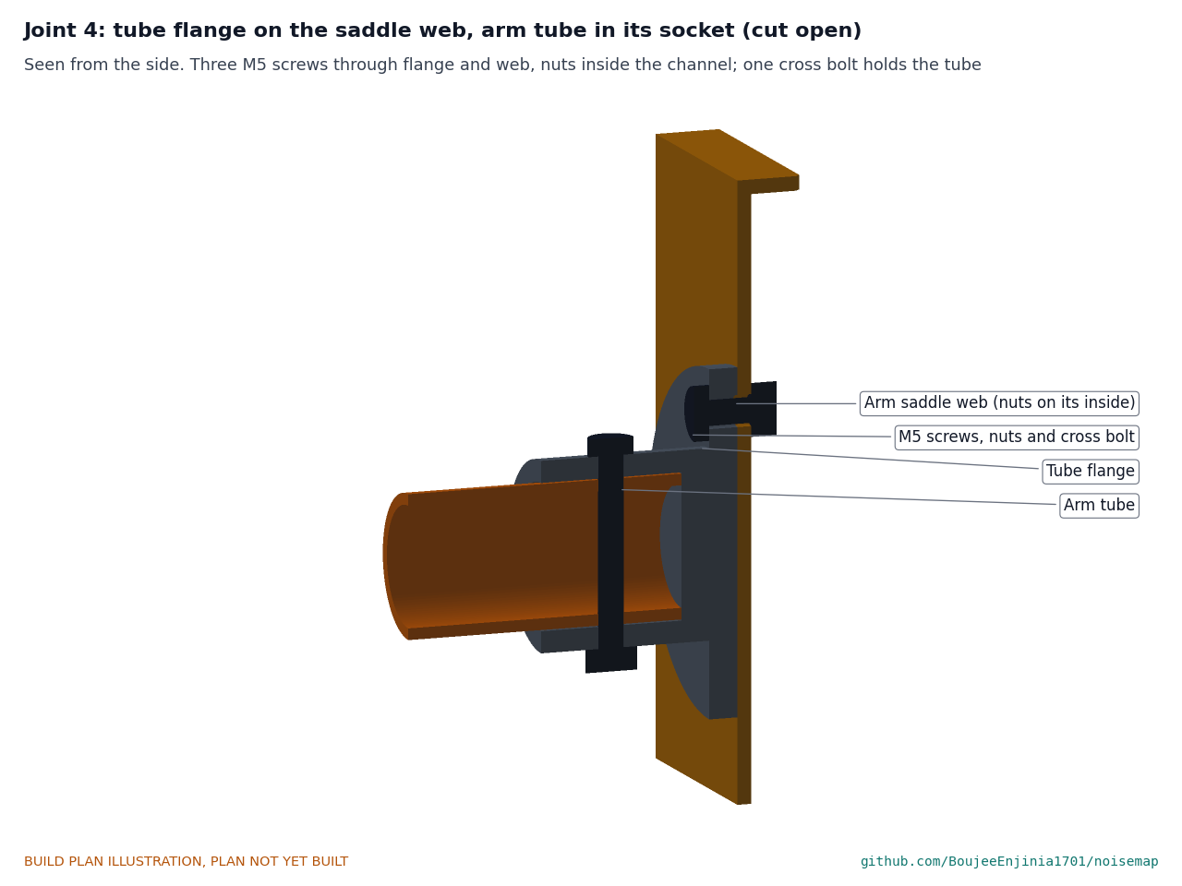
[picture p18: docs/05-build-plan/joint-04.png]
Figure 9. Joint 4: tube flange on the saddle web, arm tube in its socket


*Figure 9. Three M5 screws hold the flange to the web, nuts inside the channel; the tube goes 25 mm into the socket and one M5 bolt passes through both.*

The pole end goes to the bottom of the tube flange's socket with its hole lined up with the hole you drill in the socket (section 3.9); the far end goes to the bottom of the head's socket (Figure 11).

**Check before moving on.** Sight along the tube: the two holes line up.

### 3.5 Head housing

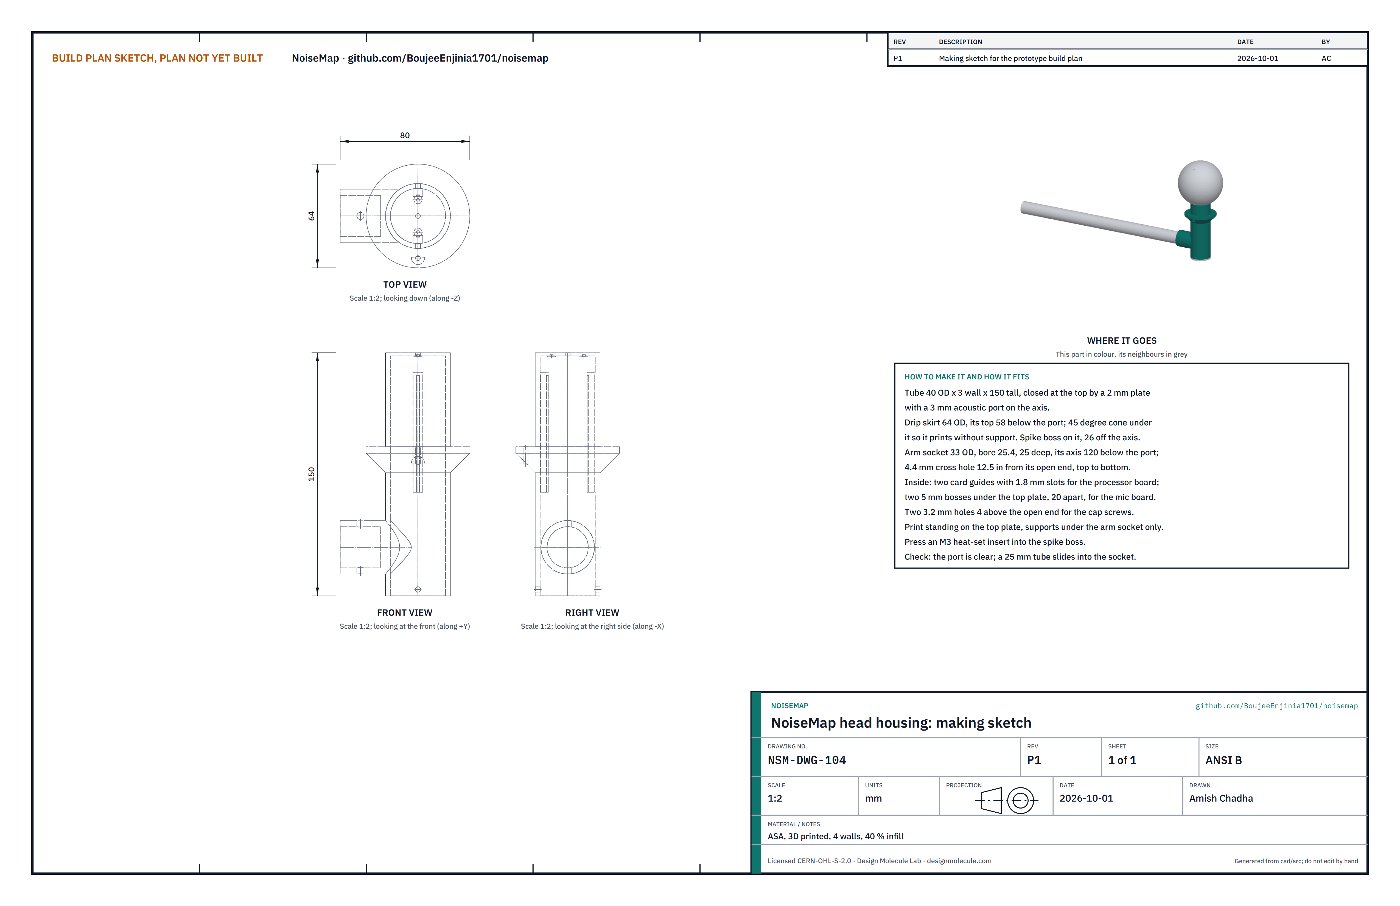
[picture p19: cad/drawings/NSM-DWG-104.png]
Figure 10. Making sketch of the head housing


*Figure 10. Head housing making sketch (NSM-DWG-104).*

**What it is and what it is made from.** The printed tube that carries the microphone at its top, the processor inside, the windscreen and spike outside, and the arm socket on its side. ASA, printed with 4 walls and 40 % infill in an enclosed printer.

**How to make it.**

1. Print it standing on its top plate, with supports under the arm socket only. It is a tube 40 OD with a 3 wall, 150 tall, closed at the top by a 2 mm plate with a 3 mm acoustic port on the axis. A 64 mm drip skirt sits 58 below the port, with a 45° cone under it and a spike boss on it 26 from the axis. Inside are two card guides with 1.8 mm slots and two 5 mm bosses under the top plate, 20 apart.
2. Let it cool on the bed. Clear the port with a 3 mm drill turned by hand; it must be round and open.
3. Open the arm socket's cross hole to 4.4 mm and the two cap screw holes, 4 above the open end, to 3.2 mm.
4. Press an M3 heat-set insert into the spike boss with a soldering iron, square to the skirt.

**How it fits the parts next to it.**

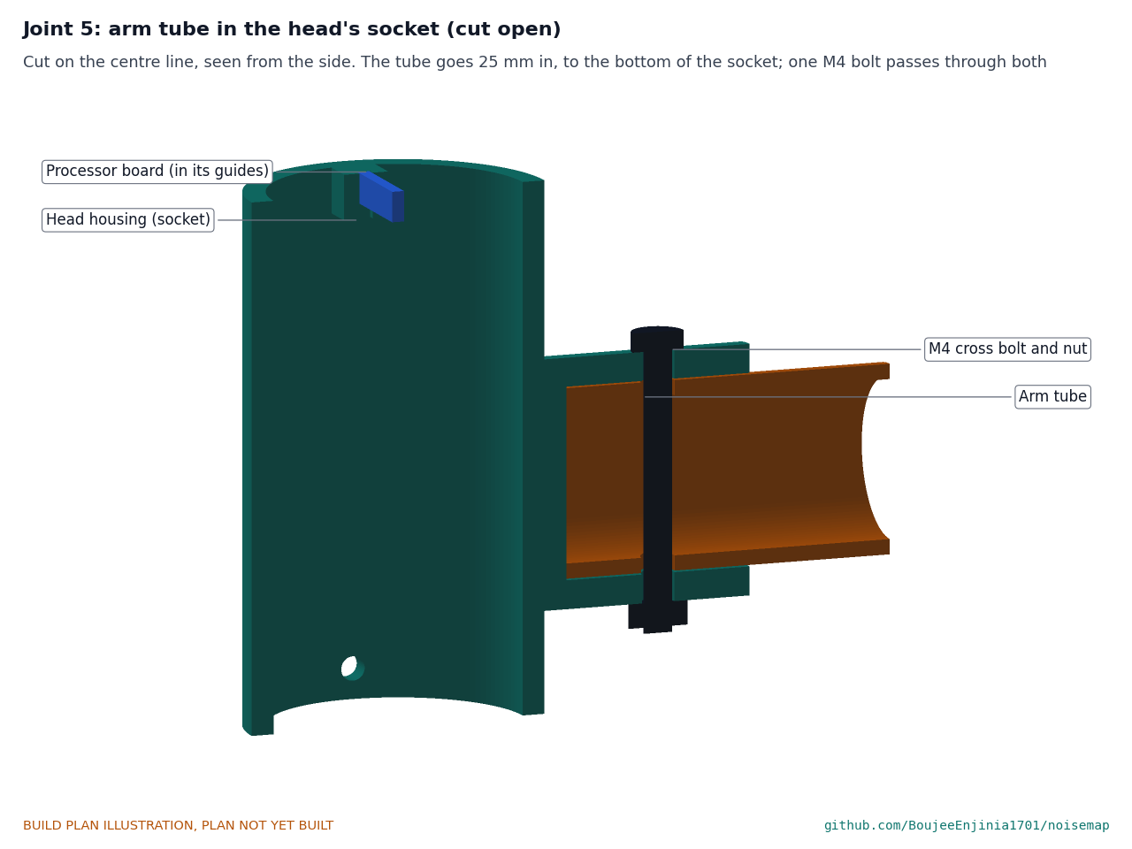
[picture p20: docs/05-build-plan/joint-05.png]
Figure 11. Joint 5: arm tube in the head's socket


*Figure 11. The tube goes to the bottom of the 25 mm socket, 120 below the port, and one M4 bolt passes through both.*

**Check before moving on.** The port is clear; a 25 mm tube slides into the socket to the bottom; light shows straight through the port.

### 3.6 Microphone board, gasket and membrane (bought, fitted into the head)

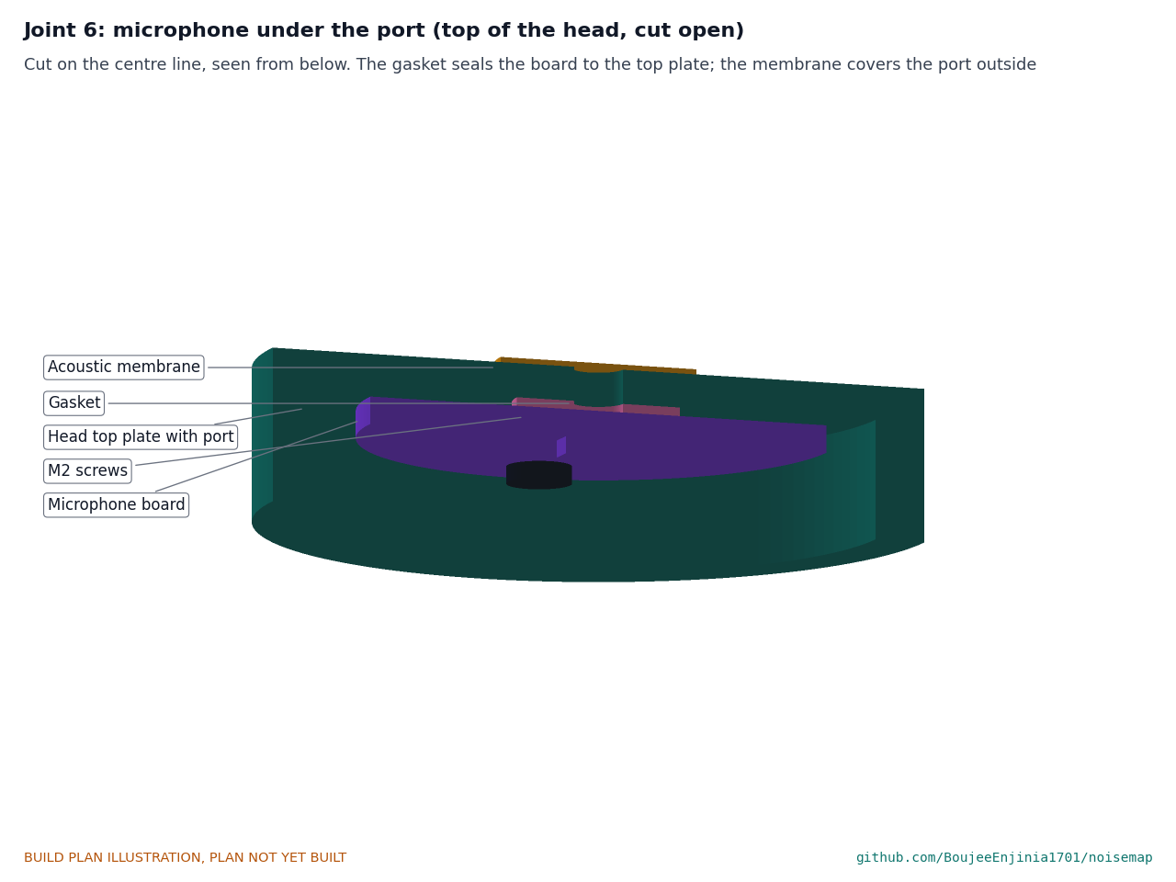
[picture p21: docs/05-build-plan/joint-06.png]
Figure 12. Joint 6: the microphone under the port


*Figure 12. The board sits on its two bosses, 0.5 mm under the top plate; the gasket ring round the port seals it, so the sound path is the port and the small space inside the gasket. The membrane covers the port outside.*

**What it is.** A 28 mm round adapter board with a bottom-port MEMS microphone (an ICS-43434 or an IM72D128) mounted underneath, its sound hole facing up through the board; a 0.5 mm closed-cell gasket ring 10 OD with a 3 mm hole; and a hydrophobic acoustic membrane about 12 mm across.

**How to fit it.** Stick the gasket on the board, centred on the board's sound hole. Push the board up the open end of the head, microphone side down, onto the two bosses, with the sound hole under the port. Fix it with two M2 x 3 screws. Stick the membrane over the port outside, pressing it flat with no creases.

**Check before moving on.** Looking down the port with a light below, you see the board's sound hole; the board does not move.

### 3.7 Level processor board and wiring

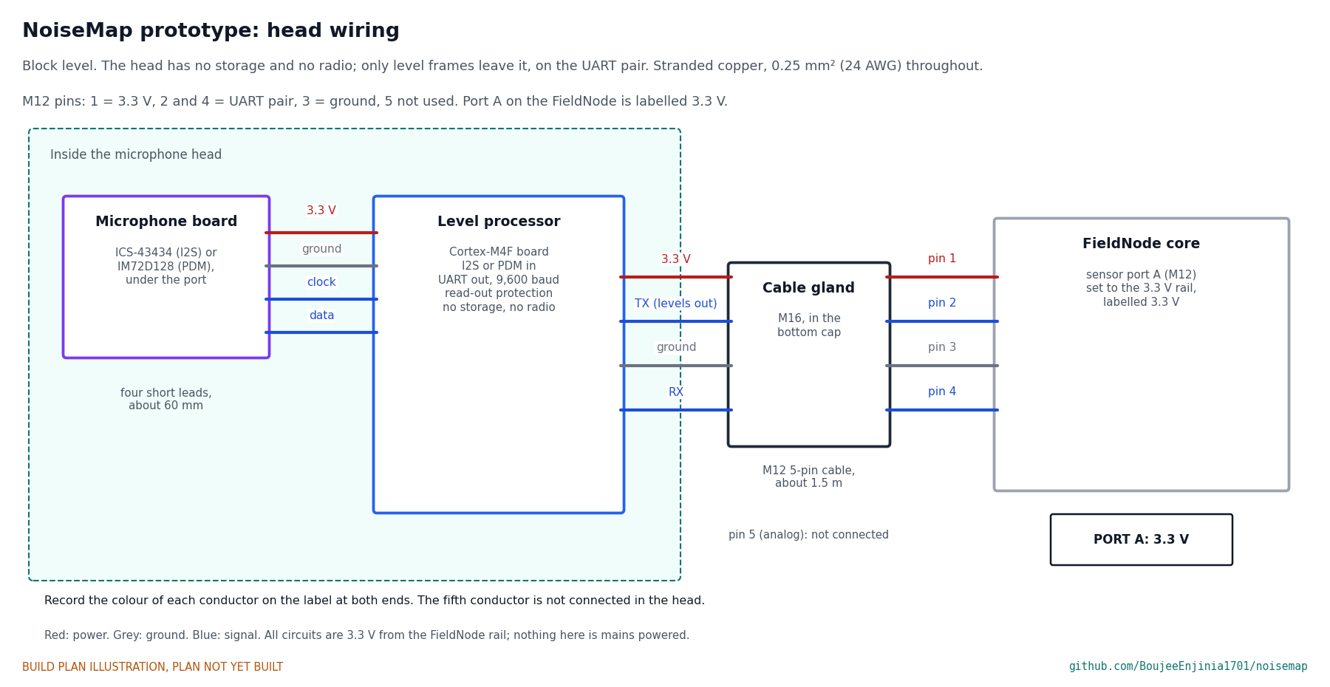
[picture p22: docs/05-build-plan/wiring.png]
Figure 13. Head wiring


*Figure 13. Block-level wiring of the head, with the M12 pin numbers and the 3.3 V label for the FieldNode's port A.*

**What it is.** A Cortex-M4F class low-power board (STM32L4 class) with an I2S or PDM input, a UART and read-out protection, no storage and no radio, at most 26 wide and 70 long.

**How to fit it.** Solder four short leads (about 60, 0.25 mm²) from the microphone board to the processor board: 3.3 V, ground, clock and data. Slide the processor board up the card guides, components facing away from the arm socket, until it stops 12 below the top plate. A dab of neutral-cure silicone at the bottom of each guide holds it. Load the open, published head firmware and record its build hash before the board goes in.

**Check before moving on.** No lead is pinched; the board does not touch the microphone board.

### 3.8 Bottom cap, cable gland and sensor cable

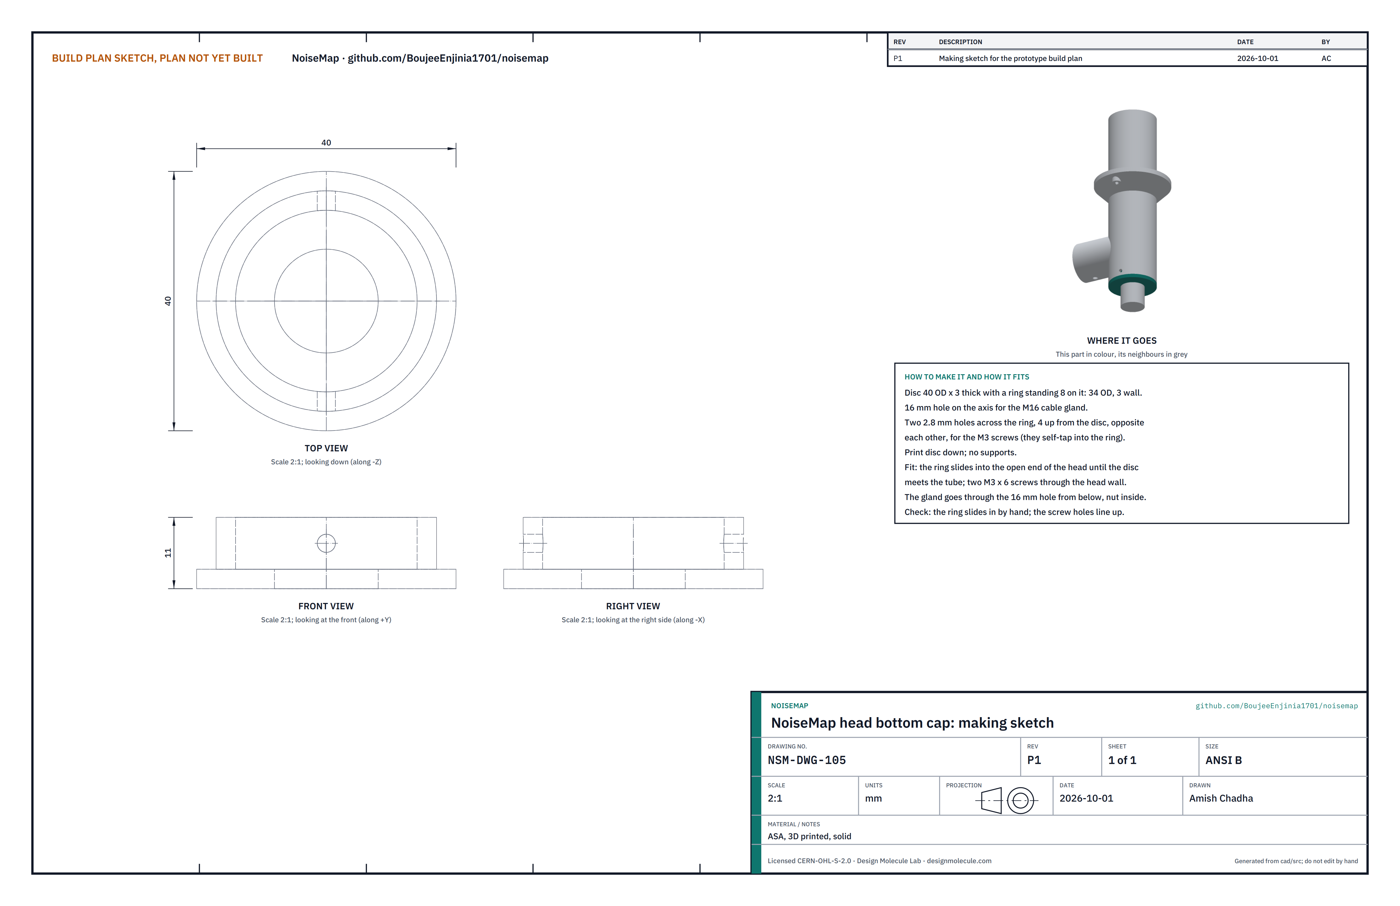
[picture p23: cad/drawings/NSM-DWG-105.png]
Figure 14. Making sketch of the bottom cap


*Figure 14. Bottom cap making sketch (NSM-DWG-105).*

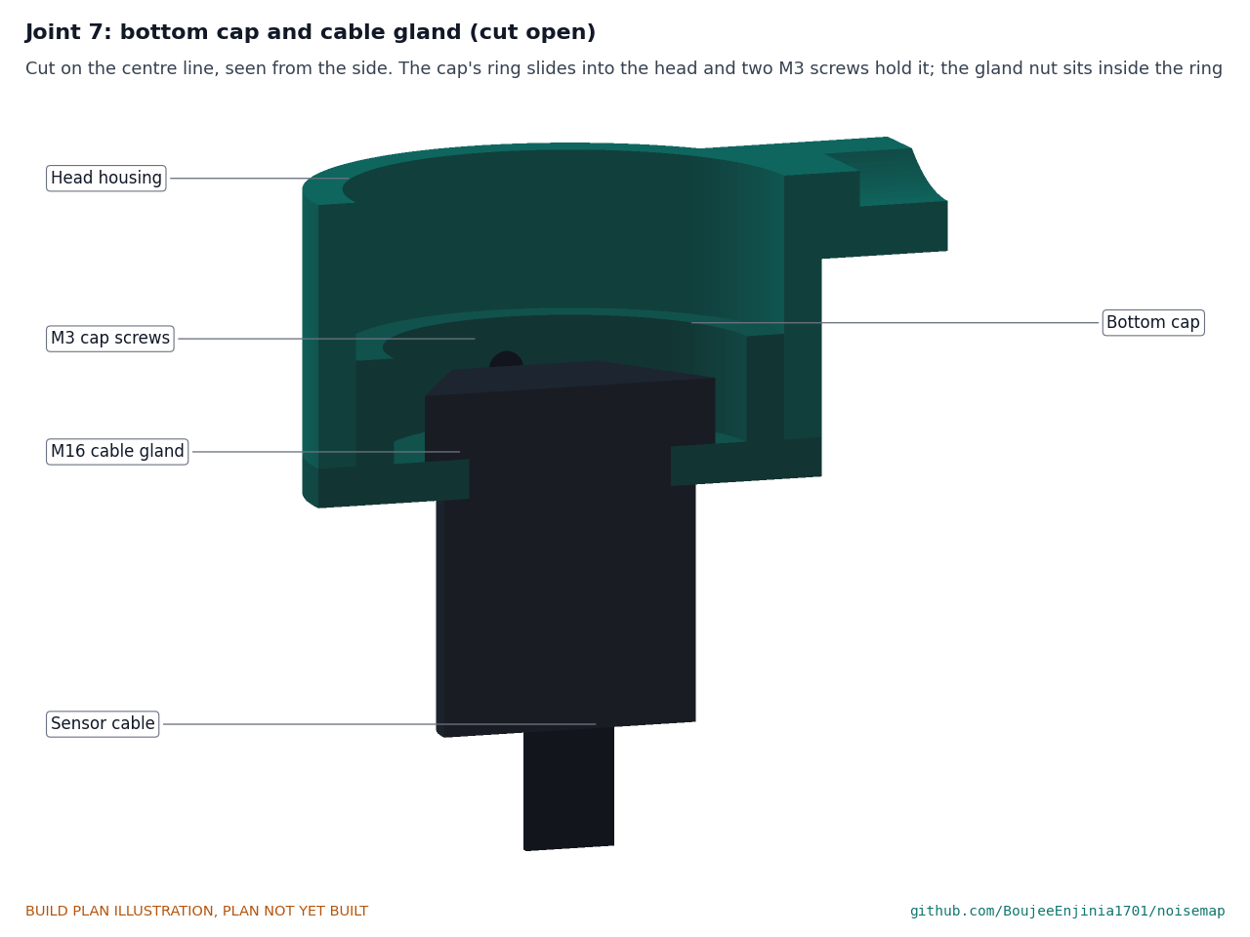
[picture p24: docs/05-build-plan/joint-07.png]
Figure 15. Joint 7: bottom cap and cable gland


*Figure 15. The cap's ring slides into the open end of the head and two M3 screws through the wall hold it; the gland nut sits inside the ring.*

**What it is and what it is made from.** The cap is printed ASA, solid: a disc 40 OD x 3 with a ring 34 OD, 3 wall and 8 tall standing on it, a 16 mm hole on the axis and two 2.8 mm holes across the ring, 4 up from the disc. The gland is an M16 nylon cable gland for 4 to 8 mm cable. The cable is a sealed M12 5-pin cable about 1.5 m long with a plug on one end.

**How to make and fit it.**

1. Print the cap disc down, without supports.
2. Fit the gland through the cap's hole from below, nut inside the ring.
3. Pass the cable's open end up through the gland and the cap. Strip it and solder the conductors that go to M12 pin 1 (3.3 V), pin 3 (ground), pin 2 (the processor's transmit, levels out) and pin 4 (its receive) to the processor board (Figure 13). Pin 2 and pin 4 are the UART pair of the FieldNode's own pinout. Write the colour of each conductor on a label at both ends; the fifth conductor (pin 5, analog) is not used in the head.
4. Push the cap's ring into the head, lining up the screw holes, and fit two M3 x 6 screws through the wall into the ring. Tighten the gland on the cable.

**Check before moving on.** The cap sits flat against the end of the head; the cable cannot be pulled through the gland by hand.

### 3.9 Tube flange (bought, drilled)

**What it is.** An aluminium tube flange of the kind sold for 25 mm railings: a base disc about 60 across with three holes, and a socket for a 25 mm tube with a set screw.

**What to do to it.** Check that its three holes fall on a 45 mm circle; if not, drill the saddle web to match the flange. Drill a 4.6 mm hole straight through its socket, 12.5 from the socket's open end, square to the base, so that it lines up with the hole in the tube (Figure 9).

### 3.10 Bird spike and windscreen

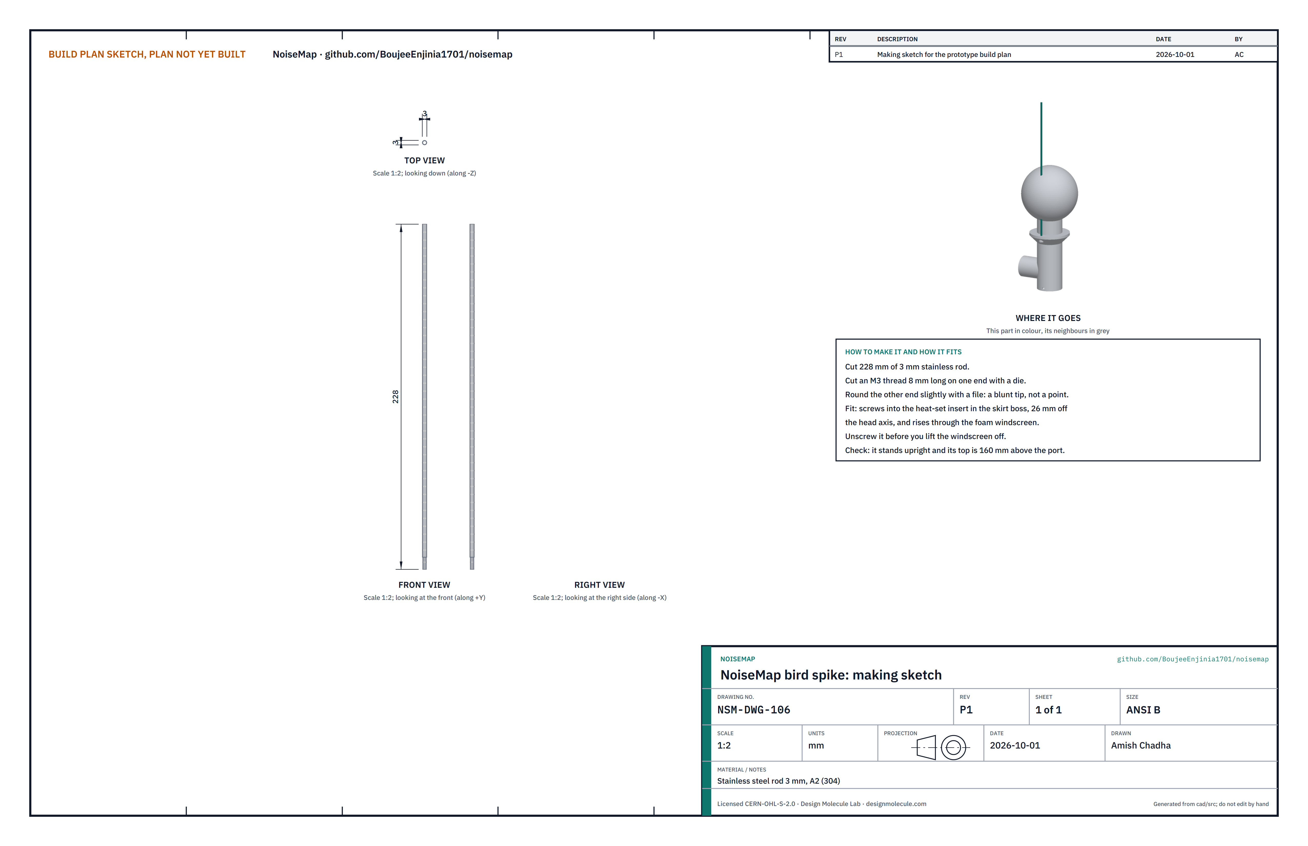
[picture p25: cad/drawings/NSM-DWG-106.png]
Figure 16. Making sketch of the bird spike


*Figure 16. Bird spike making sketch (NSM-DWG-106).*

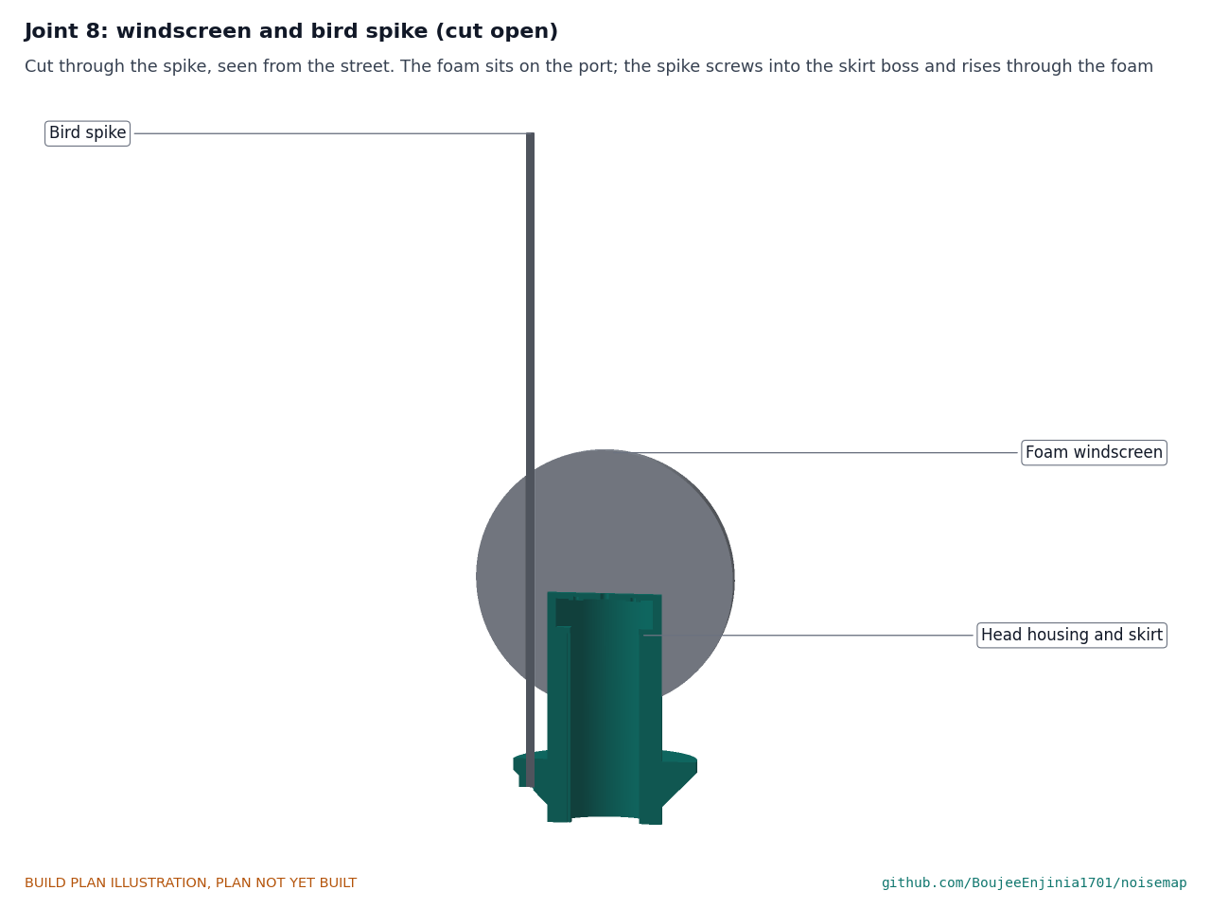
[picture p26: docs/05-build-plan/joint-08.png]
Figure 17. Joint 8: windscreen and bird spike


*Figure 17. The foam is pushed over the head until it sits on the port; the spike screws into the boss on the skirt and rises through the foam.*

**What it is and what it is made from.** The spike is 228 of 3 mm stainless rod (A2, 304) with an M3 thread 8 long on one end. The windscreen is a 90 mm open-cell, UV-stabilised polyurethane foam ball bored 40 mm to the centre, as sold for outdoor sound level meters.

**How to make it.** Cut the rod, cut the thread with a die, and round the other end with a file so it is blunt. If the ball is not bored, bore it 40 mm to just past its centre with a sharpened 40 mm tube turned by hand.

**How it fits the parts next to it.** The foam pushes down over the head until the bore's end sits on the membrane. The spike goes down through the foam, 26 off the axis, and screws into the insert by hand. Its top stands about 160 above the port. To lift the foam off for a calibration check, unscrew the spike first.

**Check before moving on.** The foam does not turn on the head when you twist it gently; the spike stands upright.

### 3.11 Bought components

Buy to specification, not brand. Line numbers are those of the bill of materials.

- **FieldNode core (lines 1 to 6).** As the FieldNode bill of materials.
- **Tube flange and bands (line 7).** Aluminium railing floor flange for 25 mm tube; two 12 mm stainless worm-drive band clamps that close on poles from 60 to 140 mm (bands about 370 to 560 mm), for the arm saddle.
- **Head parts (line 8).** Hydrophobic acoustic membrane about 12 mm, from an acoustic vent maker; two M3 heat-set inserts (one spare for the spike boss is wise).
- **Microphone board (line 9).** A 28 mm adapter board for an ICS-43434 or an IM72D128, with two 2.2 mm holes 20 apart; a 0.5 mm closed-cell gasket.
- **Level processor (line 10).** As section 3.7.
- **Windscreen and spike (line 11).** As section 3.10.
- **Sensor cable and gland (line 12).** As section 3.8.
- **Fixings and consumables (line 13).** Stainless: 4 x M4 x 12 countersunk screws (V-blocks); 3 x M5 x 16 button-head screws with nyloc nuts (flange); an M5 x 45 and an M4 x 40 bolt with nyloc nuts (cross bolts); 2 x M3 x 6 (cap); 2 x M2 x 3 (microphone board); 2 mm stainless wire rope with two thimbles and four ferrules for the lanyard; UV-stable cable ties at least 400 long; self-amalgamating tape; neutral-cure silicone; medium threadlocker.
- **Street pole bands (line 14).** Two more 12 mm stainless worm-drive band clamps for 60 to 140 mm poles.

## 4. Putting it together

In each picture the parts already fitted are grey and the part being fitted is in colour, with an arrow showing the way it goes in. Steps 1 to 8 are done on the bench; steps 9 to 12 on the pole stub held upright in a stand.

### Step 1: street pole V-blocks onto the FieldNode back plate

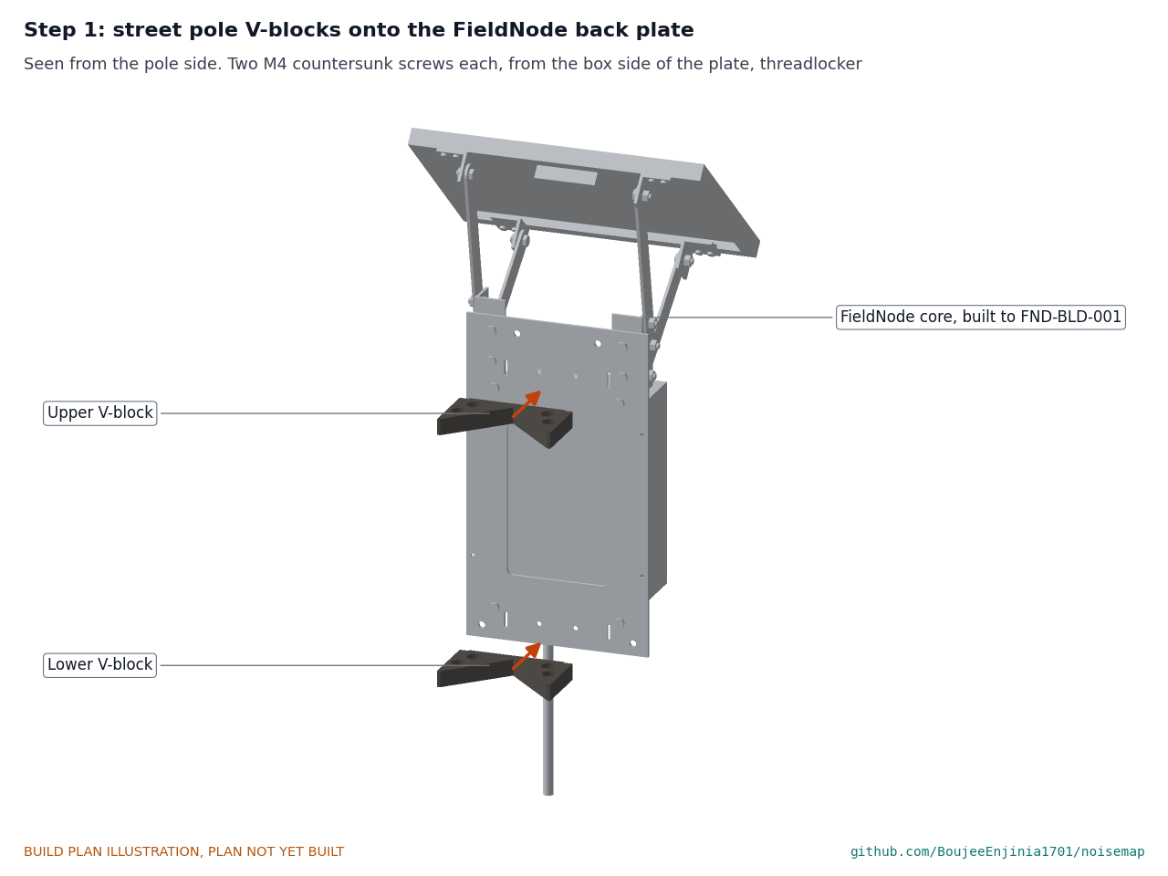
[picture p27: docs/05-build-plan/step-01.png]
Step 1


Seen from the pole side. Two M4 countersunk screws per block from the box side of the plate, with threadlocker, snug. The V opens away from the plate.

### Step 2: microphone board and membrane

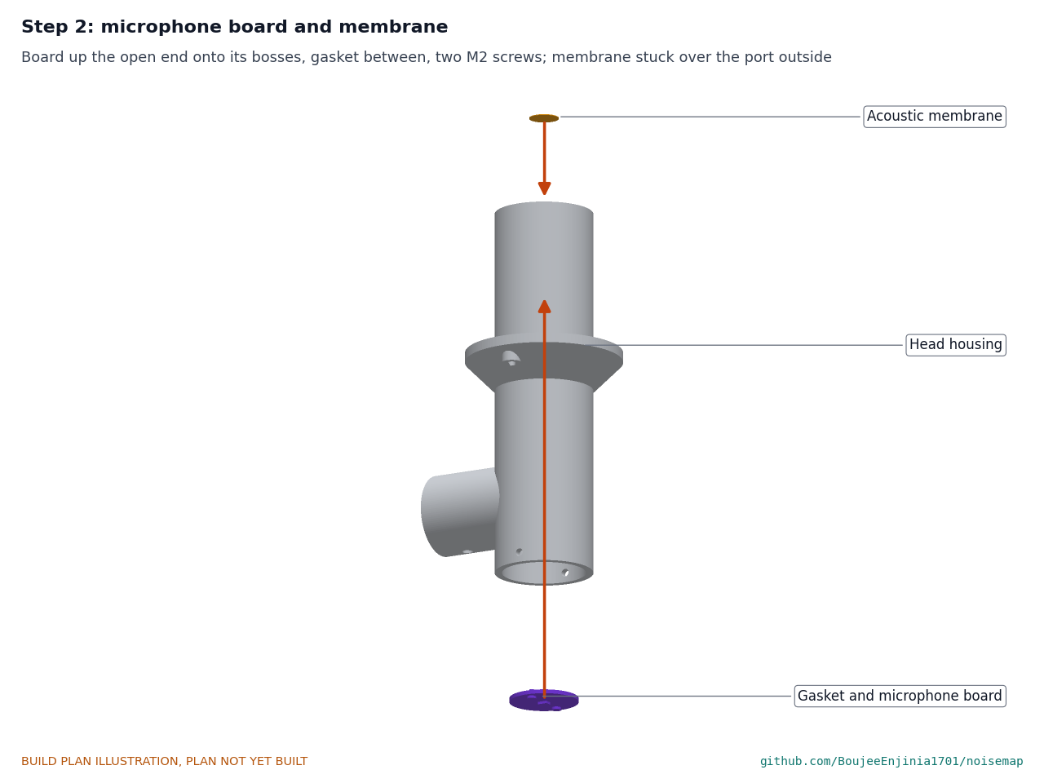
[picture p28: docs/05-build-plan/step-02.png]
Step 2


Gasket on the board, board up the open end onto its bosses, two M2 screws; membrane over the port outside (section 3.6).

### Step 3: processor board into the card guides

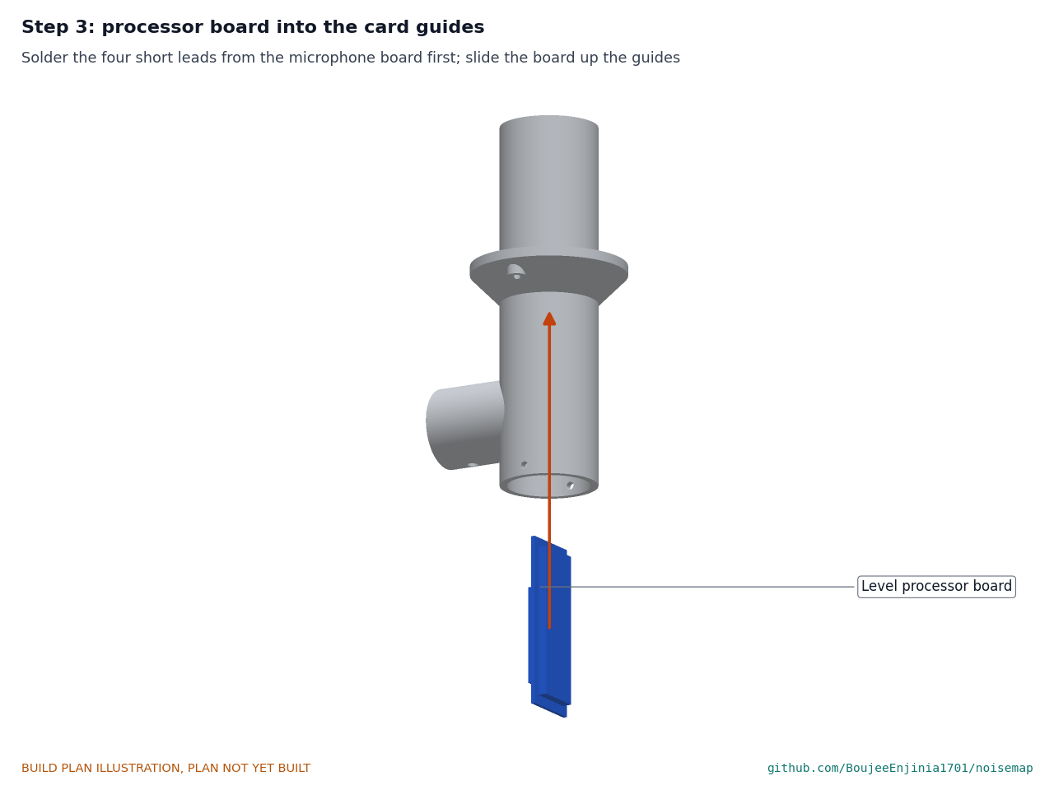
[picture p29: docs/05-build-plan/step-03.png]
Step 3


Solder the four leads from the microphone board first, then slide the board up the guides (section 3.7).

### Step 4: cable through the gland; cap into the head

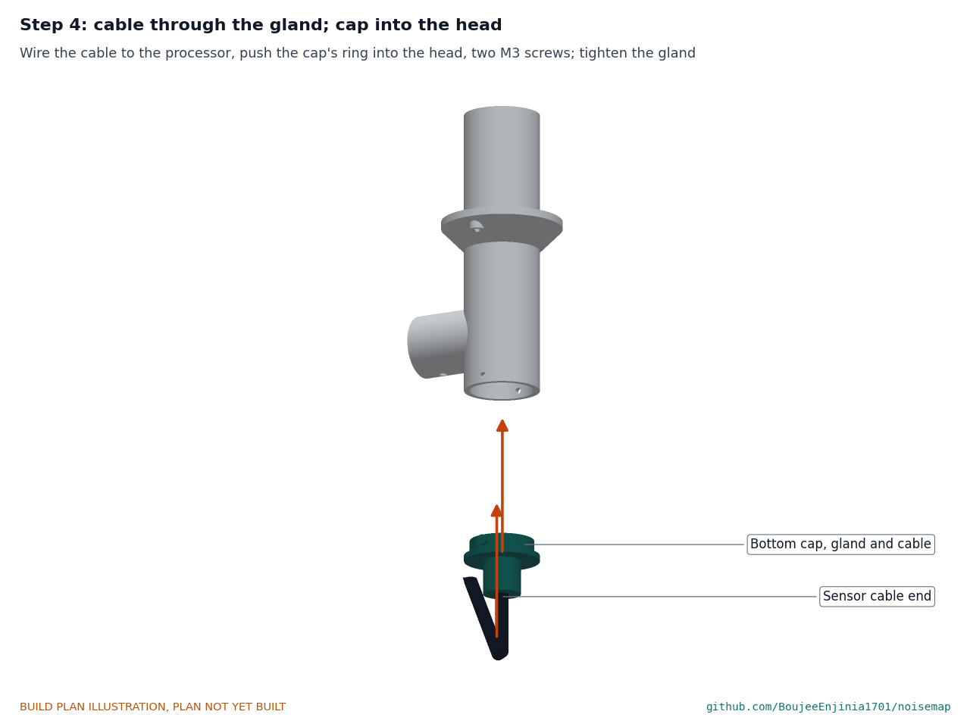
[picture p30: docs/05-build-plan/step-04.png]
Step 4


Wire the cable to the processor, push the cap's ring into the head, fit two M3 screws, tighten the gland (section 3.8). **Hold point:** the bench checks of section 5 on the head pass before going on.

### Step 5: tube flange onto the arm saddle

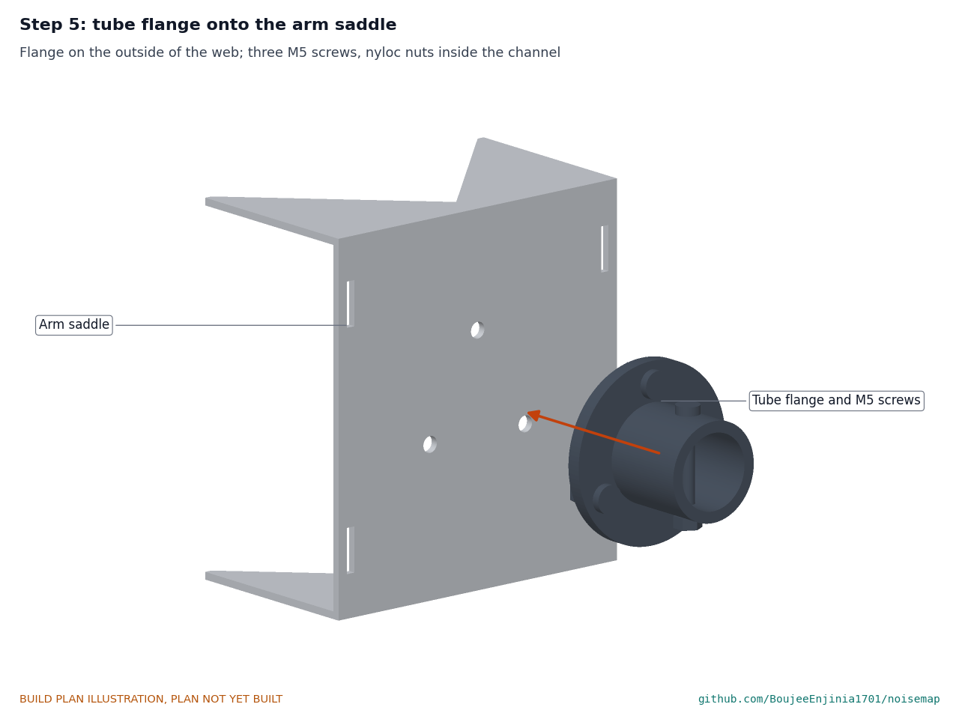
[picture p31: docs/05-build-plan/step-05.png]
Step 5


Flange on the outside of the web, centred between the band slots. Three M5 screws from the flange side, nyloc nuts inside the channel.

### Step 6: arm tube into the flange

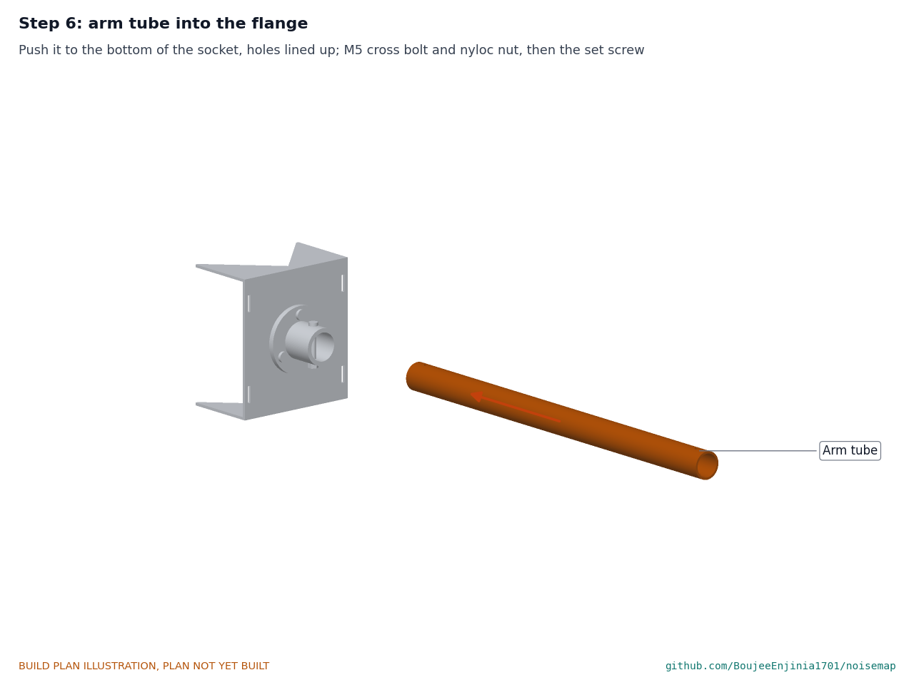
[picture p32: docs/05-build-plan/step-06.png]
Step 6


Push the pole end to the bottom of the socket with the holes lined up. M5 cross bolt and nyloc nut, then tighten the flange's set screw.

### Step 7: head onto the arm

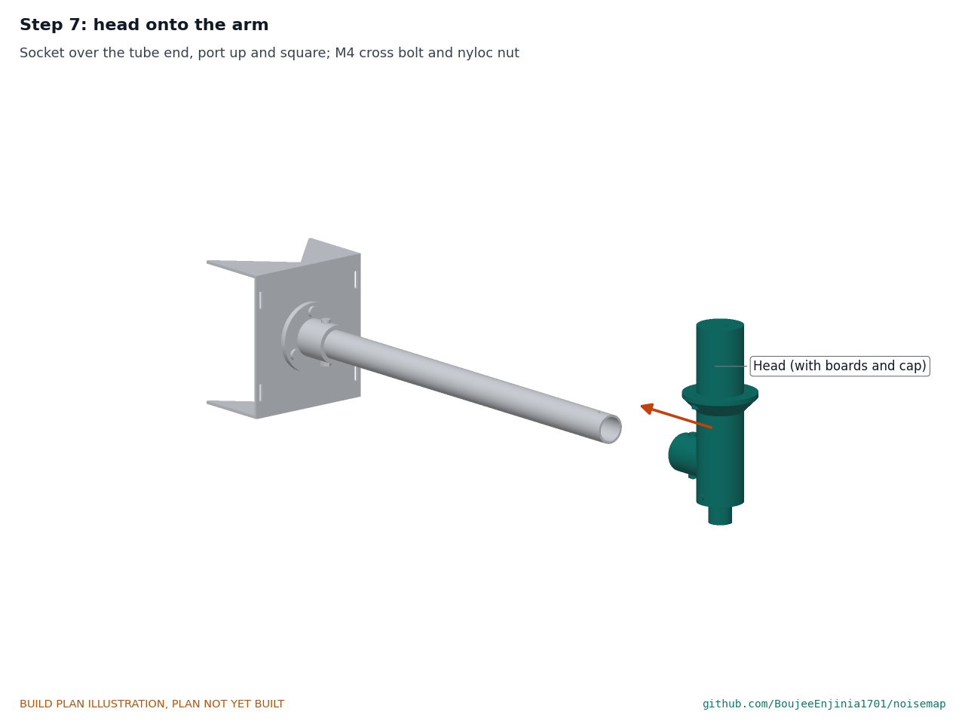
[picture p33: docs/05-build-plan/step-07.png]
Step 7


Slide the head's socket over the far end of the tube to the bottom, port up and square, the cable hanging below. M4 cross bolt and nyloc nut.

### Step 8: windscreen and bird spike

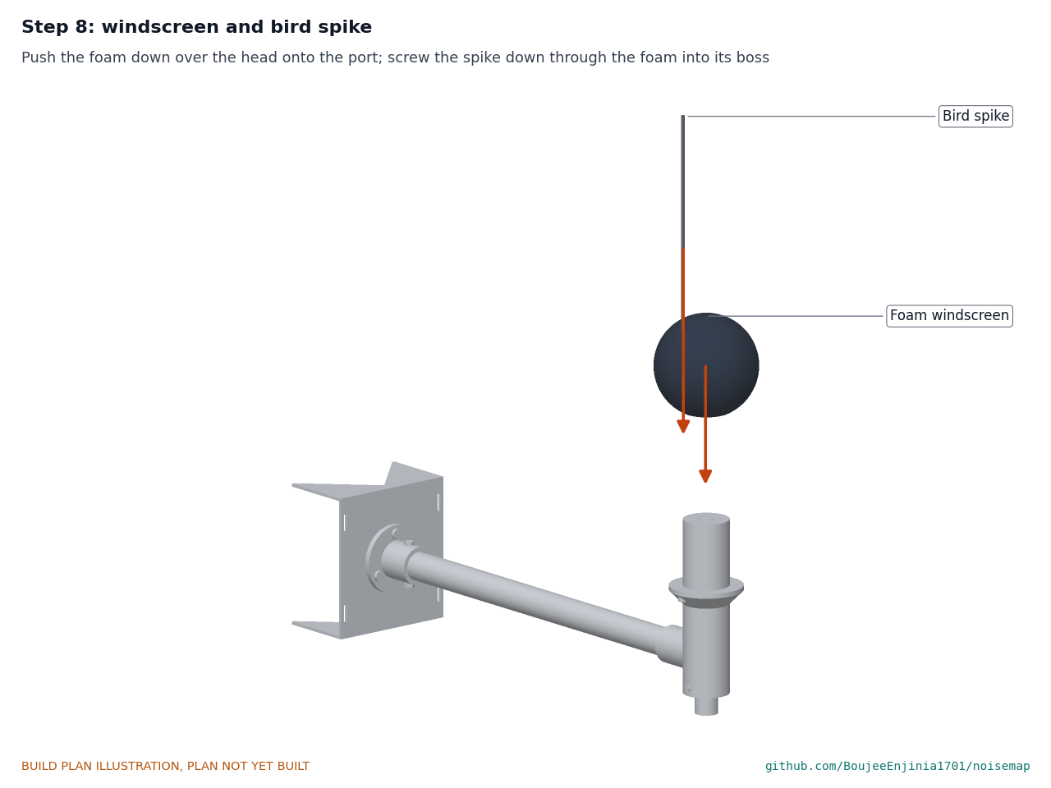
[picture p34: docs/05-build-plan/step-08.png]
Step 8


Push the foam down over the head onto the port, then screw the spike down through the foam into its insert, finger tight.

### Step 9: FieldNode core onto the pole

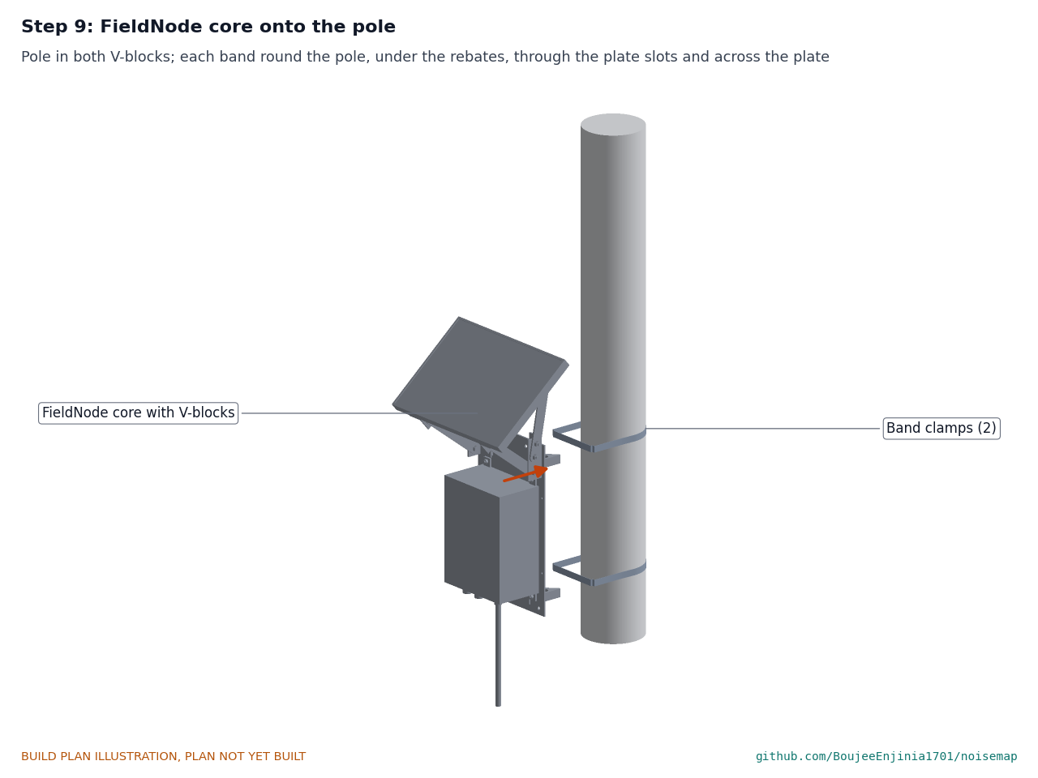
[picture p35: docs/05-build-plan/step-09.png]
Step 9


With a helper holding the core, sit the pole in both V-blocks. Pass each band round the pole, along the sides of its V-block, under the rebates, through the plate's two slots and across the box side of the plate, with the worm drive on the far side of the pole where a screwdriver reaches it. Tighten both bands to the band maker's torque and record it. **Hold point:** safety stop S2 in section 6.

### Step 10: arm saddle onto the pole

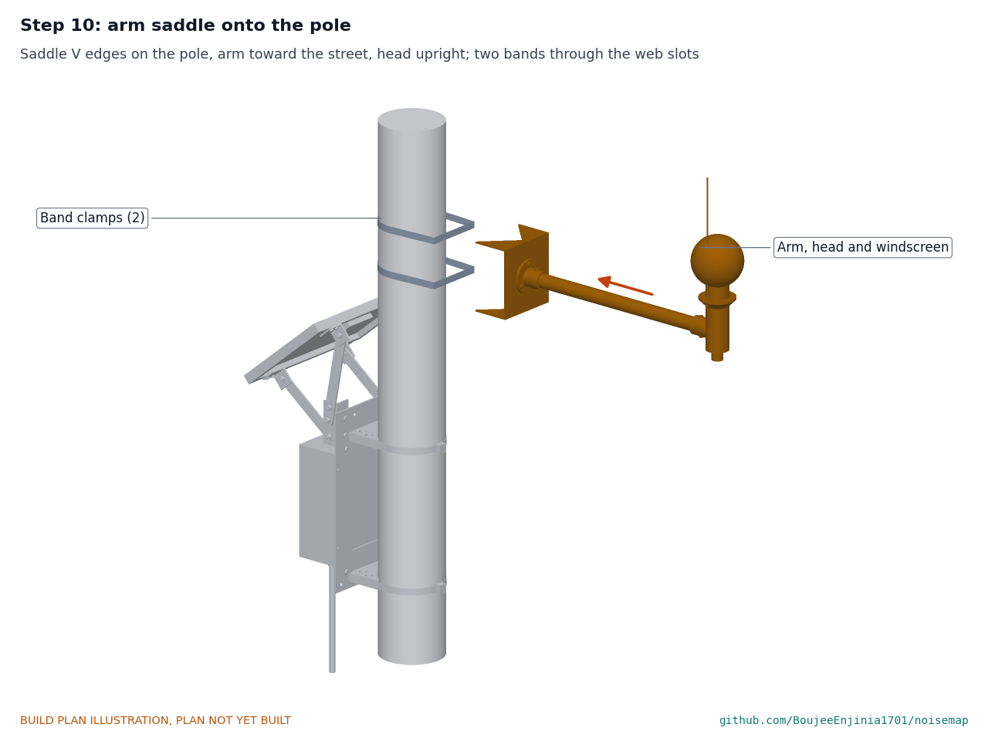
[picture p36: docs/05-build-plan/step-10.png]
Step 10


Hold the saddle's V edges on the pole above the core, the arm pointing away from the core and the head upright; on the stub, the saddle's lower flange is about 60 above the top of the panel. Pass each band round the pole, through the two web slots and across the outside of the web. Turn the arm to face the street, check the head is upright with a level, and tighten both bands to the maker's torque.

### Step 11: safety lanyard

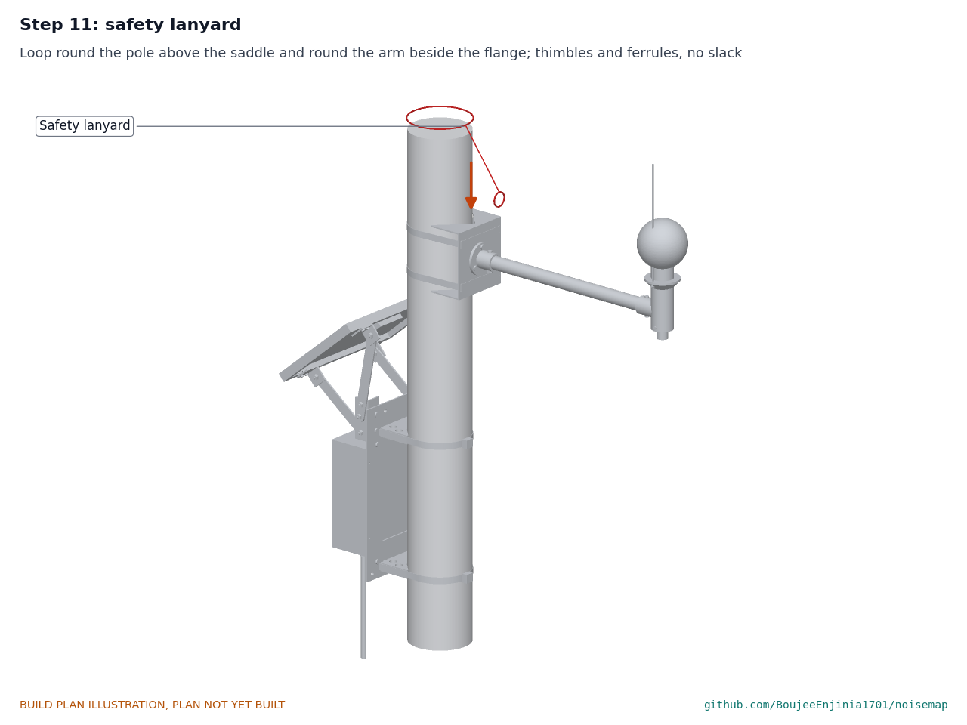
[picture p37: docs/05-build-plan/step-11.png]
Step 11


Loop the wire rope round the pole about 120 above the arm and round the arm beside the tube flange, each loop on a thimble closed with two ferrules, with no slack.

### Step 12: cable into port A and tied along

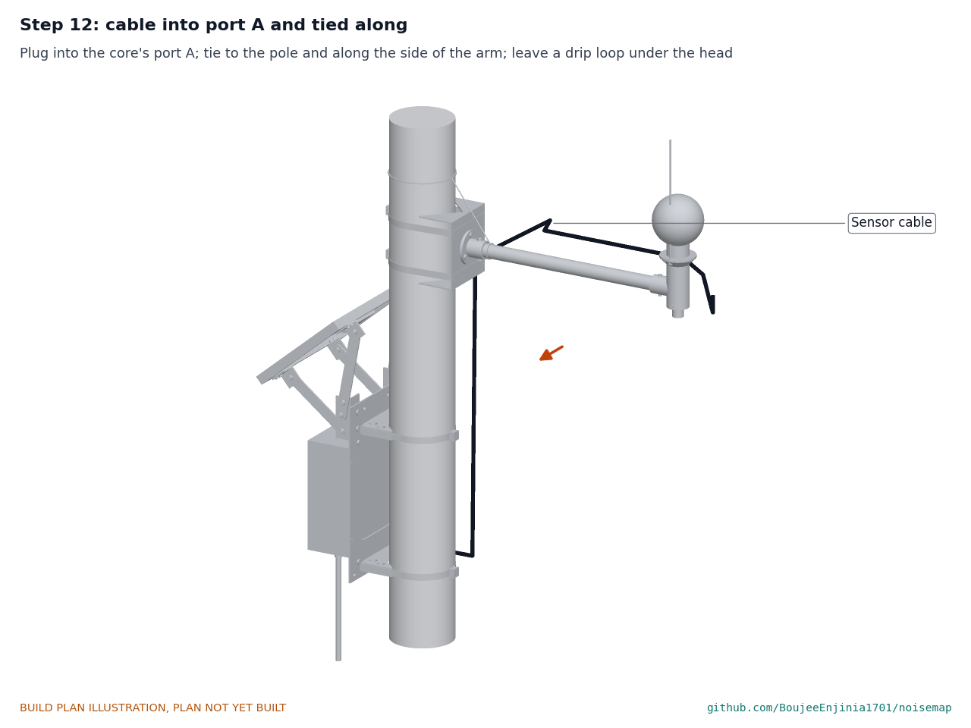
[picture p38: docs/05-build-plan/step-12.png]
Step 12


Before plugging in, check that port A is set to the 3.3 V rail and carries the 3.3 V label from the hardware line; stick the label beside the port if it is missing. Then plug the cable into the core's port A. Run it up the side of the pole away from the core, outside the saddle and along the side of the arm, and tie it every 150 or so with UV-stable ties. Leave a drip loop under the head so that rain runs off the loop, not into the gland.

## 5. First checks

These are the checks a TRL 4 test report would record; this plan only lists them. Requirement numbers are those of NSM-REQ-001.

*Table 2. First checks.*

| Check | Requirement | How | Pass when |
| --- | --- | --- | --- |
| Levels only on the cable | R1, R2 | Bench supply at 3.3 V on the cable, current limit 100 mA; watch the transmit line with a USB serial adapter | One 12-byte level frame a second and nothing else |
| Firmware build hash | R1 | Read the hash the head reports and compare it with the published build | They match; read-out protection is on |
| Microphone responds | R4 | A 94 dB, 1 kHz calibrator over the head, foam off | The head reports about 94 dB, steady |
| Port and membrane sealed | R8 | Look at the membrane and the cap under a lamp | No creases or gaps; the cap sits flat |
| Pole range | R10 | Seat the core's V-blocks and the arm saddle on 60, 114 and 140 mm tubes | Both V faces of each block and all four saddle edges touch; every band closes with adjustment to spare |
| Band torque | R10 | Torque screwdriver on each of the four bands | The maker's torque is reached without slipping; value recorded |
| Head upright and arm firm | R10 | Level on the head; push the head by hand up, down and sideways | Port level within 2°; nothing moves at any joint |
| Mass | R10 | Weigh the node, arm and head included | 3.5 kg or less (3.45 kg estimated) |
| Calibration check time | R9 | Time unscrewing the spike, lifting the foam, fitting the calibrator and refitting both | 10 minutes or less |

## 6. Safety stops

Stop at each point. Carry on only when everything listed is true.

- **S1. Before the cable is powered.** The head wiring is checked against Figure 13 with a meter; 3.3 V is on M12 pin 1 and ground on pin 3, and they are not swapped; the bench supply is limited to 100 mA. The FieldNode cell stays out until the FieldNode plan's own stops pass.
- **S2. Before the node goes on the pole stub.** Every screw and bolt tight with its nyloc nut or threadlocker; edges deburred; all four bands through their slots. The stub is clamped in a stand that cannot tip under the node's 3.5 kg held 0.5 m off its axis.
- **S3. Before any calibrator or loudspeaker test.** Hearing protection on; the calibrator's level is the 94 dB setting.
- **S4. Before any outdoor installation (outside this plan).** The pole owner's written permission; a lift or a stable ladder with a second person; fall protection and traffic management; clear of overhead lines and the pole's electrical hatch; the owner has checked the pole can take about 96 N of added wind load 3.5 to 4 m up; the lanyard fitted; a public notice on the pole saying what is measured.

## 7. Tools, skills and workspace

**Tools.** Hacksaw with a 24 teeth per inch blade (or a bandsaw); bench vice with soft jaws; bench drill with a V-block; drills 2.5 to 14 mm; countersink; M4 tap and tap drill; M3 die; flat and half-round files; deburring tool; scriber, engineer's square, 45° square, steel rule and calipers; tin snips or a jigsaw with a metal blade; 3D printer with an enclosure that prints ASA; soldering iron with a heat-set insert tip; wire strippers; multimeter; bench power supply with a current limit; USB serial adapter at 3.3 V; torque screwdriver covering about 1 to 6 N·m; spirit level; scale to 5 kg; stopwatch. A local bending shop bends the arm saddle.

**Skills.** No certified trade is needed. Basic metalwork (marking out, sawing, filing, drilling, tapping, threading), 3D printing, fine soldering, and loading firmware onto a microcontroller board. All circuits in the head are 3.3 V from the FieldNode; no mains wiring is part of this build.

**Workspace.** A bench about 1.2 x 0.6 m; a metalwork corner kept apart from the electronics; a ventilated place for the printer; a stand that holds a 1.2 m length of 114 mm tube upright.

**Personal protective equipment.** Safety glasses for cutting, drilling and soldering; cut-resistant gloves for bar and sheet; hearing protection when sawing and during calibrator tests; no gloves near a turning drill.

## 8. Where the numbers come from

- Model and constructability checks: `cad/src/model.py` (`python cad/src/model.py --check`), with the FieldNode core from `cad/src/fieldnode_core.py`; STEP and STL exports in `cad/step/` and `cad/stl/`.
- Pictures: `cad/src/build_plan_media.py`, using `.kit/build_views.py`; written to `docs/05-build-plan/` and `cad/drawings/NSM-DWG-101` to `NSM-DWG-106`.
- General arrangement: `cad/drawings/NSM-DWG-001.pdf`, Rev P3.
- Calculations: `docs/04-calcs/01-sizing.md` (NSM-CAL-001 v0.3) and `docs/04-calcs/sizing.py`; mass [H1], [H2], arm [H3] to [H6], pole fit [H8], cost [I1], [I2].
- Bill of materials: `bom/bom.csv`.
- Decisions: `docs/decisions/0003-design-for-construction.md` (NSM-DDR-003), with NSM-DDR-001 and NSM-DDR-002; the FieldNode core's own build plan FND-BLD-001 and decision record FND-DDR-003 in the FieldNode repository.
- Requirements: `docs/03-requirements.md` (NSM-REQ-001).

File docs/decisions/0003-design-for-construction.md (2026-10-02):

---
doc_id: NSM-DDR-003
title: NoiseMap design for construction
project: NoiseMap
doc_type: Design decision record
version: "0.2"
status: Draft
date: '2026-10-02'
author: Amish Chadha
license: CERN-OHL-S-2.0
revisions:
- version: "0.1"
  date: '2026-10-01'
  author: Amish Chadha
  change: Changes that make the concept physically buildable, with the reason for each; made under Amish's 2026-09-30 instruction and open for his review
- version: "0.2"
  date: '2026-10-02'
  author: Amish Chadha
  change: Accepted by Amish, including the recommendations for A1 and A2
---

# 0003: Design for construction

- **Date:** 2026-10-01
- **Status:** accepted. Amish, 2026-10-02: "i approve your recommendations for all 555 open decisions." This covers every change in Tables 1 and 2 and the recommendations for A1 and A2 in Table 3, now decided as recommended and recorded in the design decisions register (NSM-DEC-001). Every change was made under Amish's 2026-09-30 instruction to make the design physically buildable.

## Context

On 2026-09-30 Amish approved the build plan format and asked for it across all repos, and wrote: "If you are realising that the design cannot be built as per concept - fix the design assumptions to match and be physically feasible as you draw the illustrations." The NoiseMap model of NSM-DDR-002 showed what the node does but was a massing model: several parts could not be made by the stated process, or had no fixing, and the FieldNode core inside it was the old FieldNode concept rather than the constructable FieldNode accepted under FND-DDR-003.

The changes keep what NoiseMap does: the microphone port 4.0 m up, 0.45 m from the pole face and pointing up; the 3 mm port and 0.5 mm front cavity that the frequency response calculation rests on; the 90 mm windscreen; levels only over the M12 cable; the standard FieldNode core; 60 to 140 mm poles with no drilling of the pole; the core and the arm turning independently. Nothing here changes the pitch or the safety case. Every change is in `cad/src/model.py`, which now runs 62 constructability checks (`python cad/src/model.py --check`): parts that must touch do touch, parts that must stay apart are apart by the stated clearance, no NoiseMap part overlaps another, and the V contacts of a 60 mm and a 140 mm pole stay inside the V-blocks and the saddle. All 62 pass.

## Decision

*Table 1. Changes made to the model, the BOM and the calculations.*

| # | Problem in the concept | Change made | Why this way |
| --- | --- | --- | --- |
| P1 | The FieldNode core was the old FieldNode massing model: a tube bracket standing on the lid, no fixing between the box and the back plate, ports in one row. FieldNode has since been made constructable (FND-DDR-003, accepted by Amish on 2026-09-30). | The core is now the constructable FieldNode of FND-DWG-001 Rev P3, copied unchanged into `cad/src/fieldnode_core.py` and set out from the street pole. It is built to its own plan, FND-BLD-001, without its small-pole V-blocks and band clamps, which a street pole node does not fit. | One design for the core across the portfolio; the FieldNode build plan already shows how to make it. |
| P2 | Street pole V-blocks 110 x 60 x 40 mm pocketed from top and bottom to 4 mm walls and an 8 mm web: a CNC milling job, not a workshop one. No fixing to the back plate was shown, and the bands were drawn as rings cut short at the blocks, with no path to anything. | V-blocks 112 x 63 x 16 mm sawn from 70 x 16 mm bar, with a true 90 degree V (106 mm mouth, point 10 mm from the back face) and four 14 mm drilled lightening holes. Each is held by two M4 countersunk screws in FieldNode's own V-block screw holes (18 mm each side of centre). Each band runs round the pole, along the block's sides, under a 9 x 2 mm rebate at each back corner, through FieldNode's own band slots (51 mm each side) and across the box side of the plate. | Sawing, filing and drilling only. The FieldNode back plate needs no new holes. The pole sits where the concept put it, so every load and the core's position are unchanged. 16 mm bar and the holes keep the mass of the pocketed blocks. A band cannot pass the FieldNode slots without the rebates, because the blocks are wider than the slot spacing. |
| P3 | Arm saddle: a 10 mm plate 60 x 90 mm with a 6 mm milled pocket on the pole side (a milling job), seating a 60 mm pole on the pocket floor so it could rock; one band, drawn as a ring cut short at the saddle. | A channel bent from 2.5 mm 5052-H32 sheet, 114 mm wide, web 124 mm tall, flanges standing 65 mm out, each flange cut with a 90 degree V (109 mm mouth). Two bands, 40 mm above and below the arm, run round the pole, through slots in the web and across its outside. | A bending shop can make it. The pole bears on four V edges at every size from 60 to 140 mm. Two bands resist twist with a factor of 9.4 (one band: 4.2) [NSM-CAL-001 H6]. |
| P4 | The arm tube was butted against the saddle with no fixing; only welding could join them. | A bought aluminium tube flange (railing floor flange) bolted to the web with three M5 screws, nyloc nuts inside the channel; the tube goes 25 mm into its socket and an M5 cross bolt passes through both. | Bought part, hand tools only, and the arm can be taken off the saddle. |
| P5 | At the head, the tube ended against a collar ring round the head with no fixing. | An arm socket printed on the head housing (33 mm OD, 25 mm deep); the tube goes to the bottom of it and an M4 cross bolt passes through both. The arm tube is now 383 mm between the two sockets. | One printed part instead of two, and the head is held square to the arm. The microphone position is unchanged. |
| P6 | Inside the head, the processor board and the microphone board floated; the bottom was open, and the cable was to enter "through a gland" that the model did not have. | Two printed card guides hold the processor board. The microphone board is held by two M2 screws on two printed bosses under the top plate, with a 0.5 mm closed-cell gasket round the port that forms the 3 mm, 0.5 mm deep front cavity. A printed bottom cap with an M16 cable gland closes the bottom, held by two M3 screws through the head wall. | Every part inside the head now has a fixing. The gasket keeps the front cavity the calculations use, so the 36.2 kHz port resonance stands [NSM-CAL-001 B3]. |
| P7 | The drip skirt was a flat 12 mm overhang that a printer cannot make without support. | The same 64 mm skirt, a 4 mm rim with a 45 degree cone under it. | Prints without support; sheds water the same way. |
| P8 | The windscreen was bored 41 mm for a 40 mm head, so nothing held it. | Bored 40 mm, pushed down over the head until it sits on the port membrane. | The foam grips the head; same 90 mm ball and position. |
| P9 | The bird spike stood in the top of the foam with nothing holding it. | A 3 mm stainless rod with an M3 thread, screwed into a heat-set insert in a boss on the skirt 26 mm from the head axis; it rises through the foam to 160 mm above the port, the height the concept gave. Unscrew it before lifting the windscreen off. | It has a fixing and keeps birds off the ball. Its effect on the response is open (Table 3, A1). |
| P10 | The safety lanyard was in the BOM but had no attachment. | A 2 mm stainless wire rope with thimbles and ferrules, looped round the pole above the saddle and round the arm beside the flange. | It holds the arm if the bands slip. |
| P11 | The sensor cable ran through other parts and had no route. | It runs from the core's port A down below the back plate, up the pole on the side away from the core, outside the saddle, along the side of the arm and into the gland from below with a drip loop, tied to the pole and the arm. | A real path, clear of every part [model checks]. |

*Table 2. Knock-on changes.*

| Item | Change | Reason |
| --- | --- | --- |
| Mass | 3.45 kg, unchanged, against R10's 3.5 kg; margin 0.05 kg [NSM-CAL-001 H2]. | The second band, flange, cap, gland and fixings added mass; leaving off FieldNode's small-pole V-blocks and bands (0.22 kg) and the lighter V-blocks paid for it. |
| Cost | BOM lines 1 to 6 follow the FieldNode BOM after FND-DDR-003 ($126.00 to $139.00). Lines 7, 8, 12 and 13 repriced. NoiseMap parts $62.00 to $72.00; value-engineering target $100, so $28.00 under; full node $211.00 [I1], [I2]. `budget_usd` unchanged. | Parts added for construction. |
| Arm and clamp | Arm stress factor 24 to 27, clamp twist factor 4.2 to 9.4, 96 N added to the pole (was 97 N) [H3] to [H7]. | Shorter tube, two bands. |
| Drawing | NSM-DWG-001 Rev P2 to P3; making sketches NSM-DWG-101 to 106 added. | Follows the model. |
| Documents | NSM-CAL-001 v0.3; NSM-PRC-001 and NSM-REQ-001 updated for the new figures. No requirement changed status. | Follows the model. |

*Table 3. Proposed for Amish; A1 and A2 accepted as recommended on 2026-10-02.*

| # | Question | Options | Recommendation |
| --- | --- | --- | --- |
| A1 | The bird spike now stands 26 mm off the microphone axis instead of on it, inside the windscreen. A 3 mm rod that close may change the response slightly at the highest frequencies. | (a) the side spike as modelled, and measure the response with and without it at TRL 4; (b) no spike, and replace the foam more often; (c) a spike on a wire hoop clipped to the skirt, clear of the foam. | (a): it is the simplest fixing, and the response is already to be measured at TRL 4 (R5 at risk). Accepted by Amish, 2026-10-02. |
| A2 | The R10 mass margin is still 0.05 kg on catalogue masses. | (a) accept, weigh the prototype at TRL 4; (b) look for more mass now (a 2 mm saddle saves about 0.03 kg). | (a). Accepted by Amish, 2026-10-02. |

## Consequences

- `design_state: constructable` in `project.yaml`. The build plan NSM-BLD-001 shows every component and step in pictures generated from the model (`cad/src/build_plan_media.py`); decisions are indexed in the design decisions register NSM-DEC-001.
- With A1 and A2 accepted, the side spike stays as modelled and its effect on the response is measured at TRL 4, and the prototype is weighed at TRL 4 against R10.
- Requirement status is unchanged: 0 not met, 3 at risk (R3, R4, R5), 4 not verifiable at TRL 3, 4 met on paper, 4 met by design (NSM-CAL-001 v0.3).
- The photoreal renders (`media/render-*.png`), `media/card.png`, `media/social-preview.png` and the appearance model `cad/src/product_model.py` still show the concept arm saddle, V-blocks, head and FieldNode bracket; they need updating on Amish's Mac, where Blender is.
- If FieldNode changes its back plate, the V-block screw holes, the band slots or the clamp heights, the street pole V-blocks must follow, and `cad/src/fieldnode_core.py` must be copied again.

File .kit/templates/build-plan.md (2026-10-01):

---
doc_id: PRJ-BLD-001
title: Project prototype build plan
project: Project name
doc_type: Build plan
version: "0.1"
status: Draft
date: YYYY-MM-DD
author: Amish Chadha
license: CERN-OHL-S-2.0
revisions:
  - version: "0.1"
    date: YYYY-MM-DD
    author: Amish Chadha
    change: First build plan; design made constructable
---

# Project prototype build plan

**Plan, not yet built.** How to build the first proof-of-concept prototype, component by component. Building and testing to it is TRL 4 work. Decisions still to be made are kept in the design decisions register (`docs/06-design-decisions.md`), not here.

## 1. What you are building

Every component, pulled apart and numbered in build order

One short paragraph: what the prototype is, how many components, which are made and which are bought, and the main ways they are made.

## 2. What changed to make it buildable

| Component | The concept had | The buildable design has | Why |
| --- | --- | --- | --- |

## 3. Making the components

### 3.1 Component name

Making sketch

**What it is and what it is made from.**

**How to make it.**

1. Mark out ...
2. Cut ...

**How it fits the parts next to it.**

Close-up of the joint

**Check before moving on.**

## 4. Putting it together

### Step 1: ...

Step 1

## 5. First checks

| Check | Requirement | How | Pass when |
| --- | --- | --- | --- |

## 6. Safety stops

## 7. Tools, skills and workspace

## 8. Where the numbers come from

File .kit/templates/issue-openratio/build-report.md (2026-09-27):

---
name: Build report
about: Tell us what happened when you built, printed or tested part of this design
title: "Build report: "
labels: build-report
---

This is a research and educational prototype, not a medical device. It is a TRL 3 concept and is not released for fabrication. If you build any part of it, you do so at your own risk. Reports help everyone.

**What you built** (part, sub-assembly or test)

**Materials, tools and settings**

**What worked**

**What did not work, with photos or measurements if you have them**

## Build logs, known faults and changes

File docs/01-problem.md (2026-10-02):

---
doc_id: NSM-PRB-001
title: NoiseMap problem statement
project: NoiseMap
doc_type: Problem statement
version: "0.6"
status: Draft
date: '2026-10-02'
author: Amish Chadha
license: CERN-OHL-S-2.0
revisions:
- version: "0.1"
  date: '2026-09-25'
  author: Amish Chadha
  change: Initial scaffold
- version: "0.2"
  date: '2026-09-25'
  author: Amish Chadha
  change: Populate to TRL 2 (problem, users, context, constraints, prior work, open questions)
- version: "0.3"
  date: '2026-09-25'
  author: Amish Chadha
  change: TRL 3; budget scope, privacy wording and open questions updated per NSM-DDR-001
- version: "0.4"
  date: '2026-09-25'
  author: Amish Chadha
  change: Recommendations accepted by Amish (DDR-002)
- version: "0.5"
  date: '2026-10-01'
  author: Amish Chadha
  change: Cost figures from NSM-CAL-001 v0.3; budget as a value-engineering target
- version: "0.6"
  date: '2026-10-02'
  author: Amish Chadha
  change: First co-design partner to approach, decided on 2026-10-02 (NSM-DEC-001)
---

# NoiseMap problem statement

Traffic and nightlife noise harm sleep and health, but most cities know their noise levels only from computer models updated every few years, and residents who complain have no measurements of their own. The gap is a low-cost, open street node that measures sound levels continuously and, by design, never records or sends audio.

## The problem

Environmental noise is a large and well-documented health burden. In Europe, road traffic is the main source: about 92 million people in the EU are exposed to harmful day-evening-night road traffic noise, and long-term exposure to transport noise is linked to about 66,000 premature deaths and about 50,000 new cases of cardiovascular disease each year ([EEA](https://www.eea.europa.eu/en/topics/in-depth/noise)). The WHO recommends keeping road traffic noise below 53 dB Lden and 45 dB Lnight, stricter than the 55 dB Lden and 50 dB Lnight thresholds used for EU reporting ([EEA, citing WHO 2018](https://www.eea.europa.eu/publications/health-risks-caused-by-environmental)). In the United States, the EPA identified 55 dB outdoors as the level that prevents activity interference and annoyance as long ago as 1974 ([US EPA](https://www.epa.gov/archive/epa/aboutepa/epa-identifies-noise-levels-affecting-health-and-welfare.html)).

Measurement lags far behind. The EU Environmental Noise Directive requires strategic noise maps for large agglomerations, reviewed at least every five years, using the Lden and Lnight indicators ([Directive 2002/49/EC](https://eur-lex.europa.eu/legal-content/EN/TXT/HTML/?uri=CELEX:32002L0049)). These maps are mostly calculated from traffic models, so they show long-term averages well but miss what residents complain about: bar and club noise at 2 a.m., delivery trucks before dawn, construction, and street events. Most cities outside Europe have no maps at all.

Complaints are frequent but carry little evidence. When the SONYC team described their network in 2018, New York City's 311 line had logged more than 2.3 million noise complaints since 2010, more than for any other issue ([Bello et al., SONYC](https://arxiv.org/abs/1805.00889)). An officer who arrives an hour later often finds the noise has stopped. A resident with a phone app has an uncalibrated reading from inside a flat, which a licensing hearing can dismiss.

Continuous monitoring exists but is costly or intrusive. Certified class 1 monitoring terminals are priced for agencies and are deployed a few at a time. Research networks have shown low-cost sensors work, but some record short audio clips to identify sources (the SONYC nodes sampled 10-second clips at random, encrypted, during a limited period), and any microphone on a pole raises the fear that it is listening to conversations.

## Users and context

| User | Need | Context |
| --- | --- | --- |
| Residents and residents' associations | Credible, continuous evidence of night-time noise near their homes, from a device they can inspect | Streets with bars, clubs, markets, delivery routes |
| City environmental health or noise team | Low-cost measurement to target enforcement and check complaints | Nightlife districts, construction sites, depots |
| Transport and planning departments | Before and after evidence for traffic calming, low-noise surfaces, speed limits and truck routes | Main roads, school streets |
| Licensing authorities and venue operators | Shared, trusted data to set and check conditions on late licences | Entertainment districts |
| Researchers and students | Open, documented level data linked to health, sleep and urban form studies | Universities, public health programs |
| Pole or asset owner | A light clamp-on device that needs no drilling or mains connection | Street lighting and signal poles |

Operating context: clamped to an existing street pole with the microphone about 4 m above the ground (the 4.0 ± 0.2 m assessment height the EU uses for strategic noise maps, [Directive 2002/49/EC, Annex I](https://eur-lex.europa.eu/legal-content/EN/TXT/HTML/?uri=CELEX:32002L0049)), outdoors for years in sun, rain, dust, wind and temperatures from about -20 °C to +50 °C (estimate of the design range), usually with no daytime power at the pole.

## Constraints

- Garage-buildable prototype. The $100 value-engineering target covers the NoiseMap parts, estimated at $72.00; the FieldNode core is costed in the FieldNode repo ($139.00), so a full node is about $211 (NSM-DDR-001 D1, NSM-CAL-001).
- Built on the lab's shared **FieldNode** power and radio core, as the FieldNode README lists NoiseMap among its intended users.
- Privacy by design: no images, audio recordings or personal identifiers leave the device; only sound levels are stored or sent. The guarantee rests on open, auditable head firmware with read-out protection and a published build hash, not on the data links alone (NSM-DDR-001 D2).
- Clamp-on mounting with no drilling, welding or electrical connection to the pole.
- Open hardware (CERN-OHL-S-2.0) and open firmware (MIT), so any city or residents' group can audit what the device measures.
- Measurements should follow the definitions of IEC 61672-1 for sound level meters ([IEC](https://webstore.iec.ch/en/publication/5708)) where practical, but the node is not a certified instrument and must not be presented as one.

## Prior work

- **Sensor.Community DNMS.** An open Digital Noise Measurement Sensor that reads an ICS-43434 MEMS microphone over I²S, or an IM72D128 through a PDM to I²S converter, on a Teensy board and reports LAeq, LAmin and LAmax to the Sensor.Community network through an ESP8266 ([DNMS on GitHub](https://github.com/hbitter/DNMS)). It is mains or USB powered and uses Wi-Fi, which suits balconies but not most street poles.
- **SONYC (Sounds of New York City).** A research network of low-cost acoustic sensors, about $80 in parts each, with 45 deployed in New York when described; it measured sound levels continuously and also sampled encrypted audio clips for machine listening ([Bello et al.](https://arxiv.org/abs/1805.00889)).
- **Bruitparif Méduse.** A four-microphone sensor used in Paris neighborhoods and on construction sites that measures levels and locates the main source directions several times a second ([Bruitparif](https://www.bruitparif.fr/la-meduse/)).
- **Certified monitoring terminals.** Class 1 instruments used by agencies and airports; accurate and traceable, but priced for a handful of sites.

No open, solar-powered, LoRaWAN street node that is designed never to store or transmit audio was found.

## Out of scope

- Recording, storing or transmitting audio in any form, including short clips for source identification.
- Identifying people, voices or conversations.
- Certified or legally binding measurement (class 1 or legally certified instruments).
- Indoor noise and occupational noise exposure.
- Enforcement actions based on the node alone.

## User research and co-design

This design is for communities the author is not part of, so requirements come from the people who will use it.

- [ ] Identify a local partner organization. First candidate to approach (decided 2026-10-02, not yet agreed): a city environmental noise team or a university acoustics group that can put a Class 1 reference sound level meter beside the node on the test street; a Sensor.Community group is a useful second contact for volunteer hosts
- [ ] Run co-design sessions with intended users; record who, where and what was learned
- [ ] Validate load, distance, terrain and cost assumptions in the field
- [ ] Revise requirements (REQ) from findings before freezing the design

## Open questions

- Which partner and street first? Decided by Amish on 2026-10-02 (NSM-DDR-001 O1): the first candidate to approach is a city environmental noise team or a university acoustics group that can put a Class 1 reference sound level meter beside the node on the test street; a Sensor.Community group is a useful second contact for volunteer hosts. Not yet agreed with any partner.
- 1-minute detail: fifteen 1-minute LAeq values in each 15-minute record. Decided by Amish, 2026-09-25: go with recommendation (NSM-DDR-001 D5).
- Low-frequency levels for amplified bass: LCeq in each record. Decided by Amish, 2026-09-25: go with recommendation (D5, D12).
- Public notice: a plate on each pole saying what is measured, with a link to this repository. Decided by Amish, 2026-09-25: go with recommendation (D8).

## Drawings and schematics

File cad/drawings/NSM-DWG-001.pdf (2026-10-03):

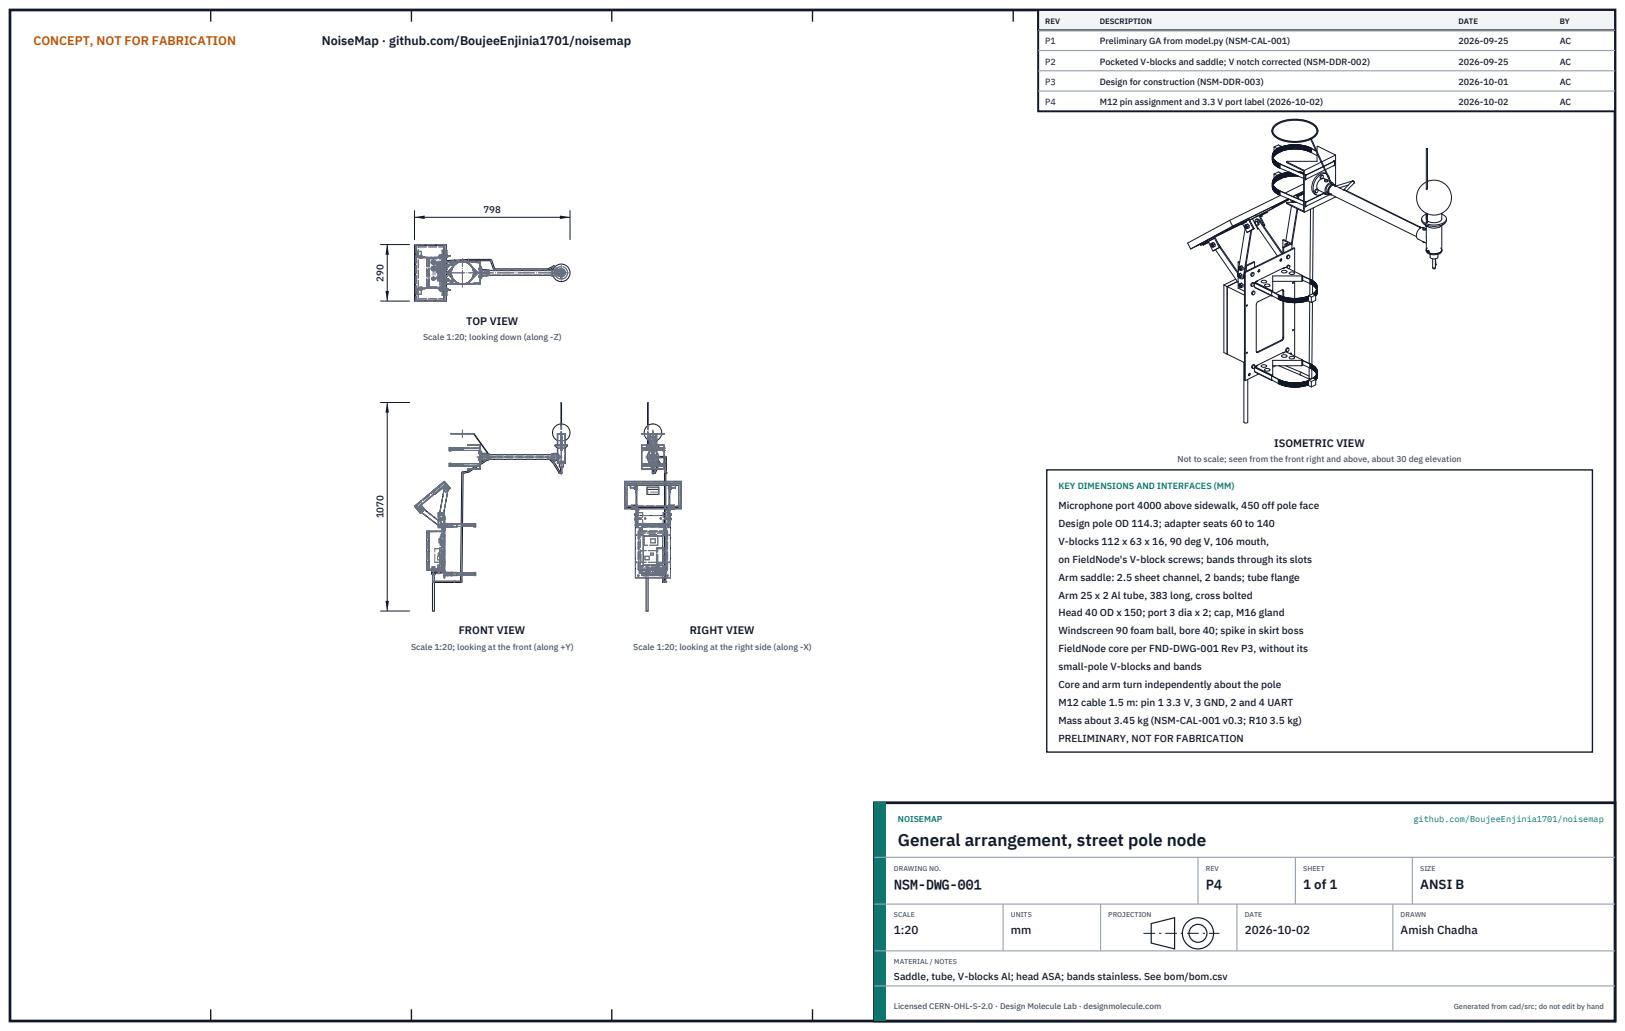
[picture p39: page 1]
CONCEPT, NOT FOR FABRICATION; NoiseMap · github.com/BoujeeEnjinia1701/noisemap; FRONT VIEW; TOP VIEW; RIGHT VIEW; ISOMETRIC VIEW; REV; DESCRIPTION; DATE; Preliminary GA from model.py (NSM-CAL-001); Pocketed V-blocks and saddle; V notch corrected (NSM-DDR-002); Design for construction (NSM-DDR-003); M12 pin assignment and 3.3 V port label (2026-10-02); NOISEMAP; github.com/BoujeeEnjinia1701/noisemap; DRAWING NO. NSM-DWG-001; REV P4; SHEET 1 of 1; SIZE ANSI B; SCALE 1:20; UNITS mm; PROJECTION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

Scale 1:20; looking down (along -Z)

Not to scale; seen from the front right and above, about 30 deg elevation

KEY DIMENSIONS AND INTERFACES (MM)
Microphone port 4000 above sidewalk, 450 off pole face
Design pole OD 114.3; adapter seats 60 to 140
V-blocks 112 x 63 x 16, 90 deg V, 106 mouth,
on FieldNode's V-block screws; bands through its slots
Arm saddle: 2.5 sheet channel, 2 bands; tube flange
Arm 25 x 2 Al tube, 383 long, cross bolted
Head 40 OD x 150; port 3 dia x 2; cap, M16 gland
Windscreen 90 foam ball, bore 40; spike in skirt boss
FieldNode core per FND-DWG-001 Rev P3, without its
small-pole V-blocks and bands
Core and arm turn independently about the pole
M12 cable 1.5 m: pin 1 3.3 V, 3 GND, 2 and 4 UART
Mass about 3.45 kg (NSM-CAL-001 v0.3; R10 3.5 kg)
PRELIMINARY, NOT FOR FABRICATION

Scale 1:20; looking at the front (along +Y)

Scale 1:20; looking at the right side (along -X)

General arrangement, street pole node

MATERIAL / NOTES
Saddle, tube, V-blocks Al; head ASA; bands stainless. See bom/bom.csv

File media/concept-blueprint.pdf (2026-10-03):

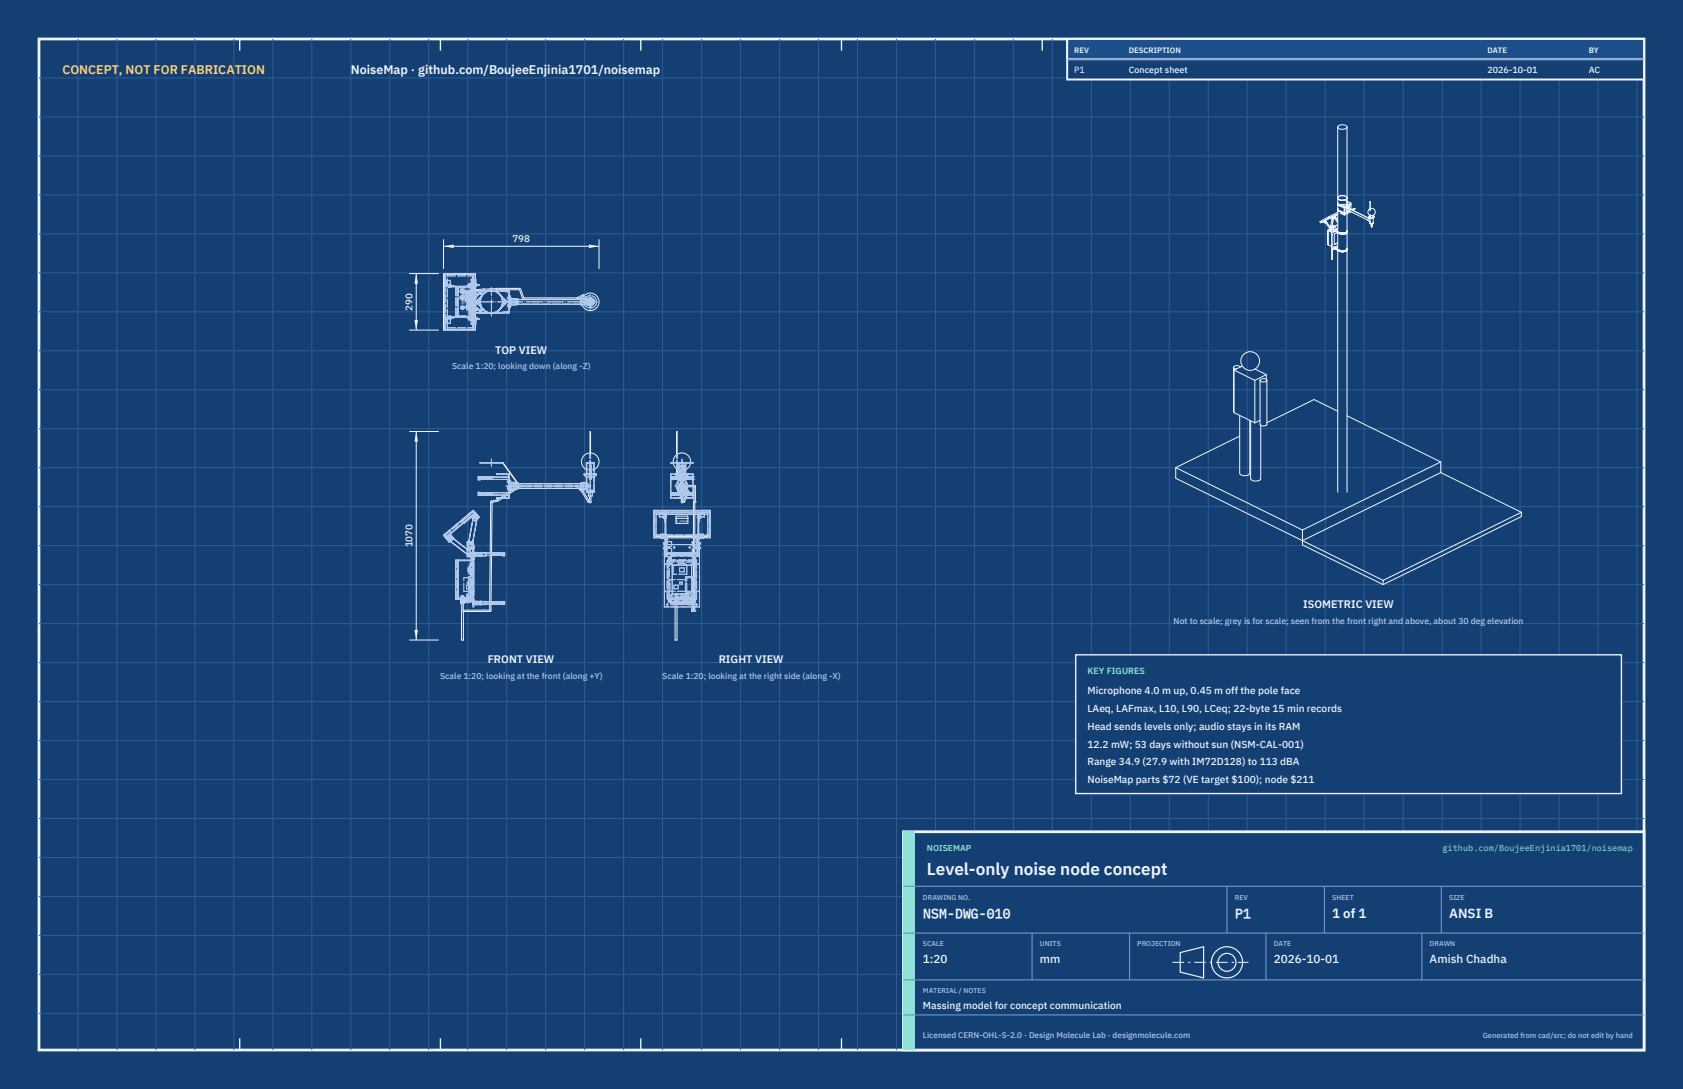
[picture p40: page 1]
CONCEPT, NOT FOR FABRICATION; NoiseMap · github.com/BoujeeEnjinia1701/noisemap; FRONT VIEW; TOP VIEW; RIGHT VIEW; ISOMETRIC VIEW; REV; DESCRIPTION; DATE; Concept sheet; NOISEMAP; github.com/BoujeeEnjinia1701/noisemap; DRAWING NO. NSM-DWG-010; REV P1; SHEET 1 of 1; SIZE ANSI B; SCALE 1:20; UNITS mm; PROJECTION; DRAWN Amish Chadha; Licensed CERN-OHL-S-2.0 · Design Molecule Lab · designmolecule.com; Generated from cad/src; do not edit by hand

Scale 1:20; looking down (along -Z)

Not to scale; grey is for scale; seen from the front right and above, about 30 deg elevation

KEY FIGURES
Microphone 4.0 m up, 0.45 m off the pole face
LAeq, LAFmax, L10, L90, LCeq; 22-byte 15 min records
Head sends levels only; audio stays in its RAM
12.2 mW; 53 days without sun (NSM-CAL-001)
Range 34.9 (27.9 with IM72D128) to 113 dBA
NoiseMap parts $72 (VE target $100); node $211

Scale 1:20; looking at the front (along +Y)

Scale 1:20; looking at the right side (along -X)

Level-only noise node concept

MATERIAL / NOTES
Massing model for concept communication

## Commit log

2026-09-25 Initial scaffold: standard open hardware layout, CERN-OHL-S v2 + MIT licenses
    Claude-Session: https://claude.ai/code/session_01XuhhSU4W6fYhgCfURbrkut
    [bom.csv]
2026-09-26 Populate to TRL 2: problem, requirements, precis, concept media, BOM and README use cases
    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
    [bom.csv]
2026-09-26 Advance to TRL 3: DDR-001, CAL-001 sizing, parametric model with STEP/STL, GA drawing, priced BOM; TRL 4 on hold
    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
    [bom.csv, noisemap-assembly.step, noisemap-assembly.stl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]
2026-09-26 Accept all recommendations (DDR-002), switch footer to designmolecule.com, add README write-up with new inspiration point
    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
    [bom.csv, noisemap-assembly.step, noisemap-assembly.stl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]
2026-09-27 Product appearance model and photoreal renders
    Adds cad/src/product_model.py (appearance model for renders only, all main
    dimensions from model.py) and Blender renders in media/render-*.png,
    captioned with the project, repository and viewing direction. README leads
    with the product render; trl stays 3.
    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
2026-10-01 Image quality pass: legible exploded views, flow diagrams and drawing sheets
    Kit 1.6.1 image layout: the parts list sits in its own column, number bubbles sit on visible parts and never overlap, small parts get a leader, pictures are cropped to the subject, flow labels keep numbers with their units, and sheet captions and the revision table no longer overprint. Concept images, blueprint and general arrangement sheet regenerated; repo-specific labels moved clear of other text and lines.
2026-10-01 Kit 1.7.0: constructable design, illustrated build plan and design decisions register
    The design is now constructable: every part can be made and fits its neighbours, with each change recorded in a Design for construction decision record (made under Amish's 2026-09-30 instruction; ope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
    FlexHand also credits Dr. Geeti Chadha as a contribut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
    [bom.csv, noisemap-assembly.step, noisemap-assembly.stl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]
2026-10-02 Record Amish's approval of the open-decision recommendations
    Amish approved the recommendation on every open decision in the design decisions register ("i approve your recommendations for all 555 open decisions.", 2026-10-02). Each decision is moved to Decisio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
2026-10-03 Carry approved follow-ups into the design and redo photoreal renders
    Amish approved the follow-up actions from the open-decision sign-off ("APPROVED CHANGES, COMPLETE THESE", 2026-10-02), the design-for-construction change tables in ten repos, the last wave's open dec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
    [bom.csv, noisemap-assembly.step, noisemap-head.step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]
2026-11-05 Kit 1.9.1 upgrade: pipeline documents and detailed CAD for every option
    STEM check with fixes under the standing instruction and an independent
    review, concept options scored against the user requirements, URS, PRS,
    RTM, REG, FEA, RSK, MKT, PLN and DDR, every option modelled at D3 with
    cad/fidelity.json passing, and the concept options picture rendered with
    Blender Cycles on Amish's Mac. Concept choices stay proposed, awaiting
    Amish.
    Claude-Session: https://claude.ai/code/session_01LppsZSzPTJWTBAV5wh1Goq
